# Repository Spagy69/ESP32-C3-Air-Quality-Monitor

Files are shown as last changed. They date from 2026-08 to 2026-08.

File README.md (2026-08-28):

# ESP32-C3 Air Quality Monitor

Bateriový monitor kvality vzduchu postavený na Seeed XIAO ESP32-C3, běžící na [ESPHome](https://esphome.io/) a integrovaný do Home Assistant. Měří CO₂, teplotu, vlhkost a tlak, s malým OLED displejem pro stav a tlačítkem pro probuzení / trvalé zapnutí.

<p align="center">
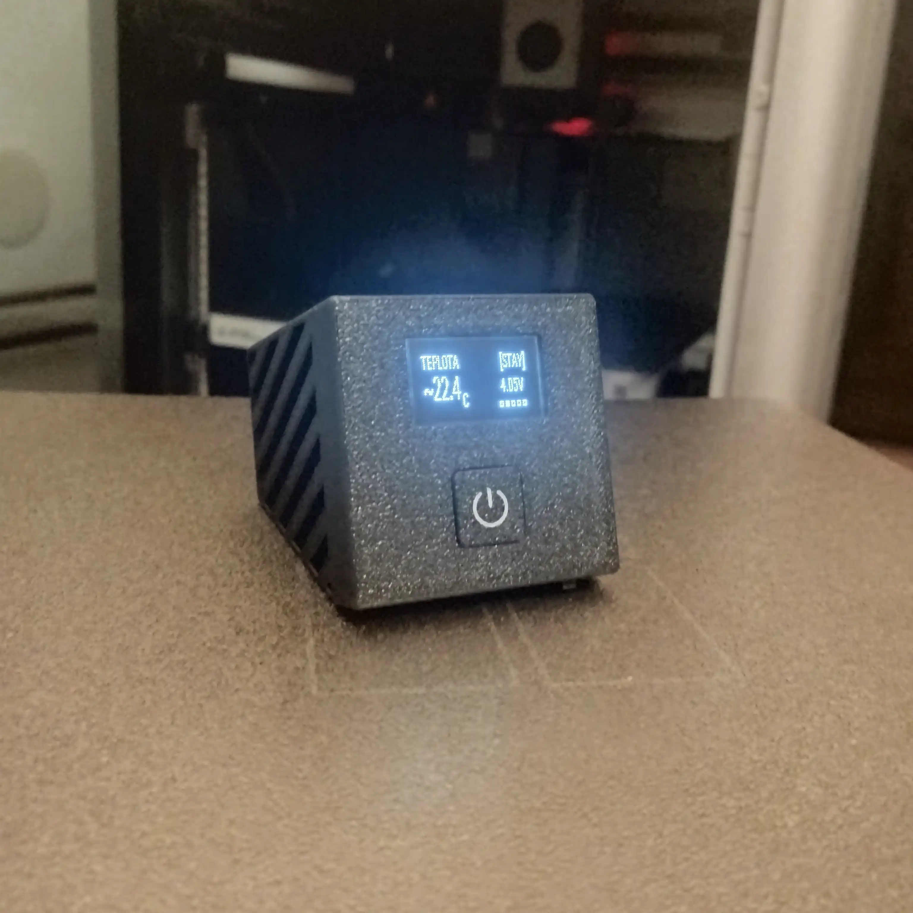
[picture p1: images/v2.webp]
  
</p>

## Funkce

- CO₂, teplota a vlhkost přes Sensirion SCD41
- Sekundární teplota + barometrický tlak přes BMP180
- 128x32 I2C OLED displej, střídá 5 stránek po 3s
- Ovládání tlačítkem: jedno kliknutí probudí displej na 30s, dvojklik přepíná trvalý režim "stay on", drž 5s+ otevře nastavovací menu
- **Nastavovací menu s presety pro dva způsoby použití** (viz [Menu a presety](#menu-a-presety) níže): **DOMA** (na stole, trvale připojeno do HA) a **CESTA** (bez WiFi, hluboký spánek mezi měřeními, lokální CO₂ alarm na displeji)
- **Hluboký spánek** mezi měřeními pro úsporu baterie na cestách, s nastavitelným intervalem (5/10/15/30/60 min) a poslední naměřenou hodnotou uloženou ve flash, takže displej po probuzení/zapnutí hned ukazuje správná čísla, ne "--" nebo staré nesmysly. Při probuzení časovačem **displej zůstává zhasnutý** - zařízení se jen probudí, změří, odešle a jde zase spát. Rozsvítí se jen po stisku tlačítka nebo po zapnutí vypínačem.
- **Lokální CO₂ alarm** - když je zařízení bez HA (např. v autě přes noc) a CO₂ přesáhne bezpečný práh, displej se sám rozsvítí a bliká s varováním
- Sledování napětí/procenta baterky přes odporový dělič, s 30x přeexponovaným (oversampled) čtením ADC pro potlačení šumu
- Detekce nabíjení z pomalého klouzavého trendu napětí baterky (odolná vůči krátkodobé WiFi zátěži), entity `Charging` a `Charging Duration`
- Automatické vypnutí displeje kvůli úspoře baterky
- WiFi záložní AP + captive portal, pokud je nakonfigurovaná síť nedostupná

## Hardware / BOM

| Součástka | Poznámka |
|---|---|
| Seeed XIAO ESP32-C3 | Hlavní MCU |
| Sensirion SCD41 | CO₂ / teplota / vlhkost, I2C adresa `0x62` |
| BMP180 | Teplota / tlak, I2C adresa `0x77` |
| SSD1306 128x32 OLED | I2C adresa `0x3C` |
| LiPo baterie ~500mAh | Napájí zařízení. Recyklovaná z jednorázové vapy, viz sekce Baterie níže |
| TP4056 nabíjecí/ochranný modul (s DW01A + FS8205A) | Mezi XIAO BAT+/BAT- a baterkou, viz sekce Baterie níže |
| Externí flat/nálepková WiFi anténa (u.FL) | Nahrazuje vestavěnou PCB anténu na desce, na kabelu, viz [ASSEMBLY.md](ASSEMBLY.md) |
| Tlačítko | Připojeno na GPIO3 |
| Rezistory 220kΩ + 100kΩ | Dělič napětí baterky (BAT+ → GPIO4 → GND) |
| Rezistory 4.7kΩ x2 | Externí I2C pull-upy na SDA a SCL |
| Hlavní vypínač (v2) | V sérii mezi baterkou a TP4056 modulem - úplné odpojení napájení, viz [WIRING.md](WIRING.md) |
| 3D tištěný kryt (PETG), v2 | Viz [`enclosure/README.md`](enclosure/README.md), postup sestavení v [ASSEMBLY.md](ASSEMBLY.md) |
| Tlačná pružinka 0.4 × 5.10 mm | Pod tlačítko v předním krytu, přestřižená v půlce - viz [ASSEMBLY.md](ASSEMBLY.md) |

## Zapojení

Kompletní GPIO pinout a schéma zapojení viz [WIRING.md](WIRING.md).

## Firmware

Kompletní ESPHome konfigurace je v [`air-quality-monitor.yaml`](air-quality-monitor.yaml). Před nahráním zkopíruj `secrets.yaml.example` do `secrets.yaml` a doplň vlastní WiFi údaje, API encryption klíč a OTA heslo.

```yaml
wifi_ssid: "your-ssid"
wifi_password: "your-password"
api_encryption_key: "base64-key"
ota_password: "your-ota-password"
fallback_ap_password: "your-fallback-password"
```

**Nadmořská výška:** v `air-quality-monitor.yaml` je u SCD41 nastavené `altitude_compensation: 435m`. Tohle je výchozí hodnota nastavená podle mojí konkrétní lokace, ovlivňuje přesnost přepočtu CO₂. Pokud si tenhle config používáš jinde, uprav si tu hodnotu na nadmořskou výšku svýho místa.

## Menu a presety

Podrž tlačítko 5s+ pro vstup do nastavovacího menu. Uvnitř menu:
- **Jedno kliknutí** - další položka (cyklicky)
- **Dvojklik** - odejít z menu beze změny (co už bylo potvrzeno 5s-holdem, zůstává uložené)
- **Drž 5s+** - potvrdit/přepnout aktuální položku

| Položka | Co dělá |
|---|---|
| REZIM | Aplikuje celý preset (DOMA/CESTA) najednou - viz tabulka níže. Pokud se aktuální nastavení neshoduje s žádným presetem (protože jsi něco upravil ručně), zobrazí se CUSTOM. |
| HA PRIPOJENI | Ruční přepínač WiFi/HA připojení. |
| INTERVAL SPANKU | Cykluje presety [5, 10, 15, 30, 60] minut - jak dlouho spí hluboký spánek. |
| DEEP SLEEP | Když zapnuto, JAKÉKOLIV zhasnutí displeje (30s timeout i ruční klik) rovnou uspí celé zařízení místo pouhého zhasnutí. |
| CO2 ALARM | Zapíná/vypíná lokální varování na displeji při vysokém CO2 (viz níže). |
| ASC KALIBRACE | Zapíná/vypíná automatickou self-kalibraci SCD41 (viz Known Issues níže) - **projeví se až po dalším rebootu/probuzení**, ne okamžitě. Součást presetů DOMA/CESTA (viz tabulka níže), ale jde přepnout i ručně zvlášť. |

| Preset | HA PRIPOJENI | DEEP SLEEP | INTERVAL SPANKU | CO2 ALARM | ASC KALIBRACE |
|---|---|---|---|---|---|
| **DOMA** | zapnuto | vypnuto | - | vypnuto | zapnuto |
| **CESTA** | vypnuto | zapnuto | 10 min | zapnuto | vypnuto |

**CO2 ALARM** je pro situace bez HA (typicky CESTA - např. v autě přes noc): pokud CO2 překročí bezpečný práh (aktuálně 3000ppm spuštění / 2700ppm zhasnutí, hystereze proti blikání), displej se sám rozsvítí a bliká s varováním, i kdyby byl předtím zhasnutý/zařízení v hlubokém spánku. Automatické zhasnutí/uspání se dočasně zablokuje, dokud hodnota neklesne zpátky pod práh - manuální klik tlačítka vždy funguje jako potvrzení/odložení.

Alarm se po každém zapnutí/probuzení **neaktivuje hned** - hodnoty po startu můžou být divoké a nemá z nich spouštět planý poplach. Podrobně (včetně toho, proč SCD41 měří po 5s a ne po 60s) viz [Zahřívání po zapnutí](#zahřívání-po-zapnutí) níže.

## Kryt

3D tištěný z **Aurapol PETG** (v1 byl z PLA), tištěno na Bambu Lab X1C s AMS. Zdrojový soubor a tisková nastavení: [`enclosure/README.md`](enclosure/README.md). Postup sestavení viz [ASSEMBLY.md](ASSEMBLY.md).

Ve v2 mají oba teplotní senzory **vlastní kompartment ve spodku krabičky**, oddělený přepážkou od baterky, TP4056 modulu i ESP32 - tedy od všeho, co uvnitř topí. Kompartment se po nalepení senzorů zatavuje záklopkou. Tlačítko má nově **symbol napájení** a natavuje se přímo na přední kryt.

Vícebarevný je jediný díl (přední tlačítko). Kdo nemá AMS, vytiskne ho jednobarevně - ikonka pak zůstane jako reliéf.

## Baterie

Baterie se nenabíjí přímo přes vestavěný nabíjecí obvod XIAO. Mezi XIAO a baterkou je zapojený externí **TP4056 modul**: XIAO BAT+ a BAT- jdou do OUT+ a OUT- na TP4056, a B+ a B- na TP4056 jdou do samotné baterky. TP4056 tak dělá nabíjení místo XIAO desky.

Deska má kromě hlavního TP4056 čipu i DW01A a FS8205A, takže jde o variantu **s ochranou**, ne jen o holou nabíječku. To řeší ochranu proti přebití, podvybití a zkratu. **Empiricky ověřeno (srpen 2026):** při vybití baterky přibližně pod ~2.5V ochrana skutečně sepne a odpojí napájení - v tu chvíli spadne celé zařízení (ESP32 ztratí napájení, protože jde přes stejnou OUT+/OUT- cestu jako dělič napětí baterky - viz [WIRING.md](WIRING.md)). Zařízení se prostě přestane hlásit do HA (offline), nezasílá žádnou špatnou/plovoucí hodnotu - ADC/ESP32 v tu chvíli neběží vůbec.

Za normálního provozu (mimo zásah ochrany) tohle umístění děliče na přesnost ani na detekci nabíjení nemá prakticky žádný vliv - ochranný FET má v sepnutém stavu odpor jen v řádu desítek miliohmů.

Než na to spolehneš dlouhodobě, stojí za to ověřit:
- **Napětí naprázdno a pod zátěží** multimetrem, ať vidíš, jestli se chová jako zdravý článek (viz Known Issues níže pro kalibraci čtení)
- **Fyzický stav článku** (nabobtnání, poškození obalu) před zabudováním do krytu
- **Přítomnost/nepřítomnost ochranného obvodu** - pokud článek nemá vlastní BMS/protection PCB, spoléháš čistě na nabíjecí obvod na XIAO desce

## Notifikace na slabou baterku

Tohle se dělá **ručně v Home Assistantu**, ne ve firmwaru, a je to schválně.
ESPHome by upozornění poslat uměl (`homeassistant.service` volá službu v HA
přímo ze zařízení), ale nic by se tím nezískalo: to volání potřebuje živé API
spojení úplně stejně jako automatizace v HA, takže má tu samou slepou skvrnu -
a navíc by se do firmwaru zadrátoval název služby a práh, který se pak nedá
změnit bez přeflashování.

Automatizace k vložení do HA:

```yaml
automation:
  - alias: "Air Quality Monitor - slabá baterka"
    description: >
      Pod 3.4 V zbývá v režimu DOMA zhruba pět hodin provozu, v uspávaném
      režimu přes dva dny. Ochranný obvod článku vypíná kolem 2.5 V a
      opakované dojíždění až tam článek ničí.
    trigger:
      - platform: numeric_state
        entity_id: sensor.air_quality_monitor_battery_voltage
        below: 3.4
        # Dvě po sobě jdoucí probuzení - v uspávaném režimu chodí hodnota
        # jednou za ~10.4 min, takže tohle je nejkratší smysluplný filtr.
        for: "00:20:00"
    condition:
      # Při nabíjení napětí kolísá a upozornění by nedávalo smysl.
      - condition: state
        entity_id: binary_sensor.air_quality_monitor_charging
        state: "off"
    action:
      - service: notify.notify
        data:
          title: "Air Quality Monitor"
          message: >
            Baterka je na
            {{ states('sensor.air_quality_monitor_battery_voltage') }} V
            ({{ states('sensor.air_quality_monitor_battery_level') }} %).
            Nabij ji.
    mode: single
```

`numeric_state` se spustí jen při **překročení** prahu dolů, takže se to
neopakuje dokola; znovu se to nabije, až napětí vyleze zpátky nad 3.4 V.

**Práh 3.4 V není z katalogu, ale z naměřených rychlostí vybíjení.** V režimu
DOMA klesá napětí o −0.08 V/h, takže do 3.0 V zbývá zhruba **pět hodin** - dost
na to všimnout si a zareagovat. V uspávaném režimu je to −0.0076 V/h, tedy
**přes dva dny**. Detekce se zpozdí o jedno až dvě probuzení, což je při obou
rychlostech zanedbatelné.

### Kde to nefunguje

**V opravdové CESTA vůbec.** Ten preset **vypíná WiFi** (`wifi.disable`
v [`packages/menu.yaml`](packages/menu.yaml)), takže zařízení s Home
Assistantem nemluví a HA o baterce nic neví - ani automatizace, ani volání
služby z firmwaru na tom nic nezmění. Hlídání napětí funguje jen v **DOMA**
nebo v uspávaném režimu s **ručně zapnutým HA připojením** (v menu položka
`HA PŘIPOJENÍ`; tak vznikly všechny záznamy ve [`data/`](data/README.md)).

Pro skutečnou CESTA zbývá jediná spolehlivá cesta: **podívat se na displej**,
kde je stav baterky vedle hodnoty. Firmware na něm ale dnes **slabou baterku
nijak nezvýrazňuje** - ukáže procenta nebo napětí stejným písmem jako při
plné. Lokální varování na displeji je proto otevřený návrh, ne hotová věc.

## Zahřívání po zapnutí

Po zapnutí (hlavní vypínač baterky) nejsou hodnoty hned přesné. Z reálných záznamů ([`data/`](data/README.md)) je vidět, že jsou to **dvě fáze, které spolu nesouvisí**:

| Fáze | Co se děje |
|---|---|
| **0-3 min** | **Chyba samotného SCD41**, ne teplota. Hlásí o ~2 °C víc, vlhkost o ~10-14 % míň. Prokázáno na reálných datech - viz Known Issues. Firmware tahle čtení **zahazuje úplně**, do HA se nedostanou. |
| **3-45 min** | Teprve tady se zahřívá krabička. Teplotní offset platí jen v tepelné rovnováze, takže dokud se box neprohřeje, je hodnota systematicky nízko, i když vypadá stabilně. Datasheet proto žádné číslo nedává, jen říká "in thermal equilibrium". |

Kolik chyby zbývá v které minutě (měřeno na BMP180, který se ustálí kolem 24.15 °C):

| čas | 10 min | 20 min | 30 min | 40 min | 50 min |
|---|---|---|---|---|---|
| chyba | −1.11 °C | −0.58 °C | −0.34 °C | −0.18 °C | −0.06 °C |

Časová konstanta je 13-15 min, ustálení tedy trvá zhruba 3τ.

Firmware to řeší dvěma způsoby:

- **CO₂ alarm se neaktivuje, dokud se hodnoty neuklidní.** Místo pevného čekání sleduje samotná čtení: povolí se, až když jsou 3 čtení po sobě v rozsahu do 150 ppm. Pojistka - pokud se hodnoty neuklidní vůbec, alarm se povolí po 3 minutách tak jako tak (radši hlídat s nejistotou než nehlídat). Jednou povolený se už nevypíná - reálný rychlý nárůst CO₂ v autě by rozptyl překročil a alarm by zmizel přesně ve chvíli, kdy je potřeba.

  SCD41 kvůli tomu měří **po 5s** místo výchozích 60s. Není to kvůli "čerstvějším datům": 5s je vlastní interní vzorkovací rychlost SCD41, takže to nestojí víc energie senzoru, a v režimu CESTA je zařízení vzhůru jen 30s - při pomalejším čtení by na posouzení stability (natož na samotné spuštění alarmu) prostě nezbyl prostor.
- **Prvních 5 čtení SCD41 se zahodí.** Teplota a vlhkost ze SCD41 se první 3 minuty po každém bootu vůbec nepublikují ani neukládají do cache. Není to opatrnost - je to oprava reálného problému, kdy si HA po vybití baterky uložilo jako poslední teplotu hodnotu, která nikdy nebyla naměřená (viz Known Issues).
- **Vlnovka.** `~` před hodnotou (`~25.1 C`) znamená jednu jedinou věc: **tohle není čerstvé, důvěryhodné čtení**. Objeví se ve třech případech - prvních **45 min po studeném startu** (zahřívá se krabička), **po celou dobu nabíjení** (to je ve skutečnosti ten největší vliv, až +3.7 °C - viz Known Issues), a když se hodnota musela vzít z **uložené cache**, protože živé čtení není k dispozici. **Čtvrtý případ přibyl v srpnu 2026: okno chladnutí.** Když se do uspávaného režimu přepne rozběhnutá (a tedy nahřátá) krabička, trvá **~2.5 h**, než se ustálí na okolní teplotě - a po tu dobu je hodnota označená. Když se přepne krabička, co se ohřát nestihla (zapneš ji vypínačem a hned přepneš preset), vlnovka se neukáže vůbec.
- **Teplota se v režimu s deep sleepem bere z BMP180.** Hlavní stránka TEPLOTA zkusí popořadě SCD41 → BMP180 → cache a vezme první, co má živou hodnotu. V normálním provozu to je SCD41; jakmile se ale zapne uspávání, jeho čtení se zahazují (viz Known Issues) a stránka automaticky ukáže BMP180, který startovní skok nemá. Není v tom žádné větvení podle režimu - prostě se použije nejlepší dostupný zdroj, takže to funguje i v prvních 3 minutách běžného zapnutí. **Vlhkost druhý zdroj nemá** (BMP180 ji neměří), takže v režimu s uspáváním ukazuje cache a je označená vlnovkou. To je poctivá odpověď: za 30 s vzhůru se platná vlhkost změřit nedá.

**Po probuzení z deep sleepu se vlnovka nezobrazí, pokud krabička nechladne** - a to je záměr celý. Že se krabička nemusí znovu zahřívat, platí: ve spánku se ustálí na okolní teplotě, a od srpna 2026 se jí tam už neodečítá klidový offset, který tam nepatří (viz Known Issues). Chladnutí po přepnutí z nepřetržitého provozu do spánku pokrývá to okno 2.5 h výš. Označené tedy zůstává jen to, co opravdu důvěryhodné není.

> Těch 45 min je změřené, ne odhadnuté. Předchozí hodnota 20 min pocházela z extrapolace záznamu, který se ukázal být teplý restart - fitovat exponenciálu na krátký, skoro ustálený ocas dalo časovou konstantu necelou polovinu skutečné, a odhad tím pádem přestřelil o víc než dvojnásobek.

## Přesnost

Kolik se tomu dá věřit. Rozlišuj dvě různé věci - **krátkodobou stabilitu** (o kolik se hodnota změnila) a **absolutní přesnost** (jestli je to opravdu tolik). Ta první je o řád lepší.

| Veličina | Krátkodobě (změřeno) | Absolutně | Co to omezuje |
|---|---|---|---|
| **Teplota** | ±0.05 °C | **±0.5 °C** | referenční teploměr, ne senzor |
| **Vlhkost** | ±0.15 % | **neověřeno** | není čím změřit |
| **CO₂** | ±2 ppm | ±(40 ppm + 5 %), tj. ~±190 ppm při 3000 | katalogový údaj, neověřeno |
| **Tlak** | ±0.07 hPa | **neověřeno** | není čím změřit |
| **Napětí baterky** | ±0.02 V | ověřeno ve **dvou bodech** (4.15 a 3.81 V) | spodek rozsahu neproměřený |
| **Procenta baterky** | - | **jen orientační** | lineární převod, LiPo se tak nechová; horní konec (4.12 V = 100 %) je změřený |

### Tři věci, které je fér říct nahlas

**1. Zařízení nemůže být přesnější než reference, kterou se kalibrovalo.** Offsety jsou nastavené proti staršímu lihovému teploměru s modrou kapalinou, jehož vlastní tolerance je u tohohle typu tak **±1 °C** (a stupnice bývá po celých stupních, takže desetina je odhad mezi ryskami). Ty tři odečty vyšly shodně (23.9), takže *opakovatelnost* odečtu byla dobrá - ale jestli ten teploměr sám neukazuje o půl stupně vedle, se z ničeho nedozvíme. Těch ±0.5 °C je strop daný referencí, ne senzory.

**2. Shoda obou senzorů už není nezávislý důkaz.** Dřív se dalo argumentovat, že SCD41 a BMP180 se shodnou na 0.35 °C, i když mají úplně jiné offsety. Jenže **teď jsou oba kalibrované proti tomu samému teploměru**, takže když je ten vedle o 0.7 °C, jsou vedle oba stejně. Ta shoda je konzistence, ne správnost.

**3. Vlhkost je nejslabší číslo v celém zařízení.** Nikdy se neověřovala - vlhkoměr jako reference není. A veze se na teplotě: SCD41 počítá RH ze své vlastní teploty, takže **chyba 1 °C v teplotě znamená asi 4 procentní body v vlhkosti** (ověřeno na reálných datech přes Magnusův vztah). Poslední překalibrování teploty ji posunulo asi o 4 body nahoru a nemáme jak potvrdit, že správně.

### Kdy je to horší, než říká tabulka

Tyhle stavy firmware **označuje vlnovkou** `~`, takže se nedají splést s normálním provozem:

| Situace | Chyba teploty |
|---|---|
| Při nabíjení z prázdné baterky | až **+3.7 °C** (neopravuje se, viz Known Issues) |
| Při dobíjení z ~64 % | až **+2.35 °C** (tentýž jev, menší proud) |
| Prvních 10 min po studeném startu | **−1.1 °C** |
| Prvních 30 min | −0.34 °C |
| Prvních 45 min | −0.06 °C |
| V režimu s uspáváním | **−0.90 / −0.94 °C** (dva záznamy po opravě; před ní −3.55) |

Ta poslední řádka je od srpna 2026 změřená a **z velké části opravená**. Offsety byly změřené pro nepřetržitý provoz, kde se krabička zahřívá pořád; v uspávaném režimu je zařízení vzhůru 4 % času, takže se odečítalo teplo, které tam není. Firmware ho tam už neodečítá. Změřeno třikrát proti referenčnímu teploměru: **−3.55 °C** před opravou přes noc ([`data/2026-08-23-cesta-baseline/`](data/README.md)) a po ní **−0.90 °C** ([`data/2026-08-23-cesta-po-oprave/`](data/README.md)) a **−0.94 °C** ([`data/2026-08-28-cesta-nabijeni-a-chladnuti/`](data/README.md)) - tedy ne odhad, ale tři měření na tom samém hardwaru. **Zbytek zavřený není**: −0.9 je pořád dvojnásobek deklarované ±0.5 °C. Nově ale víme, že je **reprodukovatelný**, takže další odečty tím samým teploměrem už nic nerozhodnou - rozhodne až druhý teploměr, nebo prohození míst krabičky a teploměru. Podrobně v Known Issues níž.

Pátý stav, který tabulka nemá, protože se neopravuje ale označuje: **krabička přenesená rozběhnutá do uspávaného režimu** chladne ~2.5 h a po tu dobu čte výš (na začátku až +6 °C). Firmware na ni po celé to okno drží vlnovku.

### Co by přesnost zvedlo

- **Lepší teplotní reference** (kalibrovaný teploměr, nebo směs ledu a vody jako pevný bod) - zvedlo by strop z ±0.5 °C
- **Druhý CO₂ metr** vedle - jediný způsob, jak ověřit CO₂ a hlídat drift ASC
- **Multimetr ve 2-3 dalších bodech napětí** (~3.5 a ~3.8 V) - dodělalo by dělič
- **Vybíjecí křivka místo lineárního převodu** - opravilo by procenta baterky

### Pro co to stačí tak jak to je

Pro obě zamýšlená použití ano. Sledování pokoje v HA potřebuje hlavně spolehlivé **změny**, a ty sedí na ±0.05 °C. A pro CO₂ alarm v autě je ±190 ppm při prahu 3000 ppm úplně jedno - rozdíl mezi „vzduch je v pohodě" a „dusíš se" jsou tisíce ppm, ne stovky.

## Naměřená data

Skoro každé konkrétní číslo v tomhle README (i většina konstant ve firmwaru) pochází z reálného měření, ne z odhadu. Syrové exporty z Home Assistant History jsou ve složce [`data/`](data/README.md) i s popisem, za jakých podmínek každý záznam vznikl a co z něj vyšlo - včetně toho, co ještě chybí změřit.

## Known Issues

- **Napětí/procento baterky není přesné.** Čtení teď vychází o pár procent výš než multimetr (~+2.6 % pozorováno zatím). Hodnoty děliče a čtení ADC jsou principiálně správně, ale přesný multiplikátor ještě nebyl pořádně zkalibrovaný napříč celým rozsahem napětí. Ber procenta baterky jako orientační, ne přesný údaj.
- **Riziko driftu CO₂ auto-kalibrace (ASC) - teď vypínatelné v menu (srpen 2026).** `automatic_self_calibration` je na SCD41 defaultně zapnutá. ASC předpokládá, že senzor pravidelně vidí čerstvý venkovní vzduch (~400ppm) a podle toho si upravuje baseline (klouzavé okno v řádu dní - jedna špatně větraná noc v autě sama o sobě baseline výrazně neurve, okno je navržené přesně proti tomuhle). Pokud senzor sedí dlouhodobě v prostoru, co se málokdy pořádně vyvětrá, ASC si může posunout baseline vůči špatné referenci a časem podhodnocovat CO₂. Nová menu položka **ASC KALIBRACE** (viz Menu a presety výš) jde vypnout/zapnout ručně, např. před cestou - **projeví se až po dalším rebootu/probuzení** zařízení, protože ESPHome umí ASC nastavit jen při startu, ne za běhu; přepnutí v menu proto jen uloží preferenci, kterou firmware aplikuje přes raw I2C příkaz (SCD4x `0x2416`) při příštím bootu. Implementováno bez `persist_settings` (SCD41 vlastní NVM) záměrně - firmware si nastavení pamatuje samo (ESP32 flash) a při každém bootu ho podle potřeby znovu vynutí, takže NVM senzoru se zbytečně neopotřebovává opakovaným zápisem.
- **Detekce nabíjení měla vážný bug, teď opravený a ověřený z obou stran (srpen 2026).** Původní debounce fix (proti false-positive z WiFi zátěže) byl nastavený na příliš vysoký práh - v reálném testu se `Charging` nespustilo ani jednou za celý 2.5h nabíjecí cyklus. Opraveno použitím pomalého klouzavého baseline napětí (časová konstanta ~10min) místo trendu z jednoho vzorku, s nižším prahem (0.015V/-0.01V). Ověřeno v praxi při reálném nabíjení, a od té doby i **proti hodinovému záznamu vybíjení** (`data/2026-08-22-doma-baseline/`): `Charging` zůstalo celou dobu vypnuté a simulace algoritmu nad těmi daty dala maximální trend **-0.0003 V** proti prahu +0.015 V, tedy žádné falešné sepnutí ani zdaleka.
- **Při nabíjení je teplota až o 3.7 °C vyšší než realita a firmware to záměrně neopravuje.** Změřeno proti referenčnímu teploměru přes celý nabíjecí cyklus z prázdné baterky ([`data/2026-08-22-charging-from-empty/`](data/README.md)): ve vrcholu CC fáze (~40 min od zapojení) byla krabička **+3.7 °C** nad svým ustáleným stavem, drželo se to ~30 min a pak to během ~1.5 h kleslo zpátky na nulu, jak nabíjecí proud dobíhal. Stejný tvar na obou senzorech, takže se ohřívá celá krabička. **Konstanta to opravit nemůže:** teplo je úměrné nabíjecímu proudu, a ten závisí na tom, jak prázdná baterka byla - z nuly dostaneš hodinu plného proudu, dobití z 90 % skoro nic. Jedno číslo by muselo být vedle až o ±3.7 °C podle situace. Křivka podle času selže stejně - to zkoušela v1 a v terénu přestřelila o ~4 °C. Firmware proto `CHARGE_OFFSET_*` nechává na `0.0`, publikuje `Charging` do HA (kde se dá filtrovat) a na displeji dává během nabíjení před teplotu `~`.

  **Druhý a třetí záznam to potvrdily přímo.** V [`data/2026-08-23-charging-warm/`](data/README.md) se nabíjelo ze 64 % s krabičkou už ustálenou - a vrchol vyšel jen **+2.35 °C** (ve 28 min) proti +3.7 °C z prázdné. Opačný extrém přidal [`data/2026-08-28-cesta-nabijeni-a-chladnuti/`](data/README.md): z baterky dojeté až do vypnutí je vrchol **+4.12 °C**. Celé rozpětí je tedy 1.8 °C podle jediné proměnné - jak plná baterka na začátku byla. Stejná krabička, stejná nabíječka, stejná místnost; celý rozdíl 1.4 °C dělá jen to, jak plná baterka na začátku byla. Argument výš tím přestává být úvahou a stává se změřeným faktem. Vidět je i tvar: **je to hrb, ne schod** - po 28 min teplota sama klesá a v 62. minutě je zpátky na +1.37 °C, pořád se zapojenou nabíječkou.
- ~~`Charging` nepozná konec nabíjení~~ **opraveno (srpen 2026), a pak opraveno znovu.** Ve stejném záznamu sepnulo správně 5 min po zapojení, ale vyplo se až přesně po 3 h - což byl bezpečnostní timeout, ne detekce; skutečné nabíjení skončilo o hodinu dřív. Trendové pravidlo to vidět nemohlo, protože pokles napětí po dobití je jen ~0.0009 V/min a nikdy nepřekročí práh −0.01 V. Přidáno proto druhé pravidlo hledající opačný podpis: **napětí vysoko a přestalo se hýbat.**

  První verze toho pravidla (≥ 4.10 V, změna pod 0.001 V, 5× za sebou) byla ale naladěná **na jediný záznam** a druhý ji shodil. V [`data/2026-08-23-charging-warm/`](data/README.md) (dobíjení ze 64 % s už ustálenou krabičkou) se napětí po dokončení usadilo na **4.083 V**, tedy pod prahem 4.10 - pravidlo **nesepnulo ani jednou** a `Charging` viselo celý záznam. Důvod: obě nabíjení skončila na jiném napětí, 4.120 a 4.083 V, 37 mV od sebe na stejném hardwaru. **Absolutní hladina nic negeneralizuje, generalizuje jen plochost.** `FULL_V` je proto teď jen volná pojistka (4.05 V, aby nabíjení zaseknuté na 3.5 V nešlo splést s hotovým) a rozhoduje tolerance plochosti, zvednutá 0.001 → 0.002 V, protože zdejší plató má kroky až 0.0019 V. Nové prahy sepnou správně na **obou** záznamech (18:19 / +125 min a 01:07 / +48 min) a nesedí na hraně: `FULL_V` kdekoliv mezi 4.00-4.08 i počet potvrzení 4-10 dají shodný výsledek. Kdyby byly na jinou baterku pořád moc těsné, pravidlo prostě nesepne a převezme to 3hodinová pojistka - horší, ne rozbité.

- ~~Plně nabitá baterka ukazovala 90 %~~ **opraveno (srpen 2026).** Procenta se počítala lineárně z 3.0-4.2 V, jenže naměřené plno je 4.083-4.120 V - dobitá baterka tedy hlásila 90-93 % a **100 % nešlo dosáhnout nikdy**, což vypadá jako porucha. Horní konec mapy se proto vzal z měření (4.12 V) místo z katalogu. Otevřené zůstává, jestli článek opravdu končí na 4.12 V, nebo jestli dělič podhodnocuje skutečných 4.2 V o ~2 % - na procenta to ale nemá vliv, protože se teď berou z toho, co ADC reálně hlásí při dobití. Že jde pořád jen o **lineární** převod (a LiPo se tak nechová) platí dál, viz bod o přesnosti děliče výš.
- **SCD41 hlásí první ~2 minuty po startu měření o několik °C víc (potvrzeno, ošetřeno).** Není to zahřívání krabičky, je to chování samotného senzoru. Dokázáno dvěma nezávislými způsoby ze záznamu [`data/2026-08-22-cold-start/`](data/README.md): (a) ze **studeného** startu hlásí SCD41 v 6. vteřině o 2.13 °C **víc** než BMP180, ve 2. minutě je naopak pod ním, a pak se srovnají - studený čip nemůže hlásit vysoko; (b) při **brownout restartu** umírající baterky skočil z 24.04 na **28.42 °C za necelých 38 s**, zatímco BMP180 stál na 23.58 - reálná změna o 4.4 °C při klidném druhém senzoru je nemožná. Za celých 6.5 h záznamu jsou skoky nad 1 °C přesně dva a oba sedí na restart. **Ošetřeno:** teplota a vlhkost SCD41 se první 3 min po bootu zahazují (viz [Zahřívání po zapnutí](#zahřívání-po-zapnutí)).
- **A opakuje se to při KAŽDÉM probuzení z deep sleepu - v CESTA je proto teplota ze SCD41 nepoužitelná.** Ověřeno devíti cykly probuzení ([`data/2026-08-22-cesta-wake-cycles/`](data/README.md)): pokaždé startuje SCD41 **~5.5 °C nad** BMP180 a za 10 s spadne o 0.72-0.76 °C. Rozptyl přes všech devět probuzení je 5.36 až 5.59 °C, tedy naprosto konzistentní. Když přitom zařízení běželo v kuse, rozdíl byl normálních 0.31 °C. Vlhkost jde s tím: 61.8 % za běhu, 46.7-50.6 % při probuzení. BMP180 přitom klesá hladce a **skok nemá vůbec**. Vysvětlení, které sedí na všechna tři měření: první čtení po `start_periodic_measurement` vypadá, jako by na něj ještě nebyl aplikovaný `temperature_offset`, a ten se dotáhne během ~2 min - při studeném startu je čip stejně studený jako krabička, takže chybějící offset dělá jen ~2 °C, kdežto ve spánku čip běží dál a je proti chladnoucí krabičce rozehřátý, takže totéž dělá ~5.5 °C. Prakticky: 30 s vzhůru je řádově míň, než těch 2 min. Firmware ta čtení zahazuje, takže se do HA nedostane nesmysl, a **displej v takovém režimu bere teplotu z BMP180** (viz [Zahřívání po zapnutí](#zahřívání-po-zapnutí)). V Home Assistantu je potřeba na to myslet ručně: entita `Temperature (SCD41)` se v režimu s uspáváním přestane aktualizovat, použij `Temperature (BMP180)`. Vlhkost druhý zdroj nemá a v takovém režimu se změřit nedá.
- **Po vybití baterky zůstane v HA viset hodnota, která nebyla naměřená (opraveno).** Když baterka došla ([`data/2026-08-22-cold-start/`](data/README.md)), zařízení se cestou dolů dvakrát brownout-restartovalo a pokaždé stihlo publikovat transient ze SCD41. Poslední, co HA dostalo a pak na tom zůstalo viset, bylo **27.43 °C** (realita 23.58) a **53.7 %** vlhkosti (předtím 64.96). Navíc to vypadalo jako dvě měření, i když bylo jen jedno: po krátkém výpadku spojení poslalo ESPHome ty samé stavy z RAM znovu a HA je zalogovalo jako změnu, protože entita mezitím byla `unavailable`. Poznat se to dá podle **bit-identických** floatů. Opraveno tím zahazováním prvních 3 minut - transient se do HA vůbec nedostane a poslední zapamatovaná hodnota tak zůstane ta poslední skutečně naměřená.
- ~~V uspávaném režimu je teplota o 3.55 °C pod realitou~~ **z velké části opraveno (srpen 2026).** Předpověď z minula ("stejný offset tam nejspíš odečítá víc, než by měl") seděla, a teď má číslo. Přes noc v uspávaném režimu s intervalem 10 min ([`data/2026-08-23-cesta-baseline/`](data/README.md), 12.4 h) drží BMP180 posledních pět hodin naprosto klidně **18.955 °C ± 0.043**, zatímco referenční teploměr vedle hlásí **22.5 °C**. Publikovaná chyba je tedy **−3.55 °C**; syrové čtení senzoru (tj. +2.46 zpátky) je na 21.415, tedy −1.09 °C.

  **Příčina je jednoznačná.** `REST_OFFSET_BMP180 = 2.46` se odečítá bezpodmínečně, ale změřený byl v **DOMA**, kde zařízení běží nepřetržitě a krabička se od sebe sama trvale hřeje. V uspávaném režimu je vzhůru **26 s ze 626** (4.2 % času) a BMP180 se čte ~3 s po bootu - tedy ve stavu, do kterého se krabička dostala za 10 min spánku, prakticky v rovnováze s okolím. Není tam co odečítat. Totéž se principiálně týká i `temperature_offset: 6.7°C` uvnitř SCD41, jen to není vidět, protože ze SCD41 v tom režimu nepřijde vůbec nic (bod výš).

  **Zbytek proti syrovému čtení otevřený zůstává** - může to být vlastní chyba BMP180 (datasheet ±1 °C), chyba teploměru (±0.5 °C), nebo skutečný rozdíl mezi místem krabičky a místem teploměru. Na novou konstantu to nestačí: klidový offset v DOMA se dělal ze **tří** odečtů po pěti minutách plus dvou kontrol platnosti a stejný protokol chce i tenhle.

  **Oprava:** klidový offset se odečítá jen tehdy, když je `cold_boot` pravdivé, tedy když tenhle boot **není** probuzení ze spánku. Klíčem je fyzická historie, ne nastavení režimu - stejná úvaha, podle jaké si displej vybírá zdroj teploty. Nulu nebylo potřeba měřit, plyne z duty cyklu; kontrola řádu: 2.46 °C při ~34 mA a 4 V dává ~18 K/W, takže ~0.3 mA klidového odběru ve spánku odpovídá ~0.02 °C.

  **Ověřeno na železe** ([`data/2026-08-23-cesta-po-oprave/`](data/README.md), 2.8 h, 16 probuzení): skok je vidět přímo v datech, protože flash boot je ještě `cold_boot` a odečítá - 19.746 °C v 17:40, **22.421 °C při prvním probuzení ze spánku**, tedy +2.676 proti konstantě 2.46 (zbytek je skutečný drift za těch 10 min). Proti referenčnímu teploměru ve třech bodech **−0.90 °C** (sd 0.18) tam, kde ta samá data bez opravy dávají −3.36.

  **Zbytek tím ale opravený není.** Druhý záznam ([`data/2026-08-28-cesta-nabijeni-a-chladnuti/`](data/README.md)) dal **−0.94 °C** se směrodatnou odchylkou 0.02, s krabičkou prokazatelně ustálenou (rozptyl 0.043 °C přes hodinu). Dva nezávislé záznamy, jiný den, jiný stav baterky - zbytková chyba je tedy **reprodukovatelná**, ne šum.

  **A protože je reference pořád ten samý teploměr jako při kalibraci offsetů, dá se z toho dopočítat, co ta konstanta 2.46 doopravdy je.** Nastavená byla jako `raw − teploměr` v režimu DOMA, takže tam zařízení sedí na teploměr *z definice*. V uspávaném režimu se neodečítá a self-heating tam podle duty cyklu není. Odečtením obou vztahů vypadne chyba teploměru i chyba senzoru a zbude **skutečné self-heating 3.40 °C** - číslo nezávislé na tom, jak přesná ta reference je. Konstanta 2.46 tedy nikdy nebyla čisté self-heating, ale **rozdíl** ohřevu 3.40 a vlastní chyby BMP180 −0.94.

  **Praktický důsledek: DOMA čte o 0.94 °C výš než uspávaný režim** ve stejné místnosti. To je fakt o zařízení, ne o teploměru. Který z těch dvou režimů je ten správný, rozhodnuté **není**: když je přesný teploměr, čte BMP180 nízko a správně je DOMA; když je přesný senzor, ukazuje teploměr vysoko a správně je uspávaný režim. Obojí sedí do tolerancí (BMP180 ±1 °C, teploměr ±1 °C) a **dalšími odečty tím samým teploměrem se to rozhodnout nedá** - jeho chyba se z nich nevydělí. Rozhodne druhý referenční teploměr, nebo prohození míst krabičky a teploměru: to musí otočit znaménko.

  Displej tenhle stav označuje: po přepnutí nahřáté krabičky do uspávaného režimu drží vlnovku po dobu okna chladnutí (150 min, viz níž).

- ~~V uspávaném režimu nefunguje žádný filtr, který potřebuje historii~~ **opraveno (srpen 2026).** Deep sleep je **plný reboot**: každé probuzení začíná od nuly a trvá ~26 s. Při `update_interval: 60s` z toho plyne, že BMP180, tlak i `battery_voltage` stihnou za probuzení právě **jedno** čtení - a všechno, co se počítá z několika za sebou, tak nemá z čeho počítat.

  Vidět je to přímo v datech ([`data/2026-08-23-cesta-baseline/`](data/README.md)): ve 14:43:48 publikovalo BMP180 **18.028 °C** mezi sousedy 18.911 a 18.917. Přesně ten typ jednoho špatného I2C čtení, proti kterému byl přidán `median` filtr (okno 3) - a přesto prošel, protože se `send_first_at: 1` vydá medián z jednovzorkového okna, což je ten vzorek sám.

  Stejný mechanismus platil i pro medián ze 3 u `battery_voltage` a hlavně pro **detekci nabíjení**: `batt_v_slow_avg`, `charge_confirm_count`, `full_confirm_count` i `is_charging` byly všechny `restore_value: false`, takže klouzavý průměr s časovou konstantou ~10 min dostal za probuzení jeden vzorek a pak se zahodil - **`Charging` v uspávaném režimu nemohlo sepnout nikdy.**

  **Opraveno třemi různými způsoby, podle toho, co který senzor potřebuje.** U BMP180 a tlaku stačilo **zrychlit polling na 5 s**: za probuzení pak dorazí ~5 čtení, okno mediánu se naplní a filtr funguje uvnitř jednoho bootu, bez jakéhokoliv trvalého stavu. U napětí se historie mediánu **ukládá do flash**, protože ta se stejně potřebuje pro detekci nabíjení. A detekce nabíjení dostala v uspávaném režimu **vlastní, jednodušší pravidlo**: krok napětí proti minulému probuzení. Nabíjení přidá ~+40 mV za deset minut, vybíjení ubere ~1.3 mV, a medián drží šum na 2.16 mV - odstup je tak velký, že to nepotřebuje ani klouzavý průměr, ani potvrzování na sepnutí.

  Vedlejší efekt, který stojí za zmínku: **ve spánku odpadá celý problém s koncem nabíjení.** Heuristika „vysoko a plocho" (`FULL_V`) existuje proto, že klouzavý průměr má mrtvou zónu - konstantní napětí dá trend 0, což je mezi prahy. Krok mrtvou zónu nemá: konstantní napětí dá krok 0, tedy pod uvolňovacím prahem, a příznak spadne sám.

  Nový stav, který musí přežít spánek a **nesmí** přežít vypnutí, je vyřešený flash globály plus vynulováním v `on_boot`, kdykoliv boot není probuzení ze spánku. Bez toho by se `is_charging` po týdnu na polici probudilo jako `true`.

  Prahy nejsou od oka. `data/threshold-sweep.py` pouští pravidlo přes obě nabíjecí sady podvzorkované na 10 min i přes noční záznam jako regresi: práh sepnutí dává **identický výsledek od +12 do +30 mV** a nula falešných sepnutí za 72 probuzení, takže +20 nesedí na hraně; uvolnění `+5 mV` osciluje, `< 0` ne; a ze tří variant počtu potvrzení trefí konec nabíjení na dvě minuty jen trojka.

  **Ověřeno na železe** ([`data/2026-08-23-cesta-po-oprave/`](data/README.md)): šestnáct hodnot BMP180 tvoří monotónně klesající řadu bez jediné výjimky, největší skok mezi probuzeními **−0.092 °C** proti −0.886 před opravou. Rozptyl kroku napětí spadl z **8.02 mV na 1.45** (spec předpovídal 2.16), takže největší pozorovaný kladný krok je +2.45 mV proti prahu +20 - **osminásobná rezerva a nula falešných sepnutí za 11 kroků**. **A že příznak sepne, když se nabíječka opravdu připojí, je od 28. 8. taky ověřené** ([`data/2026-08-28-cesta-nabijeni-a-chladnuti/`](data/README.md)): sepnulo za **13 min**, na prvním probuzení, kde to pravidlo vůbec spočítat mohlo, krokem +43.6 mV. Nejmenší krok za celé nabíjení byl 35 mV, tedy 1.75× nad prahem i na dobíhajícím proudu, a vypnulo 41 min po odpojení. Práh +20 mV je tím ohraničený z obou stran.

- ~~`Battery Level` chybí ve 29 % probuzení~~ **opraveno (srpen 2026).** V nočním záznamu je `unknown` ve **21 ze 72** probuzení. Komentář v kódu přitom tvrdí, že nastat nemá ("the voltage sensor is registered first and runs first on a shared 60s tick") - nastává skoro v třetině případů. Obě šablony mají `update_interval: 60s` a ESPHome plánuje první běh intervalu na `now + náhodný offset v [0, 5 s)` (`Scheduler::calculate_interval_offset_`), a to **nezávisle pro každou komponentu**. Když padne `battery_level` dřív než `battery_voltage`, uplatní se pojistka `if (!id(battery_voltage).has_state()) return {};`, nepublikuje se nic - a protože je zařízení vzhůru jen ~26 s, **druhá šance v tom probuzení nepřijde**. Displej tím netrpí (`cached_battery_pct` je flash-backed), postižená je řada v Home Assistantu. **Opraveno přesně takhle:** procenta se počítají na konci lambdy `battery_voltage` a publikují přes `publish_state()`, šablona `Battery Level` přišla o vlastní tik i o pojistku `has_state()`. Závod tím mizí konstrukcí - napětí je v scope, takže není na co být brzo. **Ověřeno na železe** ([`data/2026-08-23-cesta-po-oprave/`](data/README.md)): **0 `unknown` za 16 probuzení** proti 22 z 64 řádků v nočním záznamu. Že řádků je jen 12, výpadek není - HA zapisuje jen změny a pětkrát se hodnota bit-identicky zopakovala, což je podpis mediánu, který teď opravdu běží.
- **BMP180 občas pustí jedno úplně vedlejší čtení (opraveno, srpen 2026).** V hodinovém záznamu (`data/2026-08-22-doma-baseline/`, 01:56:54Z) spadla teplota na 24.41 °C mezi sousedy ~24.70 °C - a **stejné čtení** zároveň ukázalo tlak 956.41 hPa proti sousedním ~957.05 hPa. Jde tedy o jedno špatné I2C čtení, ne o šum na jednom kanálu. BMP180 do té doby neměl žádný filtr, takže se ta hodnota propsala do HA, na displej i do cache. Přidán `median` filtr (okno 3) na teplotu i tlak, zapojený **před** korekční lambdu, aby se čistila i cachovaná hodnota. Dlouho to ale platilo **jen v nepřetržitém provozu**: v uspávaném režimu začínalo každé probuzení s prázdným oknem, takže v nočním záznamu jeden takový výkyv (−0.886 °C) znovu prošel. Od srpna 2026 čte BMP180 po 5 s místo po 60 s, takže se okno naplní i v ~26s probuzení a filtr funguje v obou režimech.
- **Napětí baterky skákalo nahoru v okamžiku připojení nabíječky - z velké části vyřešeno přepojením v2 (srpen 2026).** Reálný capture (`data/2026-08-21-v1-charger-connect/`) s v1 zapojením (dělič na BAT+/BAT- pinech XIAO, tedy za TP4056 modulem): klidové ~3.72V, hned po zapojení nabíječky skok na ~4.11-4.18V během 1 minuty. Po přepojení horní nohy děliče přímo na B+ baterky (viz [WIRING.md](WIRING.md)) se skok v praxi výrazně zmenšil/zmizel - ukazuje to, že většina toho skoku nebyla čistě vnitřní odpor článku, ale přidaná sériová impedance z trasy/kontaktů TP4056 modulu, kterou nové zapojení obchází. Menší zbytkový skok (čistě z vnitřního odporu článku samotného) je pořád fyzikálně očekávatelný, hlavně u recyklovaného/staršího článku - to není bug.
- **Jednorázové šumové výkyvy v `Battery Voltage` (opraveno, srpen 2026).** Stejný capture ukázal jedno čtení (celá 60s perioda) o ~0.13V níž než sousední - pravděpodobně krátký pokles napájení při WiFi vysílání zasáhl celou dávku 30 oversamplovaných čtení najednou (ta běží v řádu ms po sobě, takže je šum tohohle typu "přeskočí" všechny stejně - oversampling proti němu nepomůže). Medián z posledních 3 čtení se počítá **přímo v lambdě** `battery_voltage` ([`packages/sensors.yaml`](packages/sensors.yaml)), ne jako externí `median` filtr - externí filtr by čistil jen publikovanou hodnotu, zatímco detekce nabíjení by dál viděla syrová čtení (přesně ten bug popsaný o řádek výš). **Potvrzeno funkční** z hodinového záznamu (`data/2026-08-22-doma-baseline/`): ze 64 očekávaných čtení je v HA jen 42 změn, tj. 22× byla publikovaná hodnota bit-identická s předchozí - což je přesně podpis mediánu (znovu vydá dřívější vzorek). U syrového ADC šumu by se float hodnoty takhle neopakovaly. Zbytkový šum je ~0.018 V (≈1.5 % baterky).
- **Dělič sedí ve dvou bodech, 4.15 a 3.81 V (druhý změřený 28. 8. 2026).** Nahoře hlásily HA i multimetr shodně 4.15 V; teď při vybité půlce ukazuje HA **3.81 V** a multimetr **3.81-3.82 V**, tedy shoda v mezích odečtu. Násobič `* 3.2` je tím ověřený přes rozsah 3.81-4.15 V, ne jen v jednom bodě.

  **Tím padá i podezření, že dělič podhodnocuje o ~2 %.** Dvouprocentní chyba by při 3.81 V dělala 76 mV a při 4.15 V 83 mV - obojí by bylo na multimetru vidět na první pohled. Není. **Plná baterka tedy opravdu končí kolem 4.12 V**, není to podhodnocených 4.2 V; horní konec mapy procent je nastavený správně. Starší pozorování o ~+2.6 % odchylce je tím ve dvou bodech vyvrácené a nejspíš pocházelo z jiných podmínek.

  **Podmínky odečtu:** červená sonda na **B+ přímo na baterce**, černá na **GND XIAO** - tedy ten samý uzel a ta samá zem, proti které měří ADC, takže je to srovnání jedna ku jedné a nemíchá se do něj úbytek na trase. Krabička běžela v **CESTA**, ale s **rozsvíceným displejem v režimu STAY**, takže byla vzhůru a pod zátěží; obě čísla jsou tedy z jednoho okamžiku a ze stejného zatížení. **Nabíječka odpojená.**

  **Neproměřený zůstává spodek rozsahu** (~3.5 V a níž). Právě tam by se případná nelinearita ADC projevila nejvíc, a je to zároveň oblast, kde na napětí závisí varování před vybitím.
- **SCD41 běžel i během hlubokého spánku a žral víc než všechno ostatní dohromady (opraveno, srpen 2026).** Senzor není na napájecí větvi ESP32 - 3V3 jde i ve spánku, takže dál měřil po 5 s, i když ho nikdo neposlouchal. Datasheet dává 243 mJ na jedno měření, což při 5s intervalu vychází na **~14.7 mA trvale** proti **0.15 mA** v klidovém režimu - zhruba stokrát víc, a řádově víc než spící ESP32. V datech to je vidět: při 5min intervalu a 30 s vzhůru (desetina času pod proudem) se baterka vybíjela jen o ~15 % pomaleji než při nepřetržitém běhu (−0.070 V/h proti −0.082 až −0.089 V/h). Zpětný výpočet z hodnoty pro nepřetržitý běh dá ~34 mA celkem, což odpovídá ESP s WiFi plus přesně tenhle senzor. Nezávislé potvrzení, že opravdu běžel: teplotní skok při probuzení je ~5.5 °C, mnohem větší než ~2 °C při studeném startu - a takhle rozehřátý být čip nemůže, pokud neměří. **Opraveno** posláním `stop_periodic_measurement` před uspáním, v obou cestách do deep sleepu. Odhad byl 3-4×; **změřeno vyšlo zhruba 9×** - noční záznam ([`data/2026-08-23-cesta-baseline/`](data/README.md), 12.4 h, interval 10 min) dává **−0.0076 V/h** proti −0.070 V/h z `2026-08-22-cesta-wake-cycles/`. Tři výhrady, aby se to číslo nepřecenilo: mezi těmi dvěma záznamy se **zároveň** změnil interval (5 → 10 min, tedy poloviční duty cycle), měřilo se v **jiné části vybíjecí křivky** (V/h se přes ni nedá porovnávat) a starší záznam nezačínal od plné baterky. A **CO2 se po zaparkování spolehlivě rozjede zpátky** - ověřeno ve všech 72 probuzeních té noci, pokaždé ~5 čtení.
- **Rychlé vybíjení v režimu DOMA.** V testu (srpen 2026, ještě na v1 firmwaru bez deep sleepu) baterka klesla ze 4.15V na 2.71V za ~10 hodin běžného provozu. Hodinový v2 záznam v režimu DOMA (`data/2026-08-22-doma-baseline/`) to potvrzuje: **-0.08 V/h** při zapnuté WiFi a vypnutém displeji. Na to je právě preset **CESTA** (deep sleep), a ten je teď taky změřený: přes noc ([`data/2026-08-23-cesta-baseline/`](data/README.md), 12.4 h, interval 10 min, plná baterka) vyšlo **−0.0076 V/h**, tedy **38 % rozpočtu** −0.02 V/h, který si CESTA kladla za cíl. Procenta to potvrzují nezávisle: 100 % → 89.9 % za 12.4 h. Lineárně extrapolováno (**jen řádový odhad**, LiPo křivka lineární není a záznam pokrývá jen úsek 4.15-4.00 V) to je z plné baterky ~4.5 dne do 3.3 V. Měřeno navíc se **zapnutou WiFi**, kterou skutečná CESTA vypíná - reálná spotřeba je tedy ještě o kus nižší. V DOMA se s trvalým provozem na baterku počítat nedá. Hotová automatizace pro Home Assistant i s vysvětlením, proč nepatří do firmwaru a kde nefunguje, je v sekci [Notifikace na slabou baterku](#notifikace-na-slabou-baterku) - opakované dojíždění až k ochrannému cutoffu (~2.5 V, viz sekce Baterie výše) urychluje degradaci článku, obzvlášť u recyklovaného.

## Licence

MIT

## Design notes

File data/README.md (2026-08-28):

# Naměřená data

Syrové exporty z **Home Assistant → History → Download data**. Tyhle záznamy nejsou jen archiv - konkrétní rozhodnutí a opravy ve firmwaru z nich přímo vycházejí, takže je má smysl mít u kódu, ne někde bokem. Kde na ně firmware odkazuje, je to v komentáři u příslušné konstanty/filtru ([`packages/sensors.yaml`](../packages/sensors.yaml)).

## Formát

Každá složka je jedno měření, pojmenované `RRRR-MM-DD-co-se-měřilo` (datum je **UTC**, stejně jako časy v CSV - lokální čas je v létě UTC+2).

Sloupce jsou tak, jak je HA exportuje: `entity_id,state,last_changed`. Export může mít dvě podoby a obě jsou v pořádku:

- **Jeden CSV na veličinu** (`co2.csv`, `temperature-scd41.csv`, …) - pojmenovaný podle veličiny, ne podle entity v HA.
- **Jeden CSV pro všechno** (`all-sensors.csv`) - když se v HA stáhne víc entit najednou; rozlišují se sloupcem `entity_id`.

Cokoliv, co se odečítalo ručně (referenční teploměr, čas cvaknutí vypínače, barva LEDky na nabíječce), patří do `.md` souboru ve stejné složce - v CSV to není a jinak se to nedá obnovit.

Dvě věci, které se při čtení dat vyplatí vědět, jinak z nich vyjdou špatné závěry:

- **HA zapisuje jen změny.** Když senzor pošle dvakrát po sobě identickou hodnotu, druhý řádek v exportu není. Mezery v čase tedy neznamenají výpadek - často znamenají pravý opak (hodnota se vůbec nehnula). U `battery-voltage.csv` je to dokonce užitečný signál: opakovaná bit-identická hodnota je podpis mediánového filtru.
- **`state` může být `unavailable`.** Typicky reboot, OTA flash nebo výpadek WiFi. Při parsování se to musí ošetřit, ne přeskočit potichu.

## Co je v jednotlivých složkách

### `2026-08-21-v1-charger-connect/` - 11 min, v1 zapojení děliče

Krátký záznam napětí, ze kterého vypadly **dvě různé věci najednou**:

- **21:57:44Z: jednorázový šumový výkyv** - 3.7241 → **3.5884** → 3.7235 V. Celá jedna 60s perioda o 0.135 V níž, sousedi v klidu. Kvůli tomuhle vznikl medián-ze-3 v lambdě `battery_voltage`.
- **22:02:44Z: skok při připojení nabíječky** - 3.7203 → **4.1122 V** (+0.39 V) během jedné periody. Tohle bylo ještě se starým zapojením děliče (horní noha na BAT+ pinu XIAO, tedy za TP4056 modulem) a vedlo k přepojení horní nohy přímo na B+ baterky - viz [WIRING.md](../WIRING.md).

### `2026-08-21-v2-charging/` - 23 min, už po přepojení, během nabíjení

Napětí v průběhu nabíjení (ne moment připojení - ten v okně není): plynulý nárůst 3.9775 → 4.0766 V, tj. **~0.004 V/min**. To je přesně to číslo, kvůli kterému detekce nabíjení nemůže fungovat na rozdílu dvou po sobě jdoucích vzorků a musí používat pomalý klouzavý baseline - reálný nárůst je menší než šum jednoho čtení.

Několik `unavailable` řádků = OTA flashe během ladění.

### `2026-08-22-doma-baseline/` - 1 h, režim DOMA, displej vypnutý, bez nabíječky

Referenční záznam ustáleného provozu, všech 7 entit. Slouží jako **baseline** - proti němu se dá porovnávat, jestli nějaká změna něco nerozbila. Co se z něj potvrdilo:

| Zjištění | Číslo |
|---|---|
| Teplota SCD41 je ustálená, bez náběhu | 25.09-25.27 °C celou hodinu |
| Teplotní offsety obou senzorů si odpovídají | rozdíl SCD41 vs BMP180 jen 0.44 °C |
| Detekce nabíjení nedělá false-positive | max trend **-0.0003 V** proti prahu +0.015 V |
| Medián na napětí funguje | 22 ze 64 čtení bit-identických s předchozím |
| Vybíjení v DOMA | **-0.08 V/h** |

A jeden bug: v **01:56:54Z** pustil BMP180 jedno úplně vedlejší čtení - teplota 24.409 °C mezi sousedy ~24.70 °C **a zároveň** tlak 956.407 hPa proti ~957.05 hPa. Obě veličiny naráz z jedné špatné I2C konverze. Kvůli tomu má BMP180 teď `median` filtr.

> Pozor: tenhle záznam začíná **až po** tepelném ustálení, takže se z něj nedá zjistit, jak dlouho zahřívání po studeném startu trvá.

### `2026-08-22-power-on-warmup/` - 26 min od zapnutí vypínačem

Záznam pořízený kvůli otázce "jak dlouho po zapnutí trvá, než jsou hodnoty přesné". **Není to studený start** - zařízení bylo vypnuté jen pár minut, což se v datech i pozná: BMP180 vyrostl celkem o 0.37 °C, ale jeho klidový offset je 1.74 °C, takže vychladlý box by musel vyrůst zhruba o těch 1.74. Naměřené doby ustálení jsou proto **spodní mez**.

Boot je vidět jako `unavailable` → `unknown` → první hodnota (02:46:00-02:46:11Z).

Křivka má **dvě fáze**, které spolu nesouvisí:

| fáze | co se děje |
|---|---|
| **0-1.5 min** | SCD41 hlásí **+2.5 °C nad plató** (27.5 vs 25.0), vlhkost **-14 %**, CO2 +56 ppm. Prudce klesá. |
| **1.5-3 min** | Projde správnou hodnotou a **podstřelí o 0.5 °C** dolů. |
| **3-15 min** | Teprve tady se zahřívá krabička - plynulý návrat nahoru, τ ≈ 3.1 min (SCD41) / 5.9 min (BMP180). |

Doby ustálení (odchylka od finální hodnoty): SCD41 do ±0.1 °C od **12.0 min**, BMP180 od **9.0 min**, vlhkost do ±0.5 % od **10.9 min**, CO2 do ±15 ppm od 14.2 min.

Z τ se dala extrapolovat doba pro opravdu studený start: BMP180 by z plných 1.74 °C potřeboval 20.9 min na ±0.05 °C, a odtud tehdy vzniklo `WARMUP_MS = 20 min`. **Ta extrapolace byla špatně o víc než dvojnásobek** - viz `cold-start` níž, kde vyšlo 45 min. Fitovat exponenciálu na krátký, skoro ustálený ocas dá časovou konstantu necelou polovinu skutečné.

**A jeden nález, který tam nikdo nehledal:** ta úvodní fáze **není tepelná**. Box byl při zapnutí prakticky na provozní teplotě, ale samotný čip SCD41 musel být *chladnější* než za provozu - vlastním teplem se drží několik °C nad vzduchem v krabičce (to kompenzuje `temperature_offset`, tehdy nastavený na 5.6 - čísla v tomhle odstavci z něj vycházejí), takže za běhu sedí kolem 30.6 °C a po pár minutách bez proudu už stihl chladnout. A on přesto hlásil hodnotu odpovídající 33.1 °C. Vychladlý čip nemůže hlásit vyšší teplotu než rozehřátý. BMP180 přitom dělá pravý opak: startuje na svém minimu a roste. Vypadá to tedy na chování samotného SCD41 po startu periodického měření, ne na teplotu okolí. Proč to může být problém pro režim CESTA, je v README v Known Issues - a **zatím to není ověřené**.

Vedlejší produkt: potvrzuje, jak ESPHome plánuje první čtení. BMP180 s 60s intervalem publikoval už ~3 s po bootu, SCD41 s 10s až v 11 s (jeho první poll padl dřív, než měl senzor `data_ready`, a přeskočil se).

### `2026-08-22-cold-start/` - 6.5 h, opravdový studený start až do vybití baterky

Zařízení bylo vypnuté ~1 h, pak zapnuté (boot 04:19:33Z) a necháno běžet na baterku, dokud nedošla. Režim DOMA, displej vypnutý. **Nejcennější záznam v téhle složce** - odpověděl na tři otázky najednou.

#### 1. Zahřívání trvá ~45 min, ne 20

BMP180 se ustálí kolem 24.15 °C (plató od 60. minuty). Zbývající chyba v čase:

| čas | 10 min | 20 min | 30 min | 40 min | 50 min |
|---|---|---|---|---|---|
| chyba | −1.11 °C | −0.58 °C | −0.34 °C | −0.18 °C | −0.06 °C |

Časová konstanta vyšla **13-15 min**, ustálení tedy trvá ~3τ. Odtud `WARMUP_MS = 45 min`.

> Předchozí hodnota 20 min byla extrapolace z `power-on-warmup`, který se ukázal být teplý restart. Fitovat exponenciálu na krátký, skoro ustálený ocas dalo τ = 5.9 min, tedy **necelou polovinu skutečné hodnoty**, a extrapolace tím pádem přestřelila o víc než 2×. Poučení: časová konstanta fitovaná přes krátké okno se nedá extrapolovat.

#### 2. Ten úvodní skok SCD41 je prokazatelně artefakt senzoru

Dva nezávislé důkazy z tohohle jednoho záznamu:

- **Ze studeného startu.** V t=6 s hlásí SCD41 o **2.13 °C víc než BMP180**, ve 2. minutě je naopak **pod ním**, a pak se oba srovnají na normální rozdíl +0.49 °C. Studený čip nemůže hlásit vysoko - kdyby šlo o teplo, musel by startovat nízko a růst.
- **Při brownout restartu.** Jak baterka umírala, zařízení se v 10:45:15Z samo restartovalo a SCD41 skočil z 24.04 na **28.42 °C (+4.37 °C) za necelých 38 s**, zatímco BMP180 stál na 23.60 / 23.59 / 23.58. Reálná změna o 4.4 °C při zcela klidném druhém senzoru je fyzikálně nemožná.

Systematická kontrola celého 6.5h záznamu: skoky SCD41 nad 1 °C jsou **přesně dva** a oba sedí na restart (10:45:15 a 10:50:55). Jinde nic. Rozdíl SCD41−BMP180 drží +0.46 až +0.53 °C celých šest hodin.

#### 3. Proč HA po vybití ukazovalo hodnoty, které nikdy nenaměřilo

Konec záznamu krok po kroku:

| čas | napětí | SCD41 | BMP180 | RH | co se stalo |
|---|---|---|---|---|---|
| 10:50:08 | 3.00 V | 24.008 | 23.588 | 64.96 | poslední **správné** čtení |
| 10:50:55 | 2.94 V | **27.434** | 23.575 | **53.70** | brownout restart → transient |
| 10:51:35 | - | - | - | - | `unavailable`, spojení pryč |
| 10:52:45 | 2.94 V | **27.434** | 23.575 | **53.70** | reconnect, **bit-identické** hodnoty |

Ten poslední řádek není nové měření - je to ta samá hodnota znovu. ESPHome si stavy senzorů drží v RAM a při obnovení spojení je pošle znovu; HA to zaloguje jako změnu, protože entita předtím byla `unavailable`. Poznat se to dá podle toho, že jsou to **bit-identické floaty** (2.93834662437439), což u 30× oversamplovaného ADC nemůže vzniknout dvakrát náhodou.

A protože pak baterka došla nadobro, HA zůstalo viset právě na těch hodnotách z brownoutu: **27.43 °C** (realita 23.58, tedy o 3.9 °C vedle) a **53.7 %** vlhkosti (předtím 64.96, o 11 % vedle). Nikdy naměřené nebyly.

Opraveno filtrem v [`packages/sensors.yaml`](../packages/sensors.yaml), který teplotu a vlhkost SCD41 první 3 minuty po bootu zahazuje úplně - nepublikuje ani necachuje.

#### Vedlejší čísla

Vybíjení z 3.79 V na 2.94 V trvalo 6.5 h, tj. **~0.13 V/h** v režimu DOMA (víc než −0.08 V/h z `doma-baseline` - baterka byla níž ve vybíjecí křivce, kde klesá rychleji).

### `2026-08-22-charging-from-empty/` - 4 h, nabíjení z úplně vybité baterky, s referenčním teploměrem

Zařízení bylo úplně vybité, v 16:15 (lokálně) zapojena nabíječka, v 16:20 nabootovalo, **nabíječka zapojená po celou dobu**. Vedle položený lihový teploměr, odečty ručně - viz [`reference-thermometer.md`](2026-08-22-charging-from-empty/reference-thermometer.md), **bez toho souboru se z dat nedá zjistit skoro nic**.

Export je tentokrát **jeden soubor pro všechny entity** (`all-sensors.csv`, sloupec `entity_id` rozlišuje), včetně `binary_sensor...charging`.

#### 1. Teplo z nabíjení je +3.7 °C, a žádná konstanta ho neopraví

Průběh proti ustálenému stavu (SCD41; BMP180 dělá totéž s odchylkou do 0.2 °C):

| lokální čas | od bootu | teplota | nad ustáleným |
|---|---|---|---|
| 16:25 | 0 min | 23.78 | +0.0 |
| 16:55 | 30 min | 28.38 | +3.4 |
| **17:05** | **40 min** | **28.61** | **+3.7 (vrchol)** |
| 17:25 | 60 min | 28.54 | +3.6 |
| 18:05 | 100 min | 26.66 | +1.7 |
| 18:55 | 150 min | 25.29 | +0.3 |
| 19:15 | 170 min | 24.99 | +0.0 |

Referenční teploměr se přitom celou dobu držel na 23.8-24.2 °C, takže to není teplota v místnosti.

**Proč to nejde opravit konstantou:** teplo je úměrné nabíjecímu proudu a ten závisí na tom, jak prázdná baterka byla. Nabíjení z nuly dá hodinu plného proudu, dobití z 90 % skoro nic. Jedna konstanta by musela být vedle až o ±3.7 °C podle situace, a průměr přes tenhle cyklus (~1.8 °C) by byl vedle v **obou** směrech. Křivka podle času od začátku nabíjení selže ze stejného důvodu - přesně to zkoušela v1 a v terénu přestřelila o ~4 °C, jakmile se podmínky lišily od dat, na kterých byla nafitovaná.

Firmware to proto **needituje a jen to označí**: `CHARGE_OFFSET_*` zůstávají `0.0` a displej dává během nabíjení před hodnotu `~`.

#### 2. Absolutní kontrola offsetů - poprvé proti nezávislé referenci

Po ustálení (19:15-20:15, nabíjení dokončené) proti lihovému teploměru:

| | senzor | reference | rozdíl |
|---|---|---|---|
| SCD41 | ~24.9 | ~24.1 | **+0.5 až +1.0 °C** |
| BMP180 | ~24.6 | ~24.1 | **+0.3 až +0.7 °C** |

Vypadá to, že oba senzory čtou zhruba **o půl stupně až stupeň víc**, než je skutečnost - tedy že oba offsety (tehdy `temperature_offset` 5.6 a `REST_OFFSET_BMP180` 1.74) jsou o tolik malé. **Potvrzeno a doměřeno** v `rest-offset` níž.

**Ale zatím se podle toho nic nemění**, ze dvou důvodů: (a) lihový teploměr má sám přesnost tak ±0.5 °C a v poslední hodině skočil o 1.1 °C, zatímco senzory se pohnuly o 0.15 - takže část toho rozdílu je chyba odečtu; (b) nabíječka byla pořád zapojená, takže i "ustálený" stav ještě nese trochu zbytkového tepla. Co to uzavře, je v seznamu níž.

#### 3. Detekce nabíjení sepnula správně, ale konec nepozná

`Charging` naskočilo v 16:25, tj. **5 minut po bootu** - detekce funguje. Vyplo se v 19:25, což je ale **přesně 3 h 00 min 03 s** po sepnutí, tedy 3hodinová bezpečnostní pojistka, ne rozpoznání konce.

Skutečné nabíjení skončilo kolem **18:10-18:25** (napětí přestalo růst na 4.150 V a začalo mírně klesat). Detekce to nezachytila, protože pokles po dobití je jen ~0.0009 V/min, což se nikdy nedostane přes práh -0.01 V proti klouzavému baseline. Zůstalo tedy hodinu viset zapnuté. Tady to nevadilo (teplo v tu dobu už bylo skoro pryč), ale znamená to, že se na `Charging` nedá spolehnout jako na indikátor "právě teď teče proud".

> Kvůli tomu vzniklo pravidlo "vysoko a bez pohybu". První verze byla ale naladěná **jen na tenhle jeden záznam** a na dalším neuměla vůbec nic - viz `2026-08-23-charging-warm/` níž.

#### 4. Potvrzení té zamrzlé hodnoty z minula

V 16:15, tedy **před** bootem, HA pořád ukazovalo SCD41 **27.43 °C** a BMP180 23.58 - přesně ty hodnoty z brownoutu při vybití v předchozím záznamu. Přímé potvrzení, že se to bez opravy zaseklo a viselo tam hodiny.

#### 5. Vlhkost a CO2

Vlhkost šla 77 → 60 % zatímco teplota rostla 23.8 → 28.6. Přepočet přes Magnusův vztah dá 58 % - naměřeno 60.5 %. Ta změna vlhkosti tedy **není skutečná**, je to jen důsledek toho, že senzor počítá RH ze své vlastní nadhodnocené teploty. Zároveň je to hezké ověření, že ten Magnusův přepočet v `humidity:` filtru počítá správně.

CO2 spadlo 2400 → 1540 mezi 16:35 a 17:35 a pak znovu 1750 → 1250 kolem 19:45 - otevřené dveře, normální větrání. Nic se senzorem.

#### Práh CO2 alarmu tu byl překročený - a nikde není, co se stalo

Zpětný nález (srpen 2026). CO2 vylezlo na **5038 ppm** a nad prahem 3000 se
drželo **80 vzorků, tedy 6.5 minuty** (23:40-23:46 lokálně). Zařízení bylo
v DOMA, vzhůru, a před dýcháním leželo v klidu, takže armovací pravidlo
(tři čtení do 150 ppm od sebe) muselo být splněné. Alarm tedy sepnout měl.

**Jestli sepnul, se z dat zjistit nedá.** `co2_alarm_active` je jen globál -
zapne displej, vynutí STAY a vykreslí varovnou obrazovku, ale **do Home
Assistantu se nepublikuje jako entita**. V exportu po něm nezůstane stopa,
ať sepnul nebo ne. Proto je alarm pořád vedený jako neověřený: nemáme
záznam, ne že by se neměl jak projevit.

Praktický důsledek pro příští test: buď se u toho musí koukat na displej,
nebo se `co2_alarm_active` napřed vystaví jako `binary_sensor` do HA. To
druhé by zároveň umožnilo na alarm navázat automatizaci.

### `2026-08-22-cesta-wake-cycles/` - 50 min, 9 cyklů probuzení z deep sleepu

Test s jedinou otázkou: **spouští startovní skok SCD41 i probuzení z deep sleepu?** Nastaveno DEEP SLEEP zapnuto + HA připojení zapnuté (tedy CUSTOM, ne čistá CESTA - v čisté CESTA je WiFi vypnutá a do HA by se nedostalo nic), interval 5 min. Ve 20:42 lokálně odpojena nabíječka.

**Odpověď: ano, opakuje se to při každém probuzení, a je to horší než při studeném startu.**

| probuzení | SCD41 1. čtení | SCD41 2. čtení (+10 s) | BMP180 | SCD41 − BMP180 |
|---|---|---|---|---|
| 20:47 | 29.637 | 28.908 | 24.276 | **+5.36** |
| 20:53 | 29.386 | 28.631 | 23.987 | **+5.40** |
| 20:58 | 29.173 | 28.428 | 23.751 | **+5.42** |
| 21:04 | 28.857 | 28.120 | 23.485 | **+5.37** |
| 21:09 | 28.574 | 27.851 | 23.151 | **+5.42** |
| 21:15 | 28.470 | 27.720 | 22.932 | **+5.54** |
| 21:20 | 28.355 | 27.640 | 22.823 | **+5.53** |
| 21:26 | 28.305 | 27.581 | 22.738 | **+5.57** |
| 21:31 | 28.262 | 27.509 | 22.677 | **+5.59** |

Devět probuzení, pokaždé stejný obrázek: SCD41 startuje **~5.5 °C nad** BMP180 a za 10 s spadne o **0.72-0.76 °C**. Ta konzistence je pozoruhodná - rozptyl prvního rozdílu je 5.36 až 5.59, rozptyl poklesu 0.72 až 0.76.

Pro srovnání první blok v 20:42, ještě než začalo uspávání (zařízení běželo v kuse): SCD41 24.879 vs BMP180 24.572, tedy **rozdíl 0.31 °C** - úplně normální. Takže dokud běží nepřetržitě, oba senzory si odpovídají; jakmile se začne uspávat, je SCD41 o pět stupňů vedle. Vlhkost s tím jde ruku v ruce: 61.8 % v tom prvním bloku, pak 46.7-50.6 % při každém probuzení, tj. o ~13 % míň.

BMP180 přitom klesá naprosto hladce (24.57 → 22.68 za 50 min, jak krabička ve spánku chladne) a **žádný skok nemá**.

#### Co z toho plyne

Mechanismus zapadá do toho, co ukázaly předchozí záznamy: první čtení po `start_periodic_measurement` vypadá, jako by na něj ještě nebyl aplikovaný `temperature_offset` (tehdy 5.6 °C), a ten se "dotáhne" během ~2 minut. Sedí to na obojí - při studeném startu je čip stejně studený jako krabička, takže chybějící offset dělá rozdíl proti BMP180 jen ~1.7-2.1 °C; tady čip celou dobu spánku běžel dál a je proti chladnoucí krabičce rozehřátý, takže totéž dělá ~5.5 °C.

**Prakticky: v režimu s deep sleepem je teplota a vlhkost ze SCD41 nepoužitelná.** 30 s vzhůru je řádově míň, než těch ~2 min, co potřebuje na dotažení. Firmware to od té doby zahazuje (první 3 min po bootu), takže se do HA aspoň nedostane nesmysl - ale znamená to, že v CESTA nemá odkud teplotu brát. Nejnadějnější řešení je **brát ji z BMP180**, který je v těch samých datech čistý.

### `2026-08-22-rest-offset/` - 1 h, klidový offset proti referenčnímu teploměru

**Tímhle se zavřela kalibrace teploty.** Ruční odečty a podmínky jsou v [`reference-thermometer.md`](2026-08-22-rest-offset/reference-thermometer.md).

Nabíječka i USB odpojené, DOMA, displej zhasnutý, 49 min na ustálení, pak tři odečty po pěti minutách - všechny shodně **23.9 °C**.

| | senzor | teploměr | chyba | offset |
|---|---|---|---|---|
| SCD41 | 24.97 | 23.9 | **+1.07 °C** | 5.6 → **6.7** |
| BMP180 | 24.62 | 23.9 | **+0.72 °C** | 1.74 → **2.46** |

Obě kontroly platnosti prošly: rozdíl mezi senzory 0.35 °C (očekáváno 0.3-0.5) a BMP180 se přes všechny tři odečty pohnul jen o 0.090 °C, takže se místnost pod rukama neměnila. Ta druhá kontrola je podstatná - oba senzory za vzduchem zaostávají o svou časovou konstantu (11-15 min), takže drift v místnosti by se započítal jako chyba offsetu.

Proti předchozímu pokusu (`charging-from-empty`, kde vyšlo +0.5 až +1.0 a +0.3 až +0.7) to sedí, jen je to čistší: tehdy byla zapojená nabíječka a teploměr během hodiny skákal o 1.1 °C.

Vedlejší efekt: změna `temperature_offset` posune i vlhkost, protože SCD41 počítá RH ze své offsetem opravené teploty - vyjde asi o 4 procentní body výš. Ověřit to nemáme čím, vlhkoměr jako reference chybí. CO2 to neovlivní.

### `2026-08-22-breath-test/` - 45 min, dýchání do senzoru

První záznam na **novém firmwaru** (nové offsety 6.7 / 2.46). Zařízení v klidu, pak od 23:39 pomalé dýchání do krabičky.

#### Potvrzení, že nové offsety sedí

Před dýcháním je rozdíl **SCD41 − BMP180 = −0.06 až −0.11 °C**. Před překalibrováním to bylo +0.35 °C. Posun je přesně ten očekávaný: SCD41 dostal o 1.07 větší offset, BMP180 o 0.72, rozdíl 0.35 - takže +0.35 → ~0.00. Oba senzory se teď za klidu shodnou na **desetinu stupně**. Po odeznění dýchání (00:06) je rozdíl zpátky na −0.05 °C.

#### Reakce na dech

| | SCD41 | BMP180 |
|---|---|---|
| interval čtení | 5 s | 60 s |
| vrchol | 26.29 °C v 23:40:21 | 28.00 °C v 23:40:56 |
| náběh | 24.03 → 26.29 za 45 s | jen 3 vzorky přes celou událost |

**Rozdíl až −2.57 °C je přechodový jev, ne neshoda senzorů.** BMP180 je holý čip s minimální tepelnou kapacitou a reaguje okamžitě; SCD41 je větší modul a jeho teplotní výstup je navíc interně filtrovaný (ten samý filtr, který dělá ~2min startovní transient). Při pomalé změně dají oba totéž, při prudké ukáže víc ten rychlejší a bližší zdroji tepla.

Zajímavost: publikovaných 28.00 °C u BMP180 je **už zfiltrovaná** hodnota. Median-of-3 vydá prostřední ze tří čtení, takže aby prošlo 28.00, muselo být jedno z předchozích syrových čtení **ještě vyšší** - skutečný vrchol byl nejspíš přes 30 °C. Filtr fungoval, jak má.

#### Ostatní veličiny

- **CO2**: 1253 → **5038 ppm** ve vrcholu, nad 3000 ppm celkem **6.6 min**. Návrat k ~1400 za 25 min.
- **Vlhkost**: 65.7 → **93.8 %**, vrchol ale až v 23:52, tedy **12 min po** vrcholu CO2. Část toho zpoždění je chladnutí (klesající teplota zvedá RH při stejném množství vody), část vlhkost, která v krabičce zůstala - CO2 se provětrá rychleji.

> 93.8 % je blízko rosnému bodu. Dech je nasycený při ~34 °C a když v krabičce zchladne na 24 °C, je hluboko za saturací. Jednorázově nevadí, opakovaně tam dýchat ale znamená riziko skutečné kondenzace na senzorech.

### `2026-08-23-charging-warm/` - 1 h, nabíjení ze 64 % s už ustálenou krabičkou

Protějšek k `charging-from-empty`. Tam byla baterka na nule a krabička studená, takže se startovní transient, zahřívání skříňky i teplo z nabíjení míchaly dohromady. Tady bylo zařízení **hodiny v provozu a plně ustálené**, teprve pak se v 00:19:54 (lokálně) připojila nabíječka - takže jediné, co se v datech hýbe, je teplo z nabíjení. Export je zase jeden soubor (`all-sensors.csv`).

Záznam začíná v ocasu předchozího dýchacího testu, proto ta úvodní vlhkost 82 % a CO2 1342 ppm.

#### 1. Nejlepší dosavadní potvrzení offsetů

Před připojením nabíječky:

| SCD41 | BMP180 | rozdíl |
|---|---|---|
| 24.006 | 24.014 | **−0.009 °C** |

Devět tisícin stupně. Po dýchacím testu (−0.06 až −0.11) je to druhé nezávislé potvrzení, že `temperature_offset 6.7` a `REST_OFFSET_BMP180 2.46` sedí vůči sobě. O absolutní přesnosti to neříká nic - to umí jen teploměr vedle.

#### 2. Teplo z nabíjení je hrb, ne schod - a jeho výška závisí na stavu baterky

| od připojení | SCD41 | nad klidem |
|---|---|---|
| 0 min | 24.01 | +0.0 |
| 2 min | 24.07 | +0.1 (začíná se hýbat) |
| 10 min | 25.28 | +1.3 |
| 20 min | 26.12 | +2.1 |
| **28 min** | **26.32** | **+2.31 (vrchol)** |
| 40 min | 26.09 | +2.1 |
| 50 min | 25.63 | +1.6 |
| 62 min | 25.38 | **+1.37 (a pořád klesá)** |

BMP180 dělá totéž, vrchol +2.41 °C v 27 min.

Klíčové srovnání: **z prázdné baterky to bylo +3.7 °C, ze 64 % jen +2.35 °C.** Stejná krabička, stejná nabíječka, stejná místnost - rozdíl 1.4 °C způsobil jen jiný počáteční stav baterky. Tím se argument "žádná konstanta to neopraví" mění z úvahy na **změřený fakt**: jedna konstanta je vedle o 1.4 °C už jen mezi těmito dvěma případy.

A `~` na displeji je tím pádem správná volba i proto, že teplo po ~28 min zase samo klesá - i "správná" konstanta by po chvíli přepravovala.

#### 3. Který senzor cítí teplo dřív

Rozdíl SCD41 − BMP180 se během hrbu mění: při náběhu je SCD41 **výš** (až +0.087 °C), při klesání **níž** (až −0.22 °C). Obojí znamená totéž - SCD41 se hýbe dřív, tedy leží tepelně blíž zdroji (baterka / TP4056).

Není to v rozporu s dýchacím testem, kde byl rychlejší naopak BMP180 o 1.7 °C. Tam šlo teplo **vzduchem** za desítky sekund a rozhodovala tepelná kapacita čipu; tady jde **materiálem** desítky minut a rozhoduje vzdálenost od zdroje. Jiný mechanismus, jiné pořadí.

#### 4. Detekce konce nabíjení: pravidlo z minule tady neuděla vůbec nic

Napětí vyrostlo 3.77 → 4.118 V a v 01:00:55 **v jednom kroku spadlo o 0.022 V** na 4.095, pak se ustálilo na ~4.083 a dvacet minut se drželo. Ten skok odpovídá konci nabíjení - zmizí úbytek na vnitřním odporu článku (0.022 V ≈ 500 mA × 44 mΩ).

Jenže tehdejší práh byl `FULL_V = 4.10`. **Ta hranice už nikdy nebyla překročena, takže pravidlo nesepnulo ani jednou** a `Charging Duration` běželo dál až do konce záznamu (60 min).

Proč: obě nabíjení skončila na **jiném napětí** - 4.120 V (z prázdné) a 4.083 V (odsud). 37 mV od sebe na stejném hardwaru. Absolutní hladina tedy nic negeneralizuje, generalizuje jen **plochost**. Pravidlo se proto přeladilo: `FULL_V` je teď jen volná pojistka na 4.05 a rozhoduje `FULL_FLAT_DELTA` (0.001 → 0.002, protože zdejší plató má kroky až 0.0019 V).

Přeměřeno přes oba záznamy:

| | z prázdné | zahřáté |
|---|---|---|
| staré 4.10 / 0.001 / 5 | 18:19 (+125 min) ✓ | **nikdy** ✗ |
| nové 4.05 / 0.002 / 5 | 18:19 (+125 min) ✓ | 01:07 (+48 min) ✓ |

`FULL_V` 4.00-4.08 dává stejný výsledek a `FULL_CONFIRM` 4-10 taky - obojí sedí v ploché části parametrů, ne na hraně.

#### 5. Plná baterka ukazovala 90 %

Vedlejší nález ze stejného napětí. Mapa procent byla lineární 3.0-4.2 V, ale plno je naměřeno na 4.083-4.120 V, takže **dobitá baterka hlásila 90-93 % a stovky se nedalo dosáhnout nikdy**. Horní konec se proto vzal z měření (4.12 V), ne z katalogového 4.2.

Otevřené zůstává, jestli článek opravdu končí na 4.12 V, nebo jestli dělič podhodnocuje skutečných 4.2 V o ~2 %. Rozhodne multimetr (viz TODO u děliče v `sensors.yaml`) - pro procenta je to ale jedno, protože se teď berou z toho, co ADC reálně hlásí při dobití.

#### 6. Ostatní veličiny

- **Vlhkost** 81.9 → 64.0 %, a rozpad na příčiny je zajímavější, než vypadá. Když se RH přepočte na absolutní vlhkost (přes Magnusův vztah) a pak zpátky na to, co by ukazovala při původních 24.01 °C:

  | čas | T | RH | abs. vlhkost | RH při 24.01 °C |
  |---|---|---|---|---|
  | 00:18 | 24.01 | 81.9 | 17.77 g/m³ | 81.9 |
  | 00:29 | 25.23 | 79.6 | **18.53 g/m³** | **85.7** |
  | 00:49 | 26.30 | 67.7 | 16.72 g/m³ | 77.6 |
  | 01:07 | 25.72 | 64.7 | 15.46 g/m³ | 71.6 |

  Vody ve vzduchu tedy prvních deset minut **přibývalo** (17.8 → 18.5 g/m³), teprve pak ubývalo. To sedí na varování z dýchacího testu: vlhkost z dechu opravdu zkondenzovala na stěnách a povrchu senzorů, a teplo z nabíjení ji odpařilo zpátky do vzduchu. Zbytek poklesu už je normální vysychání krabičky. Ze samotného RH by to vidět nebylo - vypadá to jako monotónní pokles.
- **CO2** 1342 → 1247 (00:46) → 1318. Doznívání dýchacího testu a pak normální nárůst v zavřené místnosti.
- **Tlak** 966.2-966.6 hPa přes celou hodinu, žádný výstřel - median-of-3 dělá svoje.

### `2026-08-23-cesta-baseline/` - 12.4 h přes noc v uspávaném režimu, s referenčním teploměrem

Přesně ten záznam, který si předchozí verze tohohle souboru přála pod názvem "CESTA baseline". Deep sleep zapnutý, interval **10 min** (jako preset CESTA), ale **HA připojení nechané zapnuté** - jinak by se do Home Assistantu nedostalo nic. V menu se tohle hlásí jako `CUSTOM`, ne `CESTA`; skutečná CESTA má WiFi vypnutou, takže **naměřená spotřeba je horní odhad** té skutečné.

Krabička byla na začátku **nahřátá** (předtím běžela a nabíjela se), baterka **plná a odpojená** (4.152 V / 100 %). Od 03:25 do 03:36 lokálně ještě běželo bez uspávání, pak už jen 71 časovaných probuzení až do 15:46. Ruční odečet referenčního teploměru na konci je v [`reference-thermometer.md`](2026-08-23-cesta-baseline/reference-thermometer.md).

Perioda probuzení vyšla **625.5 s** (medián, rozptyl 622-627 s), tedy 10 min spánku + ~26 s vzhůru. V každém okně **5 čtení CO2** po 5 s, rozsah 19.8 s - přesně to, s čím `update_interval: 5s` počítalo.

#### 1. Výdrž: −0.0076 V/h, což je 38 % rozpočtu

Hlavní číslo celého záznamu. Napětí kleslo **4.1518 → 4.0050 V za 12.36 h**.

| úsek | sklon |
|---|---|
| celý záznam (koncové body) | −0.0119 V/h |
| od +1 h (koncové body) | −0.0072 V/h |
| od +2 h (lineární fit, 60 bodů) | **−0.0076 V/h** (rezidua sd 6.8 mV) |
| poslední 6.4 h | −0.0069 V/h |

První hodina je **relaxace po nabíjení**, ne vybíjení: 4.1518 V drží 11 min, pak spadne na 4.0865 V a od 64. minuty se křivka narovná. Do výdrže se počítat nemá.

**Cíl pro CESTA byl −0.02 V/h. Naměřeno −0.0076, tedy 38 % rozpočtu.** Procenta to potvrzují nezávisle: 100 % → 89.9 %, tj. **10.1 procentního bodu za 12.4 h**.

Lineární extrapolace (a je to **jen řádový odhad** - LiPo křivka lineární není a tenhle záznam pokrývá jen horní kousek 4.15-4.00 V):

| z 4.12 V do | čas |
|---|---|
| 3.50 V | 81 h ≈ 3.4 dne |
| 3.30 V | 107 h ≈ 4.5 dne |
| 3.00 V | 147 h ≈ 6.1 dne |

Proti dřívějším měřením: **-0.08 V/h** v DOMA (`2026-08-22-doma-baseline/`) a **-0.070 V/h** v uspávaném režimu, když SCD41 ještě běžel i ve spánku (`2026-08-22-cesta-wake-cycles/`, interval 5 min). Zlepšení proti tomu druhému je zhruba **9×**, což je víc, než odhadovalo README u opravy `stop_periodic_measurement` (3-4×). Tři výhrady, aby to číslo nebylo přeceněné: změnil se **zároveň** interval (5 → 10 min, tedy poloviční duty cycle), měřilo se v **jiné části vybíjecí křivky** (V/h se nedá porovnávat napříč jejími úseky), a starý záznam navíc nezačínal od plné baterky. Směr i řád ale sedí.

#### 2. Teplota je v tomhle režimu o 3.55 °C pod realitou - a nic to neoznačí

Od 06:00 do konce je BMP180 naprosto klidný: **18.955 °C ± 0.043** (22 bodů za posledních 5 h, bez jednoho výkyvu níž). Referenční teploměr v 15:50 hlásí **22.5 °C**.

| | hodnota | chyba proti referenci |
|---|---|---|
| publikováno do HA a na displej | 18.955 | **−3.55 °C** |
| syrové čtení senzoru (+2.46 zpátky) | 21.415 | −1.09 °C |

**Příčina je jistá a je v kódu:** `REST_OFFSET_BMP180 = 2.46` se odečítá **bezpodmínečně**, ale byl změřen v DOMA, kde zařízení běží nepřetržitě a krabička se od sebe sama trvale hřeje. V uspávaném režimu je zařízení vzhůru **26 s ze 626** (4.2 % času) a BMP180 se čte ~3 s po bootu, tedy ve stavu, do kterého se krabička dostala za 10 min spánku - prakticky v rovnováze s okolím. Není tam co odečítat. README tuhle možnost správně předpovědělo ("nejspíš odečítá víc, než by měl"); teď je změřená.

**Co s tím zbylým −1.09 °C, se z tohohle záznamu rozhodnout nedá.** Může to být vlastní chyba BMP180 (datasheet ±1 °C), chyba teploměru (±0.5 °C), nebo skutečný rozdíl mezi místem krabičky a místem teploměru. Jeden odečet, jeden přístroj, neznámé umístění - viz `reference-thermometer.md`.

> **Opraveno v srpnu 2026** (větev `v2-deep-sleep-fixes`): offset se odečítá jen když je `cold_boot` pravdivé, tedy když boot **není** probuzení ze spánku. A vlnovka na to nově sedne - viz bod 7 níž. **Ověřeno na železe** v `2026-08-23-cesta-po-oprave/` níž: chyba proti referenci spadla na **−0.90 °C**, tedy blízko předpovězených −1.09. Zbytek je pořád otevřený a tenhle záznam ho rozhodnout neumí.

Prakticky nejhorší na tom bylo, že **se to nijak neoznačilo.** Displej zkouší SCD41 → BMP180 → cache; SCD41 v tomhle režimu stav nikdy nemá (bod 3), takže se vezme BMP180, ten stav **má**, takže `stale` je `false`. A `suspect` je taky `false`, protože po probuzení z deep sleepu není `cold_boot` a nenabíjí se. Vlnovka se tedy neobjeví a v autě je vidět sebevědomé číslo o 3.5 °C vedle.

#### 3. Ze SCD41 nepřišla za 12 hodin ani jedna teplota nebo vlhkost

Poslední skutečná čtení jsou z 03:25:52 (**25.044 °C**) a 03:25:55 (**63.57 %**), tedy ještě před prvním uspáním. Od **03:36:14** je obojí v HA `unknown` a zůstane tak **12 h 10 min** až do konce záznamu. Obě entity se objeví ve **2 z 72** probuzení - a to jsou ty dvě před spánkem.

Je to **přesně to, co filtr `SCD41_SETTLE_MS = 3 min` má dělat**, a je to i v kódu popsané. Nové je, jak to vypadá z druhé strany: není to "zhoršená" hodnota, je to **`unknown`**, a je to tak celou dobu. Komentář v `packages/sensors.yaml` říká, že hodnoty "stay at the last cached value" - to platí pro **displej** (`cached_temp_scd41`, flash-backed), ne pro Home Assistant. V HA je dlouhodobá statistika obou entit za tuhle noc prostě prázdná.

#### 4. CO2 po probuzení funguje spolehlivě - 72 ze 72

Tohle byla otevřená otázka od opravy s `stop_periodic_measurement` (jestli se senzor po zaparkování na spánek zase rozběhne). **Odpověď: ano, ve všech 72 probuzeních**, pokaždé ~5 čtení. Křivka dává smysl jako celek: 1512 ppm v 03:25, minimum **1112 ppm v 04:49**, pak plynulý růst přes celý den až na **1744 ppm v 15:46**. Žádné výpadky, žádné nesmyslné skoky.

Simulace nad tím samým záznamem navíc zavírá otázku, jestli se **armování CO2 alarmu vejde do 30s okna**: pravidlo „3 čtení do 150 ppm" se armovalo ve **všech 72 probuzeních**, pokaždé na 3. čtení, a tříminutový fallback se nepoužil ani jednou. Armující čtení se rovnou vyhodnocuje i proti prahu, takže alarm má šanci sepnout v každém probuzení. Neověřuje to, že alarm skutečně sepne - CO2 nepřesáhlo 1744 ppm proti prahu 3000 - ale že mu v tom nebrání armování.

Drobnost, která z toho vypadla: ve **42 ze 72** probuzení je úplně první řádek CO2 v HA `unknown`, a **0.5-4 s** po něm už přijde reálná hodnota. Je to okamžik připojení - HA si vezme stav entity dřív, než senzor stihl první čtení. Kosmetické (hodnota v tom samém probuzení dorazí), ale zapisuje to do recorderu 42 zbytečných `unknown` řádků.

#### 5. Filtry, které potřebují historii, v uspávaném režimu nedělají nic

Tohle je zobecnění, na které záznam přivedl jeden konkrétní výkyv: **14:43:48 lokálně** publikovalo BMP180 **18.028 °C** mezi sousedy 18.911 a 18.917, tedy **−0.886 °C** vedle. Přesně ten typ jednoho špatného I2C čtení, proti kterému byl přidán `median` filtr (okno 3) - a přesto prošel. (Menší, −0.391 °C, je i v 10:33:36.)

Důvod: **deep sleep je plný reboot.** Za jedno probuzení stihne BMP180 při `update_interval: 60s` právě **jedno** čtení, a `median` filtr se rozjíždí od nuly. Se `send_first_at: 1` vydá medián z jednovzorkového okna, což je ten vzorek sám. V uspávaném režimu je ten filtr **no-op**.

Stejný mechanismus (ověřeno čtením konfigurace, ne z těchhle dat) se týkal i toho, co je níž. **Vše v tomhle výčtu popisuje stav před opravou** - co se s tím udělalo, je v poznámce pod ním:

- **tlaku** - stejný `median` filtr, stejné okno, stejný problém;
- **`battery_voltage`** - medián ze 3 se počítá v lambdě přes `batt_v_hist1/2`, obojí `restore_value: false`, takže po každém bootu je `batt_v_hist2 == 0` a kód spadne do větve `v = raw_v`;
- **detekce nabíjení** - `batt_v_slow_avg`, `charge_confirm_count`, `full_confirm_count` i `is_charging` jsou všechny `restore_value: false`. Pomalý klouzavý průměr s časovou konstantou ~10 min dostane za probuzení jeden vzorek a pak se zahodí. **V uspávaném režimu proto `Charging` nemůže sepnout nikdy** - a s ním nefunguje ani vlnovka při nabíjení. V tomhle záznamu se nenabíjelo, takže to není z dat potvrzené ani vyvrácené; z konfigurace to ale plyne jednoznačně.

Napětí to mimochodem nijak neublížilo - rezidua fitu jsou 6.8 mV, čistší než ~18 mV šumu popsaných z DOMA. Ale spoléhat se na filtr, který v daném režimu neběží, je štěstí, ne návrh.

> **Opraveno v srpnu 2026**, každé jinak podle toho, co který senzor potřebuje. BMP180 a tlak čtou po **5 s** místo po 60, takže se okno mediánu naplní uvnitř jednoho probuzení a žádný trvalý stav není potřeba. Historie mediánu napětí a celý stav detekce nabíjení se ukládají do **flash** a v `on_boot` se při studeném bootu nulují - flash totiž přežije i vypnutí, což by u `is_charging` bylo špatně. A detekce nabíjení dostala ve spánku **vlastní pravidlo** přes krok mezi probuzeními, takže `Charging` tam už sepnout může.

#### 6. Procento baterky chybí ve 29 % probuzení

`Battery Level` je `unknown` ve **21 ze 72** probuzení (poprvé 03:36:14, naposledy 15:35:56). Na vině je závod, o kterém komentář v kódu tvrdí, že nastat nemá ("the voltage sensor is registered first and runs first on a shared 60s tick, so this shouldn't trigger"). **Nastává, skoro v třetině probuzení.**

Mechanismus: obě šablony mají `update_interval: 60s` a ESPHome plánuje první běh intervalu na `now + náhodný offset v [0, 5 s)` (`Scheduler::calculate_interval_offset_`) - **nezávisle pro každou komponentu**. Když padne `battery_level` dřív než `battery_voltage`, projde v lambdě pojistka `if (!id(battery_voltage).has_state()) return {};`, nepublikuje se nic, a protože je zařízení vzhůru jen ~26 s, **druhá šance v tom probuzení nepřijde** (další tik by byl za 60 s). HA při připojení odečte stav jako NaN → `unknown`. Že je to pořadím a ne něčím jiným, je vidět v datech: v takovém probuzení má `battery_voltage` platnou hodnotu už v okamžiku připojení, `battery_level` `unknown`.

Displej tím netrpí (`cached_battery_pct` je flash-backed), postižená je řada v HA.

> **Opraveno v srpnu 2026:** procenta se počítají na konci lambdy `battery_voltage` a publikují přes `publish_state()`; šablona přišla o vlastní tik. Závod tím mizí konstrukcí. Ověřit to jde jedině na železe - plánovač ESPHome se ze stolu nasimulovat nedá.

#### 7. Chladnutí po přepnutí do spánku trvá ~3 h

Vedlejší, ale prakticky užitečné číslo, protože přesně tohle se děje, když si člověk vezme rozběhnutou krabičku z bytu do auta. Krabička startovala nahřátá na 25.28 °C publikovaných a klesala na plató 18.97:

| od uspání | publikováno | nad plató |
|---|---|---|
| 11 min | 23.19 | +4.22 |
| 32 min | 21.31 | +2.34 |
| 64 min | 20.15 | +1.18 |
| 95 min | 19.69 | +0.72 |
| 106 min | 19.25 | +0.28 |

Log-fit přes prvních 21 bodů dává **τ ≈ 57 min**, ale jedna exponenciála to není - z prvních bodů vychází τ 28-44 min a postupně roste, což odpovídá dvěma tepelným hmotám (deska a baterka zvlášť). Prakticky: do **0.5 °C** od plató zhruba za **2.5 h**, do 0.25 °C za **3 h**.

Pro srovnání: zahřívání po **studeném** startu (`2026-08-22-cold-start/`) je ~45 min. Chladnutí je tedy podstatně pomalejší než zahřívání.

> **Opraveno v srpnu 2026:** z tohohle fitu vyšel práh okna, po které displej drží vlnovku - **150 min**, což je 144 min (kdy chyba klesne pod deklarovanou přesnost ±0.5 °C) zaokrouhlených nahoru. Okno se nuluje při vstupu do spánku, pokud zařízení do té chvíle běželo dýl než 5 min, a při každém stoupnutí napětí nad prahem nabíjení.

#### Ostatní veličiny

- **Tlak** publikován ve všech 72 probuzeních, 966.78 → 968.02 hPa (min 965.69, max 968.59). Bez výpadků.
- **Tlačítko** se za celou noc neobjevilo - všech 71 probuzení je časovaných. **Probuzení tlačítkem tenhle záznam neověřuje.**
- **CO2 alarm** nemohl sepnout, maximum je 1744 ppm proti prahu 3000. Pořád neověřený - i když v `2026-08-22-breath-test/` práh překročený byl, viz níž.

### `2026-08-23-cesta-po-oprave/` - 2.8 h v uspávaném režimu, ověření oprav v2

Protějšek `2026-08-23-cesta-baseline/` výš: **stejný režim, stejná krabička, stejný interval, jen s firmwarem z větve `v2-deep-sleep-fixes`**. Účel je jediný - ověřit na hardwaru čtyři opravy, které se do téhle chvíle opíraly jen o `esphome config`/`compile` a o simulace nad daty. Ruční odečty referenčního teploměru jsou v [`reference-thermometer.md`](2026-08-23-cesta-po-oprave/reference-thermometer.md).

Firmware nahraný v **17:40** lokálně, deep sleep s intervalem **10 min**, HA připojení nechané zapnuté (v menu se to hlásí jako `CUSTOM`, ne `CESTA`). Baterka **odpojená od nabíječky**, start na 3.975 V / 87 %. Krabička byla na začátku **nahřátá od flashování** - během kompilace a nahrávání běžela nepřetržitě na USB - a prvních ~50 min se chladí. Bez zásahu, **16 časovaných probuzení**, tlačítko ani jednou.

Perioda probuzení vyšla **10.41 min** (10.38-10.44), tedy 10 min spánku + ~25 s vzhůru. V každém okně **1 hodnota BMP180, 1 tlak a 4-5 čtení CO2** - přesně to, s čím `send_every: 3` u mediánu počítalo.

#### 1. Offset: chyba spadla z −3.55 na −0.90 °C

Skok při prvním probuzení ze spánku je vidět přímo v datech, protože flash boot je `cold_boot` a ten poslední odečítá:

| | BMP180 |
|---|---|
| 17:40:00, flash boot (`cold_boot`, offset se odečítá) | 19.746 |
| 17:50:00, 1. probuzení ze spánku (offset se neodečítá) | 22.421 |
| **skok** | **+2.676** |

`REST_OFFSET_BMP180` je 2.46, zbylých **+0.216 °C** je skutečná změna syrového čtení za těch 10 min. Klíčování na `cold_boot` tedy dělá přesně to, co má.

Proti referenčnímu teploměru ve třech srovnatelných bodech: **−0.71 / −1.07 / −0.93 °C, průměr −0.90, sd 0.18**. Kdyby se offset pořád odečítal, vyšlo by z **těch samých** dat −3.36 °C, což sedí na −3.55 změřených v baseline.

**Zbytkových −0.90 °C zůstává otevřených** a je to pořád dvojnásobek deklarované ±0.5 °C. Předpověď specu byla −1.09; tenhle záznam ji potvrzuje v rámci vlastní nejistoty, ale nerozhoduje, čí ta chyba je - proč, je v `reference-thermometer.md`.

#### 2. Procenta baterky: 0 `unknown` proti 22 předtím

| | řádků `battery_level` | z toho `unknown` |
|---|---|---|
| baseline (před opravou) | 64 | **22** |
| tenhle záznam | 12 | **0** |

Závod mezi `battery_level` a `battery_voltage` byl v tom, že ESPHome startuje interval každé komponenty s vlastním náhodným posunem, takže šablona občas počítala procenta z napětí, které ještě neexistovalo. Publikování procent přímo z lambdy `battery_voltage` ten závod odstraňuje **z definice** - a data to potvrzují: ani jedno `unknown` za 16 probuzení.

12 řádků na 16 probuzení není výpadek, a dá se to z dat dokázat. Ostatní senzory mají při **každém** připojení řádek `unknown` (BMP180, tlak i CO2 - ESPHome hlásí NaN, dokud v tom bootu nic nepublikovaly), zatímco `battery_voltage` ani `battery_level` **nemají ten řádek ani jednou**. Napětí tedy stihlo publikovat před připojením ve všech 16 probuzeních. A těch pět chybějících řádků jsou právě probuzení, kde CO2 a teplota data mají, takže zařízení připojené bylo. Zbývá jediné vysvětlení: hodnota vyšla **bit-identicky** jako minule a HA zapisuje jen změny (viz Formát nahoře). Což je přesně podpis mediánu ze tří - ten vrací jeden ze tří skutečných vzorků, takže se opakovat může. Syrové ADC s šesti desetinnými místy by se netrefilo.

Hodnoty klesají hladce, **87.05 → 86.38 %** za 2 h 46 min. Žádný skok zpátky nahoru na "čerstvou" hodnotu, tedy `batt_v_hist1/2` opravdu přežily spánek.

#### 3. Medián přes probuzení: žádný výkyv za 16 probuzení

Kvůli tomuhle celá perzistence globálů je. V baseline prošel filtrem výkyv **−0.886 °C**, protože `median` se po každém probuzení rozjížděl od nuly a byl no-op. Tady:

| | baseline | po opravě |
|---|---|---|
| největší skok BMP180 mezi probuzeními | −0.886 °C | **−0.092 °C** |
| sd kroku napětí mezi probuzeními | 8.02 mV | **1.45 mV** |

Šestnáct hodnot BMP180 tvoří **monotónně klesající řadu** 22.421 → 21.959, bez jediné výjimky. Tlak stejně tak: 968.14-968.31 hPa, sd 0.054, největší skok 0.17.

Spec předpovídal sd kroku 2.16 mV; naměřeno 1.45. Lineární fit napětí přes 11 bodů má **rezidua sd 0.91 mV** proti 6.8 mV v baseline. Ta dvě čísla nejsou úplně souměřitelná (kratší úsek, míň bodů, plošší část křivky), ale řád i směr sedí.

#### 4. Detekce nabíjení: 0 falešných sepnutí, 8× rezerva na prahu

Nabíječka připojená nebyla, takže je to **negativní test** - a ten je pro tuhle opravu ten důležitější, protože falešné sepnutí by trvale označilo správné hodnoty za nedůvěryhodné.

Jedenáct kroků napětí mezi probuzeními: `+2.5 −3.3 −1.1 −0.2 −0.2 −0.3 −0.7 −0.7 −0.7 −0.1 −2.5` mV. Největší kladný je **+2.45 mV** proti prahu **+20 mV**, tedy **8× rezerva**. `Charging` zůstalo `off` a `Charging Duration` na `0.0` po celý záznam.

**Že příznak sepne, když se nabíječka připojí, tenhle záznam neověřuje.** To zůstává otevřené.

#### 5. Čítače běží o 4 % pomaleji, než ukazují

Vedlejší nález, který za zápis stojí. Skutečná perioda je **10.41 min**, ale `charge_minutes` i `disturb_minutes` přičítají `sleep_interval_minutes`, tedy rovných 10. Okno vlnovky nastavené na 150 min čítače tedy ve skutečnosti trvá **~156 min**. Chyba je jedním směrem (okno je delší, ne kratší) a proti 150 min je to šum - nemá cenu to opravovat, ale je dobré to vědět, než se z těch čítačů začne něco počítat.

#### Ostatní veličiny

- **Teplota a vlhkost ze SCD41**: za celý záznam **0 platných hodnot**, obojí `unknown` od začátku do konce. Je to `SCD41_SETTLE_MS = 3 min` proti 25 s vzhůru, přesně jak to popisuje baseline (bod 3) a komentář v `packages/sensors.yaml`. **Tohle oprava neřešila a je to teď největší zbylá díra v uspávaném režimu** - jediný zdroj teploty tam je BMP180.
- **CO2** publikováno ve všech 16 probuzeních, 4-5 čtení na okno, 992 → 933 ppm s minimem 848. Bez výpadků, bez nesmyslných skoků. Alarm nemohl sepnout (maximum 992 proti prahu 3000).
- **Vlnovka** je vidět jen na displeji a displej při časovaném probuzení nesvítí. Tlačítko zmáčknuté nebylo, takže **tenhle záznam vlnovku neověřuje** ani v jednom směru.
- **Vybíjení** vyšlo na −0.0028 V/h (fit, rezidua 0.91 mV). Proti −0.0076 V/h z baseline to **není srovnatelné**: jiný úsek vybíjecí křivky (3.97 V proti 4.15 → 4.00), 2.6 h proti 10 h, a baseline měl v sobě kus relaxace po nabíjení. Na výdrž z toho nic nevyvozuj.

#### Co záznam ověřil a co ne

| test | výsledek |
|---|---|
| offset se ve spánku neodečítá | **ověřeno** - skok +2.676 °C při 1. probuzení |
| chyba teploty proti referenci | **ověřeno** - −0.90 proti −3.55 (zbytek otevřený) |
| `battery_level` nepadá do `unknown` | **ověřeno** - 0 z 16 |
| medián přes probuzení funguje | **ověřeno** - žádný výkyv, sd kroku 1.45 mV |
| nabíjení nesepne falešně | **ověřeno** - 0 z 11 kroků, 8× rezerva |
| nabíjení sepne s nabíječkou | **neověřeno** - nabíječka nebyla připojená |
| vlnovka se chová podle okna | **neověřeno** - tlačítko nezmáčknuté |### `2026-08-28-cesta-nabijeni-a-chladnuti/` - 3.5 h v uspávaném režimu, nabíječka a okno chladnutí

**Podmínky.** Baterka dojetá do vypnutí (nechaná vybít, zařízení se samo
vyplo). V **19:28** zapojená nabíječka - zařízení se tím okamžitě
nabootovalo, protože XIAO bere napájení z USB, jakmile je připojené, a
nečeká na článek. Hned při tom bootu přepnuto na **CESTA** (interval 10 min).
Připojení k HA zapnuté, takže menu hlásí CUSTOM, ne CESTA. Nabíječka
odpojená ve **20:34**, tedy po 66 minutách. Zbytek záznamu leží krabička
v klidu, displej zhasnutý, jen časovaná probuzení. Referenční teploměr
vedle, odečty v [`reference-thermometer.md`](2026-08-28-cesta-nabijeni-a-chladnuti/reference-thermometer.md).
Záznam končí ve 22:59, export se stahoval ve 23:08.

Účel byl zavřít dva hardwarové testy, které ověřovací záznam z 23. 8.
nedosáhl: **sepnutí nabíjení ve spánku** a **chování vlnovky**. První
prošel, druhý ne úplně - viz konec sekce.

**22 probuzení**, kadence 10.42 min, jedno z nich je probuzení tlačítkem
ve 19:30:52 (2.4 min po bootu, tedy ne časovač).

#### 1. Probuzení tlačítkem funguje - a `cold_boot` se u něj chová správně

Tohle nebyl plánovaný nález, ale je to nejdůležitější řádek celého
záznamu: `wakeup_pin` na ESP32-C3 byla neověřená od začátku projektu.

Probuzení ve 19:30:52 je od bootu vzdálené 2.4 min, zatímco interval je
10 min - časovač to být nemůže. A publikovaná teplota u něj je **21.940 °C**
proti **18.880 °C** o dvě minuty dřív. Ten rozdíl +3.06 °C je klidový
offset, který se **neodečetl**, plus reálný ohřev z rozjeté nabíječky.
Zařízení tedy ten boot vyhodnotilo jako probuzení, ne jako studený start.

Znamená to dvě věci najednou: tlačítko probouzí, a `esp_sleep_get_wakeup_cause()`
vrací u GPIO probuzení správnou hodnotu, takže se offset i vlnovka
větví, jak mají. Kdyby vracelo `UNDEFINED`, teplota by po každém
zmáčknutí tlačítka spadla o 2.46 °C.

#### 2. `Charging` sepne ve spánku - do 13 minut

**Test prošel.** Nabíječka připojená v 19:28, `Charging` naskočilo
v **19:41:27**, tedy na prvním probuzení, na kterém to vůbec bylo možné -
pravidlo potřebuje napětí z předchozího probuzení, a to bylo poprvé
k dispozici právě tam. Krok byl **+43.6 mV** proti prahu +20.

Kroky napětí během nabíjení, v mV proti minulému probuzení:

```
19:41 +43.6   19:51 +115.8   20:02 +93.7   20:12 +52.3   20:23 +98.2   20:33 +35.1
```

Nejmenší z nich je 35 mV, tedy pořád **1.75x nad prahem**, a to i na konci
nabíjení, kde proud dobíhá. Sweep predikoval ~+40 mV za deset minut;
naměřený medián je +72. Práh +20 tak sedí uprostřed rezervy z obou stran -
ověřovací záznam z 23. 8. ukázal, že šum vybíjení ho nedosáhne ani
osminásobně, tenhle ukazuje, že skutečné nabíjení ho překročí nejmíň
1.75krát.

Baterka za těch 66 minut vyrostla z **3.129 V / 11.5 %** na **3.901 V / 80.4 %**.
Po odpojení klesla na 3.827 V / 73.9 % - těch 6.5 procentního bodu je
nabíjecí napětí, ne kapacita, takže procenta odečtená **při zapojené
nabíječce jsou nadhodnocená**.

#### 3. Vypnutí nabíjení sedí na pravidlo přesně - a odhalilo drobnost

`Charging` zhaslo ve **21:15:04**, tedy 41 minut po odpojení. Pravidlo chce
tři po sobě jdoucí záporné kroky a tady na to bylo potřeba čtyři
probuzení. Proč, je vidět v datech:

| probuzení | krok | `discharge_confirm_count` |
|---|---|---|
| 20:43:50 | **0.0 mV** (medián zopakoval hodnotu) | vynulován |
| 20:54:12 | −41.9 mV | 1 |
| 21:04:39 | −16.7 mV | 2 |
| 21:15:04 | −4.3 mV | 3 → vypnuto |

Ta nula není chyba měření - je to medián, který vydal tentýž vzorek jako
minule. Pravidlo ale testuje `step < 0`, takže **nulový krok spadne do
větve "ani pokles" a čítač vynuluje**. Zopakovaná hodnota přitom není
důkaz nabíjení; je to jen mlčení.

Za celý záznam se medián zopakoval **ve 3 z 22 probuzení** (14 %), takže
očekávané zdržení je zhruba půl probuzení.

**Napadlo mě to spravit změnou na `step <= 0` a sweep to zamítl.**
`data/threshold-sweep.py` tu variantu pouští přes všechny čtyři záznamy a
na nabíjení z prázdné baterky vypne příznak v **17:12 místo 18:08**, tedy
**o 56 minut dřív** - přesně uprostřed ploché CV fáze, kde napětí stojí a
nulové kroky jsou běžné. To je ten samý typ chyby, proti kterému bylo
`< 0` původně vybrané. Úvaha "přesná nula vzniká jedině zopakovaným
mediánem" platí jen na tomhle záznamu; v CV fázi vzniká i normálním
během. **Zůstává `step < 0`**, a zdržení o jedno probuzení je přijatelná
cena za to, že se příznak neuvolní hodinu před koncem nabíjení.

#### 4. Okno chladnutí je skoro dvakrát delší, než chladnutí trvá

Poprvé máme změřené, jak dlouho krabička po nabíjení opravdu chladne.
Odchylka BMP180 od ustálené hodnoty (22.477 °C) po odpojení ve 20:34:

| od odpojení | teplota | odchylka |
|---|---|---|
| +10 min | 25.109 | +2.63 |
| +30 min | 23.367 | +0.89 |
| +41 min | 22.962 | +0.49 |
| +62 min | 22.587 | +0.11 |
| **+72 min** | 22.544 | **+0.07** |
| **+83 min** | 22.483 | **+0.01** |
| +145 min | 22.477 | 0.00 |

Do ±0.1 °C je krabička za **72 minut**, do ±0.05 °C za **83**. Okno
`cooldown_min` je přitom 150 započtených minut, což při 4% pomalejším
čítači dělá **~156 minut reálných**. Je tedy zhruba **1.9x delší, než by
muselo být**.

Není to chyba - okno bylo odvozené z logaritmického fitu a být na jistotě
delší je správný směr. Ale teď je změřené, takže kdyby někdy vadilo, že
vlnovka visí zbytečně dlouho, je z čeho ho zkrátit.

Vrchol ohřevu je mimochodem **+4.12 °C** nad ustálenou hodnotou (26.594 °C
ve 20:23, 55 min od zapojení). To je **třetí** záznam nabíjení a zároveň
největší číslo ze všech tří: +4.12 z dojeté baterky, +3.7 z prázdné,
+2.35 z 64 %. Rozpětí 1.8 °C jen podle počátečního stavu - argument, proč
`CHARGE_OFFSET_*` zůstávají 0.0, je tím potvrzený potřetí.

#### 5. Teplota proti referenci: −0.94 °C, a je to reprodukovatelné

Tři odečty v ustáleném stavu dávají **−0.94 °C** (sd 0.02) proti −0.90
(sd 0.18) z 23. 8. Dva nezávislé záznamy, jiný den, jiný stav baterky,
jiná výchozí teplota - zbytková chyba je tedy **reprodukovatelná**, ne šum
jednoho měření.

Uživatel navíc dodal, **který teploměr to je**: starší lihový s modrou
kapalinou, a je to ten samý kus jako při kalibraci offsetů v
`2026-08-22-rest-offset/`. Tím se dá dopočítat něco, co dosud nešlo.

Konstanta 2.46 byla nastavená jako `raw − teploměr` v DOMA, takže tam
zařízení sedí na teploměr **z definice**. V CESTA se neodečítá a
self-heating tam podle duty cyklu není. Odečtením obou vztahů vypadne
chyba teploměru i chyba senzoru a zůstane:

> **Skutečné self-heating v nepřetržitém provozu je 3.40 °C**, ne 2.46 -
> a tohle číslo nezávisí na tom, jak přesný ten teploměr je.

Konstanta 2.46 tedy nikdy nebyla čisté self-heating, ale **rozdíl** ohřevu
3.40 a chyby BMP180 proti referenci −0.94. Dokud se odečítala v obou
režimech, nezáleželo na tom. Od chvíle, kdy se odečítá jen při studeném
startu, ano: **DOMA teď čte o 0.94 °C výš než CESTA** ve stejné místnosti.
To je fakt o zařízení, ne o teploměru.

**Který z těch dvou režimů je ten správný, rozhodnuté není** a dalšími
odečty tím samým teploměrem to rozhodnout nejde - jeho chyba se z nich
nevydělí. Rozhodne druhý referenční teploměr, nebo prohození míst krabičky
a teploměru. Celé odvození je v
[`reference-thermometer.md`](2026-08-28-cesta-nabijeni-a-chladnuti/reference-thermometer.md).

#### 6. Procenta baterky: 0 výpadků ve 22 probuzeních

`battery_voltage` i `battery_level` mají **nula** řádků `unknown`, zatímco
CO2, teplota a tlak jich mají 18-22 (jeden na každé připojení). Stejná
asymetrie jako v ověřovacím záznamu a stejný závěr: chybějící řádky nejsou
výpadky. Řádků je 19 na 22 probuzení a ty tři chybějící jsou probuzení,
kde medián vydal **bit-identickou** hodnotu.

Že se ta probuzení opravdu odehrála, dokazuje `charging_duration`: ve
20:43:50 hlásí 70 minut, což je hodnota, kterou nastavuje ta samá lambda,
co publikuje napětí. Lambda tedy běžela, jen publikovala totéž co minule.

#### Ostatní veličiny

- **CO2** běželo ve **všech 22 probuzeních**, 3-10 čtení na probuzení,
  rozsah 536-1073 ppm. Vyvětraná místnost, žádné výpadky.
- **Teplota a vlhkost ze SCD41** jsou celý záznam `unknown`, jak se čeká -
  `SCD41_SETTLE_MS` je 3 min proti ~26 s vzhůru.
- **Tlak** publikoval na každém probuzení, bez výkyvů.

#### Stav hardwarových testů po tomhle záznamu

| test | výsledek |
|---|---|
| probuzení tlačítkem z deep sleepu | **prošlo** - 19:30:52, a `cold_boot` se u něj větví správně |
| `Charging` sepne s nabíječkou ve spánku | **prošlo** - 13 min, krok +43.6 mV proti prahu +20 |
| `Charging` vypne po odpojení | **prošlo** - 41 min, přesně na tři potvrzení |
| chyba teploty proti referenci | **reprodukovaná** - −0.94 proti −0.90 z 23. 8. |
| procenta baterky nevypadnou | **prošlo** podruhé - 0 z 22 |
| vlnovka na nahřáté krabičce **je** | **prošlo** - vidět po celou dobu nabíjení |
| vlnovka po vypršení okna **zmizí** | **prošlo** - cap padl ve 22:59:17, odečet s 10s odstupem ji už neukázal |
| vlnovka se na studené krabičce neobjeví | **neověřeno** - chce zvlášť studený start |

**Dovětek: vlnovka nakonec prošla.** Čítač `disturb_minutes` se naposledy
vynuloval na probuzení ve 20:33:30 (poslední krok nad prahem) a od té doby
přičítal 10 na probuzení, takže cap 150 padl přesně na probuzení ve
**22:59:17** - poslední řádek záznamu. Odečet ve 23:08 vlnovku ještě
ukazoval, ale to byl artefakt odečtu: uživatel ji četl hned po zmáčknutí
tlačítka, kdy senzory ještě nestihly publikovat a vlnovka je tam z titulu
`stale`, ne okna chladnutí. Po opakovaném odečtu **s deseti vteřinami
čekání byla vlnovka pryč**, přesně jak předpověď říkala.

Poučení pro příští odečty: vlnovka znamená tři různé věci a dvě z nich
s oknem chladnutí nesouvisí. Stránka **VLHKOST** ji má v uspávaném režimu
**vždycky** (druhý zdroj vlhkosti neexistuje) a **CO2 i TEPLOTA** ji mají
prvních pár vteřin po probuzení. Platný odečet je **TEPLOTA 2** (BMP180)
**aspoň 10 s po zmáčknutí tlačítka**.

### `2026-08-28-co2-dychnuti-v-cesta/` - 42 min, pokus vyvolat CO2 alarm ve spánku

**Podmínky.** Zapnuto vypínačem v **00:22** a hned přepnuto na **CESTA**
(interval 10 min), HA připojení zapnuté. V **00:52** jednou dýchnuto do
krabičky, tedy **do spícího zařízení** - mezi probuzeními. Nabíječka
odpojená. Export obsahuje **jen CO2**, ostatní veličiny v něm nejsou.

Cílem bylo sepnout CO2 alarm (práh 3000 ppm). **Nesepnul** - ale ne z těch
důvodů, které se čekaly, a záznam je proto užitečnější, než kdyby vyšel.

#### 1. Krabička drží vydýchaný vzduch mnohem líp, než se čekalo

Předpoklad před testem byl, že se dýchnutí v neutěsněné krabičce rozptýlí
za minutu za dvě a spící zařízení ho nemá jak zahlédnout. **Není to pravda.**

| probuzení | CO2 |
|---|---|
| 00:22 (boot) | 1183-1193 |
| 00:33 | 1183-1204 |
| 00:43 | 1198-1205 |
| **00:54** (2 min po dýchnutí) | **2304-2313** |
| 01:04 | 1510-1514 |

Z rozpadu 2305 → 1510 proti základu ~1150 vychází časová konstanta
**τ ≈ 8.9 min**, tedy zhruba stejná jako interval spánku. Dýchnutí bylo
o dvě minuty dřív než probuzení a senzor ho pořád viděl skoro celé:
zpětnou extrapolací byla špička kolem **2580 ppm**.

#### 2. Armovací pravidlo v uspávaném režimu funguje

Druhá obava byla, že se alarm ve 30s okně nestihne ozbrojit, protože chce
**tři čtení po sobě do 150 ppm od sebe** a klesající křivka po dýchnutí se
prý bude hýbat moc. Taky mimo: pět čtení v tom probuzení bylo
**2305, 2313, 2307, 2304, 2305**, tedy rozptyl **9 ppm** - dvacetkrát pod
prahem stability. Alarm se ozbrojil na třetím čtení a měl pak dvě čtení na
to sepnout.

Že to takhle sedí, není náhoda: `co2_alarm_armed` je `restore_value: false`,
takže se každé probuzení armuje znovu od nuly. Na to jsou v 30s okně přesně
tři čtení na ozbrojení a dvě na rozhodnutí. **Rezerva je tenká, ale je.**

#### 3. Nesepnul jediný důvod: bylo toho málo

Do prahu chybělo **695 ppm**. Jedno dýchnutí zvedlo hladinu asi o 1400 ppm
nad základ, potřeba je zvednout ji o 1850. Nic víc v tom není - žádné
zaspání, žádné neozbrojení, žádná chyba pravidla.

**Pro příští pokus:** dýchat víc (několikrát po sobě), a ideálně těsně před
probuzením. Při τ ≈ 9 min hladina mezi dýchnutím a probuzením spadne jen
o zlomek, takže stačí trefit se do jednoho intervalu. Alarm se pozná tak, že
**zařízení přestane spát a displej zůstane svítit** - `co2_alarm_active`
nastavuje `stay_on` a uspávání je tou proměnnou blokované
([`packages/menu.yaml`](packages/menu.yaml)).

#### 4. Vedlejší potvrzení

Probuzení chodila v **00:22, 00:33, 00:43, 00:54, 01:04**, tedy kadence
10.4 min jako všude jinde, a CO2 se rozjelo **v každém z nich** (5 čtení na
probuzení). To je další sada k těm 72 + 22 probuzením, kde `stop`/`start`
periodického měření spolehlivě funguje.

## Nové měření - jak ho sem přidat

1. V HA: **History** → vybrat entitu (nebo víc) → časový rozsah → **Download data**.
2. Nová složka `RRRR-MM-DD-co-se-měřilo`, CSV pojmenovat podle veličiny (`co2.csv`, `temperature-scd41.csv`, `battery-voltage.csv`, …).
3. Přidat sem odstavec: **za jakých podmínek** to běželo (režim DOMA/CESTA, displej, nabíječka, kde krabička ležela) a co z toho vyšlo. Bez podmínek jsou ta čísla skoro k ničemu - hodnota se dá vždycky dopočítat, kontext ne.

### Co ještě chybí změřit

- ~~Klidový offset bez nabíječky~~ **HOTOVO**, viz `2026-08-22-rest-offset/` výš - oba offsety jsou teď změřené proti referenci.
- ~~CESTA transient test~~ **HOTOVO**, viz `2026-08-22-cesta-wake-cycles/` výš - skok se opakuje při každém probuzení a je ~5.5 °C.
- ~~Teploty při nabíjení~~ **HOTOVO**, dvakrát: `2026-08-22-charging-from-empty/` (+3.7 °C) a `2026-08-23-charging-warm/` (+2.35 °C). `CHARGE_OFFSET_*` zůstávají `0.0` **záměrně** - ty dva záznamy dokazují, že konstanta neexistuje.
- **Napětí děliče multimetrem ve spodku rozsahu** - násobič 3.2 je ověřený ve dvou bodech: 4.15 V a **3.81 V** (28. 8. 2026, HA 3.81 proti multimetru 3.81-3.82, tedy shoda v mezích odečtu). Tím zároveň padlo podezření, že dělič podhodnocuje o ~2 % - taková chyba by při 3.81 V dělala 76 mV a byla by vidět. **Plná baterka opravdu končí kolem 4.12 V.** Zbývá odečet kolem **3.5 V a níž**, kde by se nelinearita ADC projevila nejvíc. Podmínky odečtu z 28. 8.: sonda na **B+ přímo na baterce**, černá na **GND XIAO** - tedy proti té samé zemi, proti které měří ADC, takže se do srovnání nemíchá úbytek na trase. Krabička v **CESTA** s rozsvíceným displejem v režimu **STAY** (vzhůru, pod zátěží), **nabíječka odpojená**.
- ~~CESTA baseline~~ **HOTOVO**, viz `2026-08-23-cesta-baseline/` výš - předpověď seděla: v uspávaném režimu se odečítal offset, který tam není, a teplota vycházela **3.55 °C pod realitou**. Opraveno a ověřeno na hardwaru, viz `2026-08-23-cesta-po-oprave/`.
- ~~Ověření oprav v2 na hardwaru~~ **ČÁSTEČNĚ**, viz `2026-08-23-cesta-po-oprave/` výš - offset, procenta baterky, medián přes probuzení i absence falešného nabíjení sedí. Dvě věci ten záznam neověřil a zůstávají otevřené (níž).
- **Druhý referenční teploměr** - tohle je teď jediná cesta, jak zavřít rozdíl **0.94 °C mezi DOMA a CESTA**. Reference je starší lihový teploměr s modrou kapalinou (tolerance u tohohle typu ±1 °C) a proti němu se kalibrovaly klidové offsety, takže DOMA na něj sedí z definice a CESTA je o 0.94 vedle. Rozdělit to na chybu senzoru a chybu teploměru z jednoho přístroje nejde - **další odečty tím samým teploměrem už nic nerozhodnou**. Chce to druhý kus, nejlépe jiného typu, nebo prohodit místa krabičky a teploměru (musí se otočit znaménko). Odvození je v `2026-08-28-cesta-nabijeni-a-chladnuti/reference-thermometer.md`.
- ~~Sepnutí nabíjení v uspávaném režimu~~ **HOTOVO**, viz `2026-08-28-cesta-nabijeni-a-chladnuti/` výš - příznak sepnul **13 min** po zapojení nabíječky, na prvním probuzení, kde to pravidlo vůbec spočítat mohlo, krokem +43.6 mV proti prahu +20. Vypnul 41 min po odpojení. Nejmenší krok za celé nabíjení byl 35 mV, tedy 1.75× nad prahem.
- **Vlnovka na displeji** - **skoro hotovo**. `2026-08-28-cesta-nabijeni-a-chladnuti/` ověřil obojí na nahřáté krabičce: po celou dobu nabíjení vlnovka **je**, a po vypršení okna (cap čítače padl na probuzení ve 22:59:17) **zmizí**. Zbývá jediné: že se na **studené** krabičce neobjeví vůbec - vypnout na hodinu, zapnout, hned přepnout na CESTA. Odečítat se to musí na stránce **TEPLOTA 2** a **aspoň 10 s po zmáčknutí tlačítka**: VLHKOST má v uspávaném režimu vlnovku vždycky a CO2 i TEPLOTA ji mají prvních pár vteřin po probuzení.
- **Teplota a vlhkost ze SCD41 v uspávaném režimu** - obojí je tam trvale `unknown`, protože `SCD41_SETTLE_MS` je 3 min proti ~25 s vzhůru. Dnes je to vědomé a zdokumentované, ale znamená to, že jediný zdroj teploty v CESTA je BMP180. Jestli se s tím má něco dělat, není rozhodnuté.

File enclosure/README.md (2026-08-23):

# Kryt

| Verze | Soubor | Materiál |
|---|---|---|
| **v2 (aktuální)** | [`case v2.3mf`](case%20v2.3mf) | **Aurapol PETG** |
| v1 (historická) | [`case.3mf`](case.3mf) | Bambu PLA Basic |

Postup sestavení je v [ASSEMBLY.md](../ASSEMBLY.md) a **platí pro v2**.

## Tisková nastavení

Tištěno na **Bambu Lab X1C + AMS** (stejná tiskárna u obou verzí). Materiál se změnil na **Aurapol PETG** - kryt je proti v1 tvrdší a odolnější. Není to Bambu filament, takže profil je potřeba vybrat ručně (generický PETG), ne podle RFID z AMS.

| Parametr | Hodnota |
|---|---|
| Výška vrstvy | 0.2mm |
| Výška vrstvy (tlačítko) | 0.2mm |
| Podpory | Jen u tlačítka a u předního krytu |

Proti v1 se tisklo tlačítko na 0.16mm, ve v2 jde celý model na jednotných **0.2mm**.

Model má zapracované tolerance, díly by měly sedět bez dodatečného úpravování.

## Tisk bez AMS

Vícebarevný je jediný díl - **přední tlačítko** se symbolem napájení. Bez AMS ho stačí vytisknout jednobarevně, ikonka pak zůstane jako reliéf. Na funkci to nemá vliv.

## Co se změnilo ve v2

- **PETG místo PLA**, o něco větší kryt
- **Spodní kompartment pro teplotní senzory** - oddělený přepážkou od baterky, TP4056 modulu i ESP32, tedy od všeho, co uvnitř topí. Zavírá ho vlastní záklopka, která se zatavuje.
- **Symbol napájení** ⏻ na tlačítku
- **Tlačítko se natavuje přímo na přední kryt** (ve v1 na stranu s baterií)
- **Jiné rozmístění stacku** - TP4056 podél baterky místo pod ní, anténa nahoře vepředu místo dole pod sestavou

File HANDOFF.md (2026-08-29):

# HANDOFF: Air Quality Monitor - kompletní stav projektu

Tento dokument je určen pro AI asistenta, který na projektu pokračuje po mně. Shrnuje celou historii, klíčová rozhodnutí, aktuální stav firmwaru a otevřené věci. Ostatní soubory v tomhle balíčku (README.md, WIRING.md, ASSEMBLY.md, air-quality-monitor.yaml) jsou aktuální projektová dokumentace/kód - tenhle dokument je navíc, jako kontext a historie k nim.

**Poslední aktualizace:** 29. 8. 2026. Firmware je označený za **stabilní a nasazený**; soupis toho, co zůstává nedodělané, je v sekci „STAV K 29. 8. 2026“ hned pod v2 STATUS.

---

## v2 STATUS (nejnovější - čti tohle první)

Probíhá **kompletní redesign firmwaru pro v2** (stejný hardware/zapojení jako v1, ale nový kryt + přidaný hlavní vypínač baterie mezi baterkou a TP4056). Zbytek tohohle dokumentu popisuje historii **v1** - pořád platný kontext k tomu, JAK a PROČ vznikla nynější v2 rozhodnutí, ale konkrétní čísla/chování (menu se 3 položkami, vypnutá dynamická korekce, atd.) už neplatí, byla nahrazená.

**Co se v v2 změnilo:**
- `air-quality-monitor.yaml` rozdělený přes `packages:` do `packages/globals.yaml`, `packages/sensors.yaml`, `packages/display.yaml`, `packages/menu.yaml`.
- Menu má teď 6 položek: REZIM (presety DOMA/CESTA, jinak zobrazí CUSTOM), HA PRIPOJENI, INTERVAL SPANKU, DEEP SLEEP, CO2 ALARM, ASC KALIBRACE.
- **ASC toggle implementováno (srpen 2026)** - viz "fáze 3" poznámka níže v historii v1, byla označená jako rizikovější a neimplementovaná, teď hotovo. Mechanismus: `id(scd41_hub).write_command(...)` (raw I2C, `sensirion_common::SensirionI2CDevice::write_command()` - CRC8 řeší samo) v novém `on_boot` kroku (priorita -150) v `air-quality-monitor.yaml`, ne za běhu z menu - menu jen uloží `id(asc_enabled)`, aplikuje se to při dalším rebootu/probuzení. Bez `scd4x.persist_settings` záměrně (NVM senzoru má omezený počet zápisů, nepotřebujeme ho - vlastní flash ESP32 přes `restore_value` stačí). **Overit na hardwaru:** dočasně zvednout `logger: level:` z `NONE`, přepnout ASC v menu, zkontrolovat log při dalším bootu (žádné I2C chyby, CO2 čtení pokračují normálně).
- Menu displej přepracovaný (srpen 2026) - starý layout (název/stav/hint na 3 řádcích) měl dva reálné bugy nahlášené z hardwaru: hint text přesahoval pod tečkový indikátor a kolidoval s ním, a písmenka s ocáskem (vypnout/zapnout/prepnout) se ořezávala o spodní okraj displeje. Nové rozvržení kopíruje styl běžných senzorových stránek (název+pozice nahoře, velká hodnota uprostřed, tečky dole), hint text zrušen úplně (viz README "Menu a presety").
- Korekce teploty při nabíjení: nahrazen starý (vypnutý, přestřelující) časový model jednoduchým plochým offsetem při `is_charging` - žádná křivka, žádné riziko přestřelení. Konstanty (rest-offset i charging-offset) jsou zatím TODO placeholdery - potřeba přeměřit na novém krytu.
- Přidán lokální CO2 alarm (jen displej, bliká při překročení prahu) pro použití bez HA (např. v autě).
- **CO2 alarm settle-gate + rychlejší SCD41 polling (srpen 2026).** Uživatelský postřeh: hodnoty jsou hned po zapnutí "divoké", nemá se z toho spouštět alarm. Cestou k tomu jsem narazil na skrytý pre-existující bug: `PollingComponent`'s FIRST `update()` čeká celý `update_interval` od bootu (ověřeno v ESPHome scheduler zdrojáku, ne odhad) - při starém `update_interval: 60s` na scd4x by CESTA (deep sleep, auto-off/spánek po 30s) šla spát DŘÍV, než dorazilo první čtení CO2 vůbec, takže alarm (a čerstvá data do HA) by se v CESTA módu prakticky nikdy nestihly vyhodnotit. Oprava: scd4x `update_interval` sníženo na 10s (SCD41 stejně interně vzorkuje po 5s, není to za víc energie), plus nový `co2_reading_settled` flag co přeskočí vyhodnocení alarmu na úplně prvním čtení po bootu (resetuje se každý reboot/probuzení).
- **Ověření proti reálným datům z DOMA režimu (srpen 2026, `data/2026-08-22-doma-baseline/`).** Uživatel dodal hodinový HA export (CO2, obě teploty, vlhkost, tlak, napětí, charging) z běžícího v2 firmwaru, displej vypnutý, bez nabíječky (uživatel psal obojí - data rozhodla: `charging` off celou dobu a napětí monotónně klesá). Co z toho vyšlo:
  - **Teplotní offsety v2 sedí.** SCD41 25.09-25.27 °C celou hodinu (10min průměry 25.12-25.21, žádný náběh), BMP180 24.69-24.79 °C, tj. rozdíl jen 0.44 °C mezi dvěma nezávisle offsetovanými senzory. Uživatel je nezávisle označil za správné. `temperature_offset: 5.6°C` a `REST_OFFSET_BMP180: 1.74f` přenesené z v1 tedy na novém krytu platí - TODO komentáře v `sensors.yaml` zmírněné na "ověřeno proti 1h záznamu, zbývá jedno kontrolní měření teploměrem".
  - **Detekce nabíjení nedělá false-positive.** Simulace algoritmu nad reálnou vybíjecí řadou: max trend **-0.0003 V** proti prahu +0.015 V. Tím je detekce ověřená z obou stran (nabíjení už dřív v praxi, teď i vybíjení).
  - **Median-of-3 na napětí prokazatelně funguje.** Ze 64 očekávaných čtení jen 42 změn v HA = 22× bit-identická hodnota s předchozí, což je přesně podpis mediánu (znovu vydá dřívější vzorek); u syrového ADC šumu by se float hodnoty takhle neopakovaly. Zbytkový šum ~0.018 V.
  - **Vybíjení v DOMA: -0.08 V/h** (WiFi zapnutá, displej vypnutý).
  - **Nalezený bug: BMP180 pustí občas jedno úplně vedlejší čtení.** 01:56:54Z teplota 24.409 mezi sousedy ~24.70 **a zároveň** tlak 956.407 proti ~957.05 - jedno špatné I2C čtení, obě veličiny naráz. BMP180 do té doby neměl žádný filtr. Opraveno `median` filtrem (okno 3, `send_every: 1` - **default je 5**, to by publikovalo jen každé páté čtení) na obou veličinách, zapojeným **před** korekční lambdu, aby se čistila i cachovaná hodnota (stejná split-brain past jako u `battery_voltage`).
- **Zahřívání po studeném zapnutí (srpen 2026).** Rešerše (Sensirion datasheet + ESPHome zdroják) rozdělila dvě věci, co se předtím míchaly dohromady: CO2 potřebuje zahodit první čtení a >3 min na plnou přesnost (vlastnost senzoru, τ63 % = 60 s), zatímco teplota potřebuje desítky minut - a to není o čipu, ale o tepelné rovnováze krabičky, protože `temperature_offset` platí jen v rovnováze. Datasheet proto žádné číslo nedává, jen "in thermal equilibrium". Firmware: `~` před hodnotou na obou teplotních stránkách **a na vlhkosti** (SCD41 ji počítá z té samé teploty) prvních 20 min po studeném startu. Původně to bylo 30 min z ničeho; **20 min je teď odvozeno z reálných dat** - viz bod níž.
- **Změřeno na reálném záznamu po zapnutí (srpen 2026, `data/2026-08-22-power-on-warmup/`).** Křivka má **dvě fáze, které spolu nesouvisí**: (a) 0-1.5 min SCD41 hlásí **+2.5 °C nad plató**, vlhkost -14 %, CO2 +56 ppm, prudce klesá; (b) 1.5-3 min podstřelí o 0.5 °C dolů; (c) 3-15 min se teprve zahřívá krabička, τ = 3.1 min (SCD41) / 5.9 min (BMP180). Doby ustálení: SCD41 do ±0.1 °C od 12.0 min, BMP180 od 9.0 min, vlhkost do ±0.5 % od 10.9 min, CO2 do ±15 ppm od 14.2 min.
  - **Nebyl to studený start** - BMP180 vyrostl celkem jen o 0.37 °C, ale jeho klidový offset je 1.74 °C; vychladlý box by musel vyrůst zhruba o těch 1.74. Uživatel potvrdil: vypnuté jen pár minut. Naměřená čísla jsou tedy spodní mez. `WARMUP_MS = 20 min` proto vychází z τ-extrapolace (BMP180 τ=5.9 min, z plných 1.74 °C na ±0.05 °C = 20.9 min), ne z přímého odečtu.
  - **POZOR - zpochybňuje předchozí předpoklad o deep sleepu.** Ta úvodní fáze **není tepelná**: box byl při zapnutí prakticky na provozní teplotě, takže čip SCD41 musel být *chladnější* než jeho ustálených 30.6 °C raw, a přesto hlásil 33.1. Vychladlý čip nemůže hlásit vysoko. BMP180 dělá pravý opak (startuje na minimu a roste). Vypadá to tedy na chování SCD41 po `start_periodic_measurement` - a ten ESPHome posílá **při každém bootu včetně probuzení z deep sleepu**. V CESTA je zařízení vzhůru 30 s → celé okno by padlo doprostřed skoku, každé probuzení by ukazovalo o ~2 °C víc. **Firmware s tím záměrně nic nedělá, dokud to není ověřené** (viz otevřené položky).
- **OPRAVA dřívějšího tvrzení: PollingComponent NEČEKÁ celý interval.** V `sensors.yaml` (a v tomhle souboru) bylo napsané jako ověřený fakt, že první `update()` přijde až po celém `update_interval`. **Není to pravda.** `Scheduler::calculate_interval_offset_` plánuje první běh na `now + random[0, min(interval/2, 5000ms))`, tedy do 5 s. Skutečný důvod, proč 60s interval nefungoval v CESTA: ten první brzký poll přijde dřív, než má SCD41 `data_ready` (driver stráví ~1.5 s vlastní stop/configure/start sekvencí a senzor pak potřebuje dalších ~5 s), takže se přeskočí - a další je o celý interval dál, to už zařízení spí. Data to potvrzují: BMP180 s 60s intervalem publikoval ~3 s po bootu, SCD41 s 10s až v 11 s. **Závěr (5s je správně) platí dál**, jen zdůvodnění bylo špatné; komentář v `sensors.yaml` je přepsaný a explicitně na tu starou chybu upozorňuje.
- **CO2 alarm: settle-gate nahrazen stabilitním armováním (srpen 2026).** Původní verze (bod výš) přeskočila jen první čtení po bootu (10 s), což na "divoké hodnoty po zapnutí" nestačí. Teď: alarm se povolí, až jsou **3 čtení po sobě v rozsahu <150 ppm**; pojistka - po 3 min uptime se povolí tak jako tak (radši hlídat s nejistotou než nehlídat); jednou povolený se **už nedearmuje** (reálný rychlý nárůst CO2 v autě by rozptyl překročil a alarm by zmizel přesně ve chvíli, kdy je potřeba). Globál `co2_reading_settled` → `co2_alarm_armed` + `co2_hist1`/`co2_hist2`. Kvůli tomu `update_interval` scd4x z 10s na **5s** (= vlastní interní rychlost SCD41, nestojí to víc energie senzoru): v CESTA je zařízení vzhůru jen 30 s, při 10s intervalu jsou to 3 čtení a na vyhodnocení stability nezbývá prostor. Ověřeno simulací nad `data/2026-08-22-doma-baseline/co2.csv`: na ustálených datech se armuje na 3. čtení (15 s), na syntetickém divokém startu (40000→5200→2400→1900→…) až na 6., a na trvale šumících datech spadne na 3min pojistku. Aby 5s polling nezdvojnásobil zápisy do HA recorderu, přidán `delta: 0.05` na teplotu SCD41 a `delta: 0.1` na vlhkost - **za** lambdu, takže cache se pořád plní každým čtením.
- **STUDENÝ START (srpen 2026, `data/2026-08-22-cold-start/`) - 6.5 h záznam, vypnuté ~1 h předtím, běželo do vybití baterky. Nejcennější záznam, odpověděl na tři věci najednou.**
  - **`WARMUP_MS` 20 → 45 min.** BMP180 se ustálí kolem 24.15 °C (plató od 60. min); zbývající chyba: −1.11 °C v 10. min, −0.58 ve 20., −0.34 ve 30., −0.18 ve 40., −0.06 v 50. τ = 13-15 min, ustálení ≈ 3τ. **Moje předchozí hodnota 20 min byla špatně** - vznikla extrapolací z `power-on-warmup`, což byl teplý restart; fit exponenciály na krátký, skoro ustálený ocas dal τ = 5.9 min, tedy necelou polovinu skutečné, a extrapolace přestřelila o víc než 2×. **Poučení do budoucna: τ fitovaná přes krátké okno se nedá extrapolovat na plnou amplitudu.**
  - **Úvodní skok SCD41 je PROKAZATELNĚ artefakt senzoru**, ne teplota - dřív to byla hypotéza, teď dva nezávislé důkazy z jednoho záznamu: (a) ze studeného startu hlásí SCD41 v t=6 s o **2.13 °C víc** než BMP180, ve 2. minutě je naopak **pod ním**, pak se srovnají na +0.49 °C - studený čip nemůže hlásit vysoko; (b) při brownout restartu (10:45:15Z) skočil z 24.04 na **28.42 °C (+4.37) za necelých 38 s**, zatímco BMP180 stál na 23.60/23.59/23.58 - reálná změna 4.4 °C při klidném druhém senzoru je nemožná. Systematická kontrola: skoky >1 °C za celých 6.5 h jsou **přesně dva**, oba na restart. Rozdíl SCD41−BMP180 drží +0.46 až +0.53 °C celých šest hodin.
  - **Vysvětlena anomálie, kterou nahlásil uživatel** ("HA pak ukazovalo data, která neměřil"): jak baterka umírala, zařízení se dvakrát brownout-restartovalo a pokaždé publikovalo transient. Poslední, co HA dostalo a pak na tom zůstalo viset: **27.43 °C** (realita 23.58) a **53.7 % RH** (předtím 64.96). Navíc to vypadá jako dvě měření, i když je jen jedno - po krátkém výpadku spojení poslalo ESPHome ty samé stavy z RAM znovu a HA to zalogovalo jako změnu (entita byla mezitím `unavailable`); poznat podle **bit-identických floatů** (2.93834662437439 dvakrát, u 30× oversamplovaného ADC nemožné náhodou).
  - **OPRAVENO:** nový lambda filtr v `sensors.yaml` na `temperature:` i `humidity:` SCD41 - `if (millis() < 3min) return {};`. Vrací prázdno, takže se čtení **ani nepublikuje, ani necachuje** a displej dál padá na poslední známou dobrou hodnotu. Záměrně **NE** na `co2:` - jeho transient je ~56 ppm proti prahu 3000 a zahazování CO2 by v CESTA (30 s vzhůru) vyhladovělo arming pravidlo alarmu.
  - **Důsledek pro CESTA, který je potřeba vyřešit:** v CESTA neprojde tím filtrem nic (30 s < 3 min), takže teplota/vlhkost zůstanou na poslední cachované hodnotě a nikdy se neaktualizují. Není to regrese (CESTA teplota byla špatná už předtím, jen neviditelně), ale je to slepá ulička. **Nejnadějnější řešení: brát v CESTA teplotu z BMP180**, který transient nemá vůbec (viz důkaz (b) výš) a se SCD41 se za ustáleného stavu shodne na 0.49 °C. Vlhkost by šla dopočítat Magnusem z BMP180 teploty - ta mašinérie v `humidity:` filtru už existuje kvůli charging offsetu. **Nerozhodnuto, čeká na uživatele.**
  - Vedlejší: vybíjení 3.79 → 2.94 V za 6.5 h = **~0.13 V/h** v DOMA (víc než −0.08 V/h z baseline, baterka byla níž ve vybíjecí křivce).
- **NABÍJENÍ + PRVNÍ REFERENČNÍ TEPLOMĚR (srpen 2026, `data/2026-08-22-charging-from-empty/`)** - 4 h, nabíjení z úplně vybité baterky, nabíječka zapojená celou dobu, vedle položený lihový teploměr s ručními odečty (ty jsou v `reference-thermometer.md` v té složce, **v CSV nejsou**). Export je poprvé jeden soubor pro všechny entity (`all-sensors.csv`, rozlišuje `entity_id`).
  - **Teplo z nabíjení = +3.7 °C ve vrcholu**, a `CHARGE_OFFSET_*` proto zůstávají `0.0` - **teď už jako změřené rozhodnutí, ne placeholder**. Průběh nad ustáleným stavem: +3.4 ve 30. min, **+3.7 ve 40. min (vrchol)**, +3.6 v 60., +1.7 ve 100., +0.3 ve 150., 0 v 170. Reference se přitom držela na 23.8-24.2 °C. Stejný tvar na BMP180 (+3.8), takže se ohřívá celá krabička. **Konstanta to opravit nemůže:** teplo je úměrné nabíjecímu proudu a ten závisí na tom, jak prázdná baterka byla; průměr přes cyklus (~1.8 °C) je vedle v obou směrech. Křivka podle času selže stejně - to je přesně v1 model, co přestřelil o ~4 °C. **Řešení: neopravovat, jen označit** - displej dává `~` během `is_charging` (packages/display.yaml).
  - **První absolutní kontrola offsetů.** Po ustálení (nabíjení dokončené) čte SCD41 o **+0.5 až +1.0 °C** víc než lihový teploměr, BMP180 o **+0.3 až +0.7**. Vypadá to, že oba offsety jsou o tolik malé. **Zatím se nic nemění**, protože (a) lihový teploměr má přesnost ±0.5 °C a v poslední hodině skočil o 1.1 °C, zatímco senzory se pohnuly o 0.15 - část rozdílu je chyba odečtu; (b) nabíječka byla pořád zapojená, takže i "ustálený" stav nese zbytkové teplo. Uzavře to jedno 45min měření bez nabíječky, viz otevřené položky.
  - **Mobilní teploměr je k ničemu** - za 30 min ukázal pokles 23.4 → 22.0 °C, zatímco lihový stál a senzory naopak rostly. Telefon měří vlastní čip, jak se po odložení ochlazuje. Do budoucna nepoužívat.
  - **`Charging` nepozná konec nabíjení.** Sepnulo správně 5 min po zapojení, ale vyplo se **přesně po 3 h 00 min 03 s** = bezpečnostní pojistka, ne detekce. Skutečné nabíjení skončilo o hodinu dřív (napětí přestalo růst na 4.150 V a začalo mírně klesat). Pokles po dobití je jen ~0.0009 V/min a nikdy nepřekročí práh -0.01 V proti baseline. `Charging = on` tedy znamená "nabíjelo se někdy za poslední 3 h", ne "teče proud teď". **Opraveno** - viz bod 2f v otevřených úkolech (a pozor, opravovalo se to dvakrát).
  - **Potvrzena ta zamrzlá hodnota**: v 16:15, před bootem, HA pořád ukazovalo SCD41 27.43 °C a BMP180 23.58 - přesně hodnoty z brownoutu v předchozím záznamu, visely tam hodiny. Přímé potvrzení, že ta oprava (zahazování prvních 3 min) byla potřeba.
  - **Ověřen Magnusův přepočet vlhkosti**: RH šla 77 → 60 % zatímco teplota rostla 23.8 → 28.6. Magnus z toho předpoví 58 %, naměřeno 60.5. Ta změna vlhkosti tedy není skutečná, je to jen důsledek nadhodnocené teploty - a přepočet v `humidity:` filtru počítá správně.
- **CESTA WAKE TEST (srpen 2026, `data/2026-08-22-cesta-wake-cycles/`) - otázka 2d ZODPOVĚZENA: ANO, skok se opakuje při každém probuzení, a je ~5.5 °C.** Devět cyklů (DEEP SLEEP on + HA on = CUSTOM, interval 5 min), pokaždé stejně: SCD41 startuje ~5.5 °C nad BMP180 a za 10 s spadne o 0.72-0.76. Rozptyl prvního rozdílu přes všech devět probuzení: **5.36 až 5.59** - naprosto konzistentní. Když zařízení běželo v kuse (blok před prvním uspáním), byl rozdíl normálních **0.31 °C**. Vlhkost stejně: 61.8 % za běhu vs 46.7-50.6 % při probuzení. BMP180 klesá hladce (24.57 → 22.68 za 50 min, chladnutí ve spánku) a **skok nemá vůbec**.
  - **Mechanismus, který sedí na všechny tři záznamy:** první čtení po `start_periodic_measurement` vypadá, jako by na něj nebyl aplikovaný `temperature_offset` (5.6), a ten se dotáhne během ~2 min. Studený start: čip je stejně studený jako krabička → chybějící offset dělá proti BMP180 (který má vlastní offset 1.74) rozdíl ~1.74-2.1 °C, naměřeno 2.13 ✓. Probuzení ze spánku: čip celou dobu spánku běžel dál a je proti chladnoucí krabičce rozehřátý → totéž dělá ~5.5 °C ✓.
  - **Důsledek: v jakémkoliv režimu s deep sleepem je teplota i vlhkost ze SCD41 nepoužitelná.** 30 s vzhůru je řádově míň než ty ~2 min. Zahazovací filtr (3 min) to správně vyhodí, takže se do HA nedostane nesmysl - ale znamená to, že v CESTA nemá teplota odkud brát. **VYŘEŠENO (srpen 2026):** stránka TEPLOTA zkusí popořadě `temp_scd41` → `temp_bmp180` → cache a vezme první, co má `has_state()`. Klíčované záměrně na "existuje živé čtení", ne na `deep_sleep_mode_enabled` - žádné větvení podle režimu, které by se muselo držet v synchronu, a správně to vyjde i v prvních 3 minutách běžného bootu. Vlhkost druhý zdroj nemá (BMP180 ji neměří), takže tam padá na cache a je označená vlnovkou; Magnus přepočet z BMP180 teploty by šel, ale chtělo by to schovat si syrové RH před zahozením do globálu - neuděláno, zatím nepotřeba.
- **Displej se při probuzení časovačem už nerozsvěcí (srpen 2026, na žádost uživatele).** Nový globál `wake_was_timer` (plněný v on_boot prioritě 600 z `esp_sleep_get_wakeup_cause() == ESP_SLEEP_WAKEUP_TIMER`) a v prioritě -100 se podle něj `display_on` nastaví na false + `oled_display.turn_off()`. Rozsvítí se **jen** po tlačítku nebo studeném startu; když se příčina probuzení nedá zjistit, vyhrává displej (bezpečný směr - jediný výstup zařízení je ta obrazovka). 30s okno vzhůru se nemění, to potřebuje WiFi + API + čtení, s displejem nemá nic společného. CO2 alarm si displej pořád rozsvítí sám.
- **SCD41 běžel i během deep sleepu - hlavní žrout baterky (srpen 2026, opraveno).** Senzor není na napájecí větvi ESP32; 3V3 jde i ve spánku, takže dál měřil po 5 s. Datasheet: 243 mJ na měření → při 5s intervalu **~14.7 mA trvale** proti **0.15 mA** v idle, tedy ~100×, a řádově víc než spící ESP32. Naměřeno: při 5min intervalu a 30 s vzhůru (desetina času) bylo vybíjení jen o ~15 % pomalejší než při nepřetržitém běhu (-0.070 V/h proti -0.082 až -0.089 V/h). Zpětný výpočet z always-on dá ~34 mA = ESP s WiFi (~20) + tenhle senzor (~15). Nezávislé potvrzení: teplotní skok při probuzení je ~5.5 °C proti ~2 °C při studeném startu - tak rozehřátý čip být nemůže, pokud neměří.
  - **Oprava:** `id(scd41_hub).write_command((uint16_t) 0x3F86)` (stop_periodic_measurement) v obou cestách do deep sleepu - ve skriptu `display_auto_off` i v ručním single-click handleru (packages/menu.yaml). Odhad: 3-4× delší výdrž v CESTA.
  - **Proč je to bezpečné:** ESPHome při dalším bootu pošle `stop` znovu, tedy už zastavenému senzoru. To se ale děje při každém studeném startu (SCD4x se po zapnutí probouzí v idle) a studené starty prokazatelně fungují - viz `data/2026-08-22-cold-start/`. `write_command` navíc vrací úspěch podle I2C ACK, ne podle sémantiky příkazu.
  - **Vedlejší efekt k ověření:** čip bude při probuzení studený místo rozehřátý, takže by transient měl klesnout z ~5.5 °C na ~2 °C (jako u studeného startu). Zahazovací filtr (3 min) to pokrývá tak jako tak. **Hlavní věc k ověření na hardwaru: po probuzení musí CO2 spolehlivě naskočit** - to je jediná funkce, která v CESTA nesmí selhat.
  - Druhý největší odběr ve spánku je pak dělič napětí: 220k+100k = 320 kΩ přes baterku = ~12.8 µA trvale. Proti ESP ve spánku (~5 µA) to není nic (0.3 mAh/den), řešit se to nemusí.
- **KALIBRACE TEPLOTY ZAVŘENÁ (srpen 2026, `data/2026-08-22-rest-offset/`).** Konečně měřeno proti referenčnímu teploměru za správných podmínek: **nabíječka i USB odpojené** (během flashování jde XIAO z 5 V USB, na baterce z ~4.1 V, a rozdíl se pálí v LDO - to znečistilo předchozí pokus), DOMA, displej zhasnutý, 49 min na ustálení, tři odečty po pěti minutách, všechny shodně 23.9 °C.
  - SCD41 četl **+1.07 °C** → `temperature_offset` 5.6 → **6.7**
  - BMP180 četl **+0.72 °C** → `REST_OFFSET_BMP180` 1.74 → **2.46**
  - Obě kontroly platnosti prošly: rozdíl mezi senzory 0.35 °C (očekáváno 0.3-0.5) a BMP180 se přes všechny tři odečty pohnul jen o 0.090 °C. Ta druhá je podstatnější, než vypadá - oba senzory za vzduchem zaostávají o svou časovou konstantu (11-15 min), takže drift v místnosti by se započítal jako chyba offsetu. Zbytkový drift značí, že snad 0.1 °C z těch 1.07 je zpoždění - hluboko pod vlastní přesností teploměru (~0.5 °C), nemá smysl to odčítat.
  - **Vedlejší efekt:** změna `temperature_offset` posune i vlhkost, protože SCD41 počítá RH ze své offsetem opravené teploty - vyjde asi o 4 procentní body výš. Správný směr, ale nemáme čím ověřit (vlhkoměr jako reference chybí). **CO2 to neovlivní** - podle Sensirionu offset kondicionuje jen výstupy T a RH.
- **NOČNÍ ZÁZNAM V USPÁVANÉM REŽIMU (srpen 2026, `data/2026-08-23-cesta-baseline/`) - 12.4 h, otázka výdrže ZAVŘENÁ, ale vypadly z toho tři nové bugy.** Deep sleep, interval 10 min, HA připojení nechané zapnuté (jinak by se nic nezaznamenalo, takže spotřeba je **horní odhad** skutečné CESTA), krabička na začátku nahřátá, baterka plná. 72 probuzení, perioda 625.5 s, ~5 čtení CO2 v každém okně.
  - **Výdrž: −0.0076 V/h** (lineární fit od +2 h, rezidua 6.8 mV). První hodina je relaxace po nabíjení, ne vybíjení. **Cíl byl −0.02 V/h, takže 38 % rozpočtu.** Procenta nezávisle: 100 → 89.9 % za 12.4 h. Lineárně extrapolováno ~4.5 dne do 3.3 V (**řádový odhad**, křivka lineární není). Proti `2026-08-22-cesta-wake-cycles/` (−0.070 V/h, SCD41 tehdy běžel i ve spánku) je to ~9× lepší - odhad u té opravy byl 3-4×, ale mezitím se změnil i interval 5 → 10 min a měřilo se v jiné části křivky.
  - **CO2 se po `stop_periodic_measurement` spolehlivě rozjede - 72 ze 72 probuzení.** Tahle otázka byla otevřená od té opravy. Křivka dává smysl jako celek (1512 → min 1112 → 1744 ppm), žádné výpadky.
  - **BUG 1 (opraveno srpen 2026, viz bod 2i níž): teplota je v tom režimu o 3.55 °C pod realitou a nic to neoznačí.** BMP180 drží posledních 5 h `18.955 ± 0.043`, referenční teploměr hlásí 22.5. `REST_OFFSET_BMP180 = 2.46` se odečítá bezpodmínečně, ale byl změřený v DOMA; v uspávaném režimu je zařízení vzhůru 4.2 % času a čte se ~3 s po bootu, takže tam žádné self-heating teplo není. Vlnovka nesedne: SCD41 stav nemá → vezme se BMP180 → ten stav **má** → `stale=false`, a `suspect=false`, protože po probuzení není `cold_boot`. Zbytkových −1.09 °C proti syrovému čtení je otevřených - jeden odečet jedním teploměrem na novou konstantu nestačí, chce to stejný protokol jako `rest-offset` (tři odečty + kontroly).
  - **BUG 2 (opraveno srpen 2026, viz bod 2i níž): v uspávaném režimu nefunguje žádný filtr, co potřebuje historii.** Deep sleep je plný reboot a při `update_interval: 60s` stihne BMP180 / tlak / `battery_voltage` za probuzení jedno čtení. `median` filtr se `send_first_at: 1` vydá medián z jednovzorkového okna, tj. ten vzorek - a v datech to je vidět, ve 14:43 prošel výkyv −0.886 °C. Totéž (z konfigurace) platí pro medián u `battery_voltage` (`batt_v_hist1/2` jsou `restore_value: false`) a hlavně pro **detekci nabíjení**: `batt_v_slow_avg`, `charge_confirm_count`, `full_confirm_count` i `is_charging` jsou všechny `restore_value: false`, takže **`Charging` v uspávaném režimu nemohlo sepnout nikdy** - a s ním nejde ani vlnovka při nabíjení. V autě s USB nabíječkou by teplota byla až +3.7 °C vedle a neoznačená. Nenabíjelo se, takže z dat to potvrzené není.
  - **BUG 3 (opraveno srpen 2026, viz bod 2i níž): `Battery Level` chybí ve 21 ze 72 probuzení.** Závod, o kterém komentář v kódu tvrdí, že nastat nemá. Obě šablony mají 60s interval a ESPHome jim dává **nezávislý** náhodný offset v [0, 5 s); když padne `battery_level` dřív, uplatní se `if (!id(battery_voltage).has_state()) return {};` a druhá šance v tom ~26s okně nepřijde. Čisté řešení: publikovat procenta z lambdy `battery_voltage` místo vlastním tikem.
  - **Vedlejší číslo: chladnutí po přepnutí z nepřetržitého provozu do spánku trvá ~2.5-3 h** (τ ≈ 57 min z log-fitu, ale není to jedna exponenciála - z prvních bodů vychází 28-44 min). Zahřívání po studeném startu je proti tomu ~45 min. Vlnovka tohle taky nepokrývá.
  - **Ze SCD41 nepřišla za celých 12 h ani jedna teplota nebo vlhkost** - filtr `SCD41_SETTLE_MS = 3 min` proti 30s oknu, tedy chování podle návrhu. Nové je, že v HA to není zamrzlá hodnota, ale `unknown` po celou dobu; komentář v `sensors.yaml` o "last cached value" platí pro **displej**, ne pro Home Assistant.
- **ZÁZNAM S NABÍJEČKOU (srpen 2026, `data/2026-08-28-cesta-nabijeni-a-chladnuti/`) - 3.5 h, 22 probuzení, zavřel předposlední otevřený hardwarový test.** Baterka dojetá do vypnutí, v 19:28 zapojená nabíječka (zařízení se tím okamžitě nabootovalo - XIAO bere napájení z USB a nečeká na článek), hned přepnuto na CESTA, nabíječka odpojená ve 20:34. Referenční teploměr vedle.
  - **Probuzení tlačítkem: PROŠLO** - a byl to nález, ne plán. `wakeup_pin` na ESP32-C3 byla neověřená od začátku projektu. Boot ve 19:30:52 je od předchozího vzdálený 2.4 min proti intervalu 10 min, takže časovač to není, a publikovaná teplota u něj je 21.940 proti 18.880 o dvě minuty dřív - klidový offset se **neodečetl**. `esp_sleep_get_wakeup_cause()` tedy u GPIO probuzení vrací správnou hodnotu a větvení podle `cold_boot` na tlačítku sedí.
  - **`Charging` sepne s nabíječkou: PROŠLO.** Za **13 min** od zapojení, na prvním probuzení, kde to pravidlo vůbec spočítat mohlo. Krok +43.6 mV proti prahu +20, nejmenší krok za celé nabíjení 35 mV (1.75× nad prahem) i na dobíhajícím proudu. Práh +20 je tím ohraničený z obou stran - šum vybíjení ho nedosáhne 8×, skutečné nabíjení ho překročí 1.75×.
  - **`Charging` vypne po odpojení: PROŠLO**, 41 min, přesně na tři potvrzení. Vyžádalo si to čtyři probuzení, protože na jednom z nich vydal medián **bit-identickou** hodnotu → krok přesně 0 → větev "ani pokles" → vynulovaný čítač. **Zvažovaná oprava `step <= 0` byla sweepem zamítnuta:** na nabíjení z prázdné baterky vypne příznak o **56 minut dřív** (17:12 místo 18:08), uprostřed ploché CV fáze, kde nulové kroky vznikají i normálním během. To je ten samý typ chyby, proti kterému bylo `< 0` vybrané. **Zůstává `step < 0`.**
  - **Chyba proti referenci je reprodukovatelná: −0.94 °C** (sd 0.02) proti −0.90 (sd 0.18) z 23. 8. Dva nezávislé záznamy, jiný den, jiný stav baterky - o šum jednoho měření tedy nejde. Čí ta chyba je, pořád rozhodnuté není: sedí uvnitř součtu katalogových nejistot a je to nejspíš pokaždé ten samý teploměr na tom samém místě. **A pořád není zapsané, který to je.**
  - **Procenta baterky: PROŠLO podruhé** - 0 `unknown` za 22 probuzení. Tři chybějící řádky jsou bit-identické mediány, což tentokrát dokazuje `charging_duration`: ve 20:43:50 hlásí 70 minut, a to nastavuje ta samá lambda, co publikuje napětí.
  - **Nově změřené: okno chladnutí je ~1.9× delší, než chladnutí trvá.** Po odpojení je krabička do ±0.1 °C za **72 min** a do ±0.05 °C za **83**, zatímco `cooldown_min` je 150 započtených minut (~156 reálných). Není to chyba - na jistotu delší je správný směr - ale teď je z čeho ho zkrátit, kdyby vadil.
  - **Třetí záznam nabíjení, největší vrchol: +4.12 °C** nad ustálenou hodnotou (z dojeté baterky). Předchozí dva dávají +3.7 (z prázdné) a +2.35 (ze 64 %). Rozpětí 1.8 °C jen podle počátečního stavu baterky - argument pro `CHARGE_OFFSET_* = 0.0` potvrzený potřetí.
  - **Vlnovka na nahřáté krabičce: PROŠLO obojí.** Po celou dobu nabíjení **je**, a po vypršení okna **zmizí** - cap čítače padl na probuzení ve 22:59:17 a odečet s deseti vteřinami odstupu ji už neukázal. První odečet ve 23:08 ji ukazoval, ale to byl artefakt: čtený hned po zmáčknutí tlačítka, kdy je vlnovka tam z titulu `stale`, ne okna chladnutí. **Platný odečet je TEPLOTA 2 aspoň 10 s po zmáčknutí** - VLHKOST má vlnovku v tom režimu vždycky a CO2 i TEPLOTA prvních pár vteřin. Zbývá už jen studená krabička, kde se objevit nesmí.
  - **Menu: PROŠLO.** Uživatel proklikal všechny položky, navigace funguje. Že ASC toggle opravdu přepne registr v SCD41, tím ověřené není - to by chtělo běh s logováním.
  - **Odvozeno z identifikace teploměru: skutečné self-heating v DOMA je 3.40 °C, ne 2.46.** Reference je starší lihový teploměr s modrou kapalinou a je to **ten samý kus**, proti kterému se kalibrovaly klidové offsety. Konstanta 2.46 byla nastavená jako `raw − teploměr` v DOMA, takže tam zařízení sedí na teploměr z definice; v CESTA se neodečítá a self-heating tam není. Odečtením obou vztahů vypadne chyba teploměru i senzoru a zbude `h = 2.46 + 0.94 = 3.40`. **Konstanta 2.46 tedy nikdy nebyla čisté self-heating, ale rozdíl ohřevu 3.40 a chyby BMP180 −0.94.** Praktický důsledek: **DOMA čte o 0.94 °C výš než CESTA** ve stejné místnosti, a který z nich je správně, se tímhle teploměrem rozhodnout nedá.
- **OVĚŘOVACÍ ZÁZNAM PO OPRAVÁCH (srpen 2026, `data/2026-08-23-cesta-po-oprave/`) - 2.8 h, 16 probuzení, čtyři z pěti hardwarových testů PROŠLY.** Stejný režim a stejná krabička jako noční záznam, jen s firmwarem z větve `v2-deep-sleep-fixes`. Flashnuto v 17:40 lokálně, interval 10 min, HA připojení zapnuté, baterka odpojená od nabíječky (3.975 V / 87 %), tlačítko ani jednou.
  - **Offset: PROŠLO.** Flash boot je ještě `cold_boot`, takže je skok vidět přímo v datech: 19.746 °C v 17:40 → **22.421 °C při prvním probuzení ze spánku**, tedy +2.676 proti konstantě 2.46 (zbytek je skutečný drift raw za těch 10 min). Proti referenčnímu teploměru ve třech srovnatelných bodech **−0.90 °C, sd 0.18**, kde ta samá data bez opravy dávají −3.36. Spec předpovídal −1.09.
  - **Procenta baterky: PROŠLO.** `battery_level` má **0 `unknown` za 16 probuzení** proti 22 ze 64 řádků v nočním záznamu. Že řádků je jen 12, výpadek není - HA zapisuje jen změny a pětkrát se hodnota bit-identicky zopakovala. Hodnoty klesají hladce 87.05 → 86.38 %, žádný skok zpátky nahoru, takže `batt_v_hist1/2` opravdu přežily spánek.
  - **Medián přes probuzení: PROŠLO.** Šestnáct hodnot BMP180 tvoří monotónně klesající řadu bez výjimky, největší skok mezi probuzeními **−0.092 °C** proti −0.886 před opravou. Rozptyl kroku napětí spadl z 8.02 mV na **1.45** (spec předpovídal 2.16), rezidua lineárního fitu 0.91 mV proti 6.8.
  - **Falešné nabíjení: PROŠLO.** Největší kladný krok napětí je +2.45 mV proti prahu +20, tedy **8× rezerva**, nula sepnutí za 11 kroků. `Charging` zůstalo `off`, `Charging Duration` na 0.
  - **Neověřené zůstávaly dvě věci:** že `Charging` sepne, když se nabíječka **opravdu** připojí, a chování **vlnovky**. První zavřel záznam z 28. 8. výš, druhé je z poloviny hotové.
  - **Vedlejší nález: čítače běží o 4 % pomaleji, než ukazují.** Skutečná perioda je 10.41 min, ale `charge_minutes` i `disturb_minutes` přičítají `sleep_interval_minutes`, tedy rovných 10. Okno vlnovky nastavené na 150 min tak reálně trvá ~156 min. Jedním směrem a proti 150 min je to šum - neopravuje se, ale je dobré to vědět, než se z těch čítačů začne něco počítat.
  - **Teplota a vlhkost ze SCD41 jsou tam pořád trvale `unknown`** (0 platných hodnot za celý záznam). Oprava to neřešila a je to teď **největší zbylá díra v uspávaném režimu** - jediný zdroj teploty tam je BMP180.
- Poslední naměřené hodnoty se cachují do flash (`restore_value: true` globals) a displej je hned po zapnutí/probuzení ukazuje, místo loading baru/"--". `esp_sleep_get_wakeup_cause()` bylo kvůli tomu odstraněné (nebylo pro co ho potřebovat), ale **vrátilo se zpátky** s indikátorem zahřívání - teď v `on_boot` prioritě 600 plní globál `cold_boot`, aby šlo odlišit studený start od probuzení. `esp_sleep.h` se do buildu dostává přes header deep_sleep komponenty, žádný extra `includes:` netřeba (ověřeno kompilací).
- `preferences: flash_write_interval: 1s` přidáno, aby se cachovaná hodnota nezralila, pokud deep sleep vypne napájení dřív, než výchozí 1min interval stihne zapsat do flash.
- Mrtvý kód z bodu "Známé drobnosti k úklidu" (níže v tomhle souboru) byl smazaný (button_press_start_ms, long_hold_5s_fired, last_release_held_ms).

**Vyřešeno od minula:**
- Projekt přesunutý z `C:\Users\lagys\Documents\Coding Projects\Air Quality Monitor` (mezera v cestě) na `C:\Users\lagys\air-quality-monitor` (git historie zachovaná, viz git log) - PlatformIO/ESP-IDF toolchain mezery v cestě nesnáší.
- `esphome compile` z nové cesty **prošel úspěšně** (ne jen `esphome config` validace) - RAM 11.4%, Flash 55.5%. Reálný hardwarový test (flash + chování) pořád čeká na uživatele.
- DOMA/CESTA presety a CO2 alarm práh (3000/2700 ppm) uživatel potvrdil - CESTA interval finálně 10 min (ne navrhovaných 5).

**Otevřené položky, na kterých čekáme (potřeba reálný hardware/uživatel):**
1. Reálný hardwarový test celého v2 firmwaru (~~menu navigace všech 6 položek~~ **HOTOVO (srpen 2026)** - uživatel proklikal všechny položky, navigace funguje; ~~deep sleep probuzení **tlačítkem**~~ **HOTOVO, viz drobnost 3 níž** - časovačem je ověřené 72 cykly v `data/2026-08-23-cesta-baseline/` a CO2 se v nich pokaždé rozjelo, CO2 alarm, ASC toggle - viz jeho vlastní pozn. výš o testu s logováním). Nově k tomu: `~` indikátor musí být po studeném startu, a po probuzení z deep sleepu **jen když krabička chladne** - od srpna 2026 to už není prosté "po probuzení nikdy", viz bod 8 níž; a v CESTA ověřit, že alarm stihne sepnout ještě ve 30s okně (dýchnout na senzor).
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

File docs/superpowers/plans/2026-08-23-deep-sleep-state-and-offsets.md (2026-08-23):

# Stav a offsety v uspávaném režimu - implementační plán

> **For agentic workers:** REQUIRED SUB-SKILL: Use superpowers:subagent-driven-development (recommended) or superpowers:executing-plans to implement this plan task-by-task. Steps use checkbox (`- [ ]`) syntax for tracking.

**Goal:** Opravit čtyři chyby, které vzniknou tím, že deep sleep je plný reboot, zatímco firmware je psaný pro nepřetržitý běh - teplota o 3.55 °C mimo, nefunkční mediány, nefunkční detekce nabíjení a chybějící procenta baterky.

**Architecture:** Stav se rozdělí do tří tříd podle toho, co má přežít (nic / spánek / spánek i vypnutí); třída „jen spánek" se realizuje flash-backed globály, které se při studeném bootu vynulují. Klidový offset teploty se přestane odečítat v probuzeních ze spánku, klíčem je `cold_boot`. Detekce nabíjení dostane ve spánku vlastní, jednodušší větev nad krokem mezi probuzeními. Mediány BMP180 se opraví zrychlením pollingu místo perzistence.

**Tech Stack:** ESPHome 2026.4.0, ESP32-C3 (XIAO), Arduino framework, čisté YAML + C++ lambdy. Žádný testovací framework - ověřuje se `esphome config`, `esphome compile` a simulacemi nad CSV v `data/`.

**Spec:** [`docs/superpowers/specs/2026-08-23-deep-sleep-state-and-offsets-design.md`](../specs/2026-08-23-deep-sleep-state-and-offsets-design.md)

## Global Constraints

- **Nepushovat.** Commituje se jen lokálně, `git push` až na výslovné vyžádání (CLAUDE.md).
- **Bez attribution v commitech.** Žádné `Co-Authored-By`, žádný `Claude-Session:` trailer, žádná zmínka o asistentovi (CLAUDE.md).
- **Dokumentace i komentáře nesou původ čísla.** Když se něco odhaduje nebo extrapoluje, musí to být napsané u toho (CLAUDE.md).
- **`esphome` není v PATH** - volá se `python -m esphome ...` z `C:\Users\lagys\air-quality-monitor`.
- Komentáře v YAML/lambdách jsou **anglicky** (stávající konvence souborů), dokumentace v `.md` **česky**.
- `secrets.yaml` se nikdy necommituje.
- **DOMA větev detekce nabíjení se nemění** - je ověřená proti dvěma nabíjecím záznamům.
- Konstanty: `CHARGE_STEP_V = 0.020`, release `< 0.0`, `RELEASE_CONFIRM = 3`, `COOLDOWN_MIN = 150`, `bmp085 update_interval = 5s`.

## File Structure

| soubor | odpovědnost | mění se v úkolu |
|---|---|---|
| `air-quality-monitor.yaml` | substituce, `on_boot`, vynulování třídy B | 1 |
| `packages/globals.yaml` | deklarace stavu a jeho životnost | 1 |
| `packages/sensors.yaml` | offset teploty, filtry, detekce nabíjení, procenta | 2, 3, 4, 5, 6 |
| `packages/display.yaml` | podmínka vlnovky | 6 |
| `packages/menu.yaml` | nastavení rozladění při vstupu do spánku | 6 |
| `data/threshold-sweep.py` | reprodukovatelný sweep prahů (nový) | 4 |
| `README.md`, `HANDOFF.md`, `data/README.md` | dokumentace | 7 |

---
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

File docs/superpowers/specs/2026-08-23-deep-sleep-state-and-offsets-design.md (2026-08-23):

# Návrh: stav a offsety v uspávaném režimu

**Datum:** 23. 8. 2026
**Podklad:** [`data/2026-08-23-cesta-baseline/`](../../../data/README.md) - 12.4 h přes noc, 72 probuzení, s referenčním teploměrem. Prahy nabíjení navíc prohnány oběma nabíjecími záznamy.
**Dotčené soubory:** `packages/globals.yaml`, `packages/sensors.yaml`, `packages/display.yaml`, `packages/menu.yaml`, `air-quality-monitor.yaml`, `README.md`, `HANDOFF.md`
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

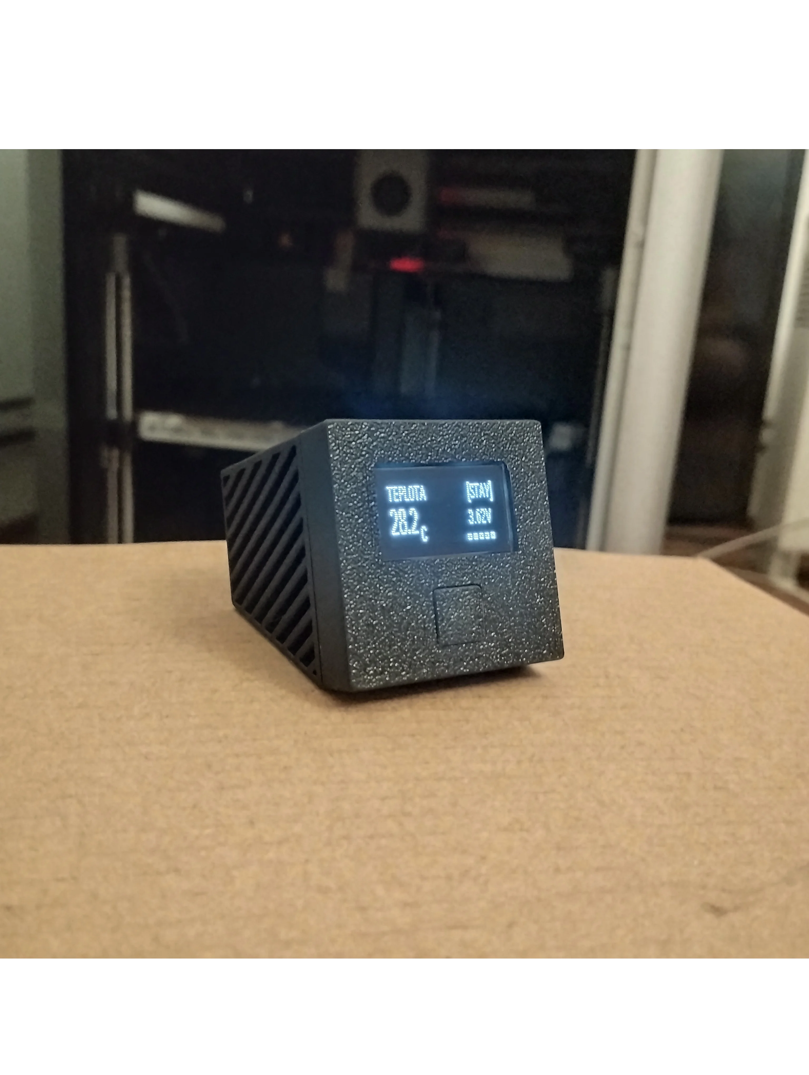
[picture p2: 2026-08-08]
images/v1.webp

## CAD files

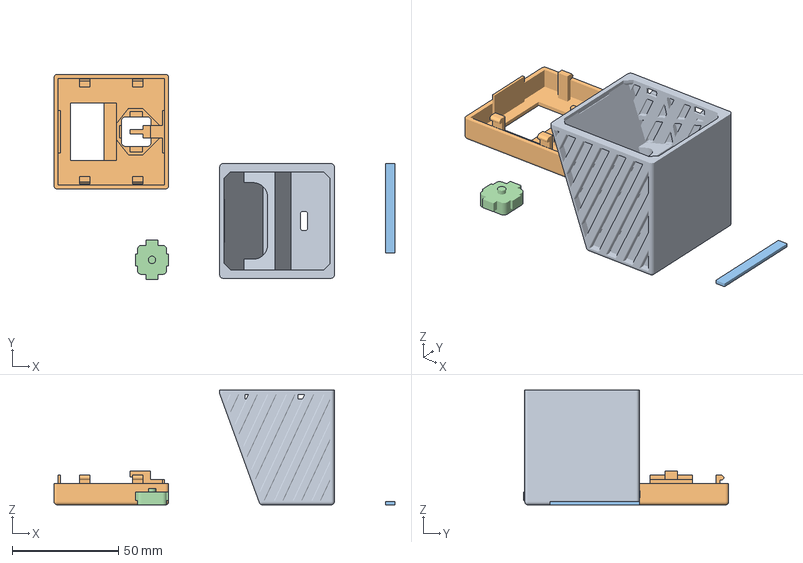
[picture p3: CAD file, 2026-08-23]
enclosure/case v2.3mf
160.5 x 96.7 x 54.0 mm
Assembly x 2

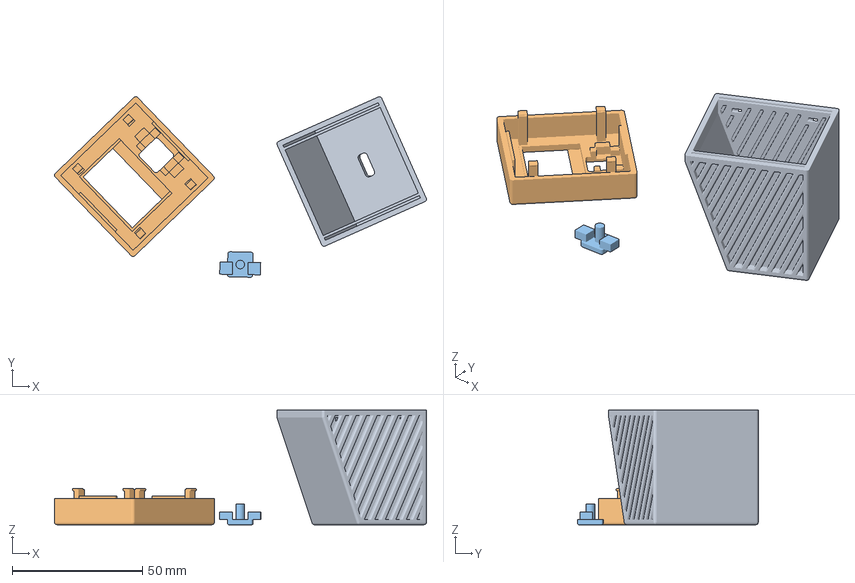
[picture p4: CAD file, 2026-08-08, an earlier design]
enclosure/case.3mf
142.9 x 69.4 x 44.0 mm
case
front
button

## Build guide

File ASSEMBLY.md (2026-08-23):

# Sestavení (kryt v2)

<p align="center">
  
</p>

Postup platí pro **kryt v2** ([`enclosure/case v2.3mf`](enclosure/README.md)). Zapojení komponent se proti v1 nemění, to je pořád v [WIRING.md](WIRING.md) - jiné je jen fyzické uspořádání a pořadí kroků.

Lepí se tavnou pistolí. Text níž používá "natavit" i "nalepit" ve stejném významu, kromě kroku 4, kde jde opravdu o **zatavení otvoru** (spára musí být zadělaná, ne jen přichycená).

## Co se změnilo proti v1

| | v1 | v2 |
|---|---|---|
| Materiál | Bambu PLA Basic | **Aurapol PETG** - tvrdší a odolnější |
| Velikost | menší | o něco větší |
| Teplotní senzory | nalepené na strop krytu | **vlastní kompartment dole**, zatavený zvlášť |
| Tlačítko | nalepené na stranu s baterií, do předního dílu jen zapadlo | **natavené přímo na přední kryt**, s pružinkou pod ním |
| Ikonka na tlačítku | žádná | **symbol napájení** ⏻ |
| Displej | na přední stěnu těla | **na přední kryt** (spolu s tlačítkem) |
| Anténa | dole, pod celou sestavou | **nahoře na krabičce**, co nejvíc vepředu |
| TP4056 | pod baterkou | **podél baterky**, na protilehlé straně než ESP32 |

Ten kompartment dole je hlavní změna, která má vliv na měření: senzory jsou teď oddělené vlastní přepážkou od baterky, TP4056 modulu i ESP32, tedy od všeho, co v krabičce topí.

## 1. Sestava baterky, nabíjení a desky

1. Natavit **baterku a TP4056 modul na sebe**. Modul jde **podél baterky**, takže na ní sedí a nepřesahuje její obrys.
2. Natavit **ESP32-C3 (XIAO)** na **druhou stranu baterky**, tedy na protilehlou plochu než TP4056 - **ne přímo na modul**. Baterka zůstává mezi nimi. Deska musí sedět tak, aby **USB-C vyčnívalo** ven přes okraj baterky.

Pořadí vrstev je tedy:

```
  ┌─────────────────────────────────────┐
  │              ESP32-C3               │  ← USB-C vyčnívá přes okraj
  ├─────────────────────────────────────┤
  │               baterka               │  ← uprostřed, drží obě desky
  ├─────────────────────────────────────┤
  │        TP4056 (podél baterky)       │
  └─────────────────────────────────────┘
```

Vznikne z toho jeden kompaktní blok, dál v textu **stack**. Ten se do krabičky vkládá až na konci (krok 10), protože by jinak překážel u všeho ostatního.

## 2. Teplotní senzory do spodního kompartmentu

3. **Jako úplně první věc** do krabičky přijdou **oba teplotní senzory** - SCD41 i BMP180. Natavit je na **strop spodního kompartmentu**.

Proč jako první: až se otvor zataví (krok 4), není se tam kudy dostat.

## 3. Zatavit spodek

4. Nasadit **novou záklopku na spodek krabičky** - zakrývá kompartment i spodní stěnu krabičky. **Zatavit.** Výsledkem musí být **celý otvor zadělaný**, ne jen přichycená destička.

## 4. Tlačítko do předního krytu

5. Vložit **tlačítko do předního krytu** a přidat pod něj **malou pružinku** - vrací tlačítko zpátky a zlepšuje odezvu.
6. **Natavit tlačítko na přední kryt.** (Ve v1 se lepilo naopak na stranu s baterií a do předního dílu jen zapadlo.)

**Pružinka:** tlačná, drát **0.016" (0.4 mm)**, vnější průměr **0.2" (5.10 mm)**, délka **0.39" (~10 mm)** - běžný rozměr z krabičky s asortimentem pružinek. **Přestřihnout zhruba v půlce**, celá je moc dlouhá; instalovaná je pak asi 5 mm.

## 5. Displej

7. Natavit **displej na přední kryt**.

> Na předním krytu tak sedí **displej i tlačítko**, a prochází jím i vypínač (krok 8). Displej je kabelem svázaný s deskou, která je vzadu v krabičce - přední díl proto po sestavení **nejde volně odložit**, visí na kabelech. Při každém rozebírání s tím počítej a netahej za ně.

## 6. Vypínač

8. Natavit **hlavní vypínač na baterku, vlevo dole** - tedy na stack, ne do krabičky. Pozice musí sedět na **díru v předním krytu**, kterou vypínač prochází ven.

## 7. Stack do krabičky

9. Vzít celý **stack (ESP32 + baterka + TP4056 + vypínač)** a nalepit ho **dozadu do krabičky**. **USB-C musí trefit díru vzadu.**

Tohle je jediné místo, kde se pozice po zaschnutí neopraví, a musí vyjít **dvě věci naráz** - USB-C vzadu a vypínač do díry v předním krytu. Stojí za to složit to nejdřív nasucho a přiložit přední kryt, jestli obojí sedí.

## 8. Anténa

10. Nalepit **anténu nahoru na krabičku**, ideálně **co nejvíc dopředu**.

Anténa je externí flat/nálepková WiFi anténa na u.FL kabelu, ne vestavěná PCB anténa na desce. Ve v1 ležela dole **pod** baterkou a TP4056 modulem, takže signál procházel skrz celou sestavu; nová pozice nahoře a vepředu tenhle problém obchází.

I tak se vyplatí to před nalepením natrvalo zkontrolovat - anténa je na kabelu, takže jde posunout bez rozebírání zbytku:

- Poskládat zařízení volně (bez lepení) a podívat se do logu na `[wifi:xxxx] Signal strength: -XX dB`.
- Orientačně: -50 až -60 dB je dobré, -60 až -70 dB v pořádku pro běžný provoz, -70 až -80 dB slabé, ale funkční, pod -80 dB už hrozí časté výpadky.

## 9. Hotovo

Nasadit přední kryt. Tím je sestavení kompletní.

### Riziko: prasknutí při secvaknutí

Pořád platí z v1 - při secvakávání předního krytu **hrozí prasknutí**. Díly musí jít spojit lehce, bez síly. Když to nejde, něco uvnitř překáží; rozebrat a zkontrolovat, ne to domáčknout. PETG je proti PLA houževnatější a spíš se ohne, než praskne, ale spoléhat se na to nedá.

---

## Poznámky k tisku

Detaily jsou v [`enclosure/README.md`](enclosure/README.md). Ve zkratce: tištěno na **Bambu Lab X1C s AMS** (stejná tiskárna jako v1), materiál **Aurapol PETG**, celý model na **0.2mm** vrstvě, podpory jen u tlačítka a u předního krytu.

**Bez AMS to jde taky.** Jediný díl, kde se barvy míchají, je **přední tlačítko** se symbolem napájení - kdo nemá AMS, vytiskne ho jednobarevně. Ikonka je pak reliéf místo barevného kontrastu, funkčně se nemění nic.

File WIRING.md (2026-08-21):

# Zapojení

## GPIO pinout (Seeed XIAO ESP32-C3)

| Pin | Funkce | Poznámka |
|---|---|---|
| GPIO6 | I2C SDA | Sdílená sběrnice: SCD41, BMP180, SSD1306 |
| GPIO7 | I2C SCL | Sdílená sběrnice: SCD41, BMP180, SSD1306 |
| GPIO4 | Snímání napětí baterky | Odbočka na děliči 220kΩ/100kΩ |
| GPIO3 | Vstup tlačítka OLED | Interní pull-up zapnutý, invertovaná logika |

## v2: hlavní vypínač baterie

Ve v2 přibyl **mechanický vypínač mezi baterií a TP4056 modulem** (v sérii na kladné větvi, mezi B+ baterky a B+ vstupem TP4056). Je to čistě hardwarová záležitost - úplně odpojí napájení celého zařízení (stejný efekt jako vytažení baterky), firmware o něm nijak neví a nepotřebuje s ním nic dělat. Slouží k tomu, aby zařízení mohlo ležet delší dobu úplně bez odběru (žádný "vampire drain" ani při zapnutém hlubokém spánku), např. při skladování.

I2C sběrnice běží na 100kHz. Interní pull-upy ESP jsou vypnuté (`sda_pullup_enabled: false`, `scl_pullup_enabled: false`), takže sběrnice běží čistě na externích 4.7kΩ pull-up rezistorech na SDA i SCL.

## Dělič napětí baterky

```
B+ (baterka, přímo) ──[220kΩ]──┬──[100kΩ]── BAT- (XIAO) / GND
                                │
                              GPIO4
```

**v2 změna:** horní noha děliče (220kΩ) je teď zapojená **přímo na kladnou svorku baterky (B+)**, ne na BAT+ pin XIAO desky/OUT+ TP4056 jako v v1 - obchází tak jakýkoli (byť malý) úbytek na trase přes modul a jeho konektory. Dolní noha (100kΩ) a referenční GND pro GPIO4 zůstávají beze změny na **XIAO GND** (= OUT- TP4056), takže záporná reference děliče je pořád za ochranným obvodem TP4056 (DW01A + FS8205A), stejně jako v v1.

Za normálního provozu (ochranný FET sepnutý) je XIAO GND prakticky totožný s B- (rozdíl jen jednotky mV), takže tahle změna nemění běžné měření ani detekci nabíjení - jen dělá horní nohu o chlup přesnější (méně sériové impedance mezi děličem a skutečnou svorkou článku).

**Co se NEmění:** při zásahu ochrany (hluboké vybití, FET rozpojí OUT-/B-) ztrácí celé XIAO napájení úplně (jde přes stejnou OUT+/OUT- cestu jako napájení ESP32) a zařízení spadne - to platilo v v1 a platí i teď, protože GND noha děliče pořád sedí za ochranným obvodem. Firmware v tu chvíli prostě neběží a nic neměří, žádná "plovoucí" chybná hodnota se do HA nedostane.

**Skok napětí při zapojení nabíječky** (viz [README Known Issues](README.md#known-issues)) se po tomhle přepojení v praxi výrazně zmenšil/zmizel. To ukazuje, že v1 zapojení (dělič na BAT+ pinu XIAO, tedy až za trasou/kontakty TP4056 modulu) neslo víc sériového odporu, než jen ten vnitřní odpor samotného článku - stačilo pár desítek/stovek mΩ navíc z konektorů/drážky modulu při průchodu nabíjecího proudu, aby se to na skoku znatelně projevilo. Přímé zapojení na svorku článku tuhle přidanou impedanci obchází.

- Poměr děliče: (220k + 100k) / 100k = 3.2
- Firmware udělá 30 rychlých čtení `analogReadMilliVolts()` na GPIO4, zprůměruje je a pak vynásobí 3.2, aby dopočítal napětí baterky
- Aktuální přesnost kalibrace viz [README.md, Known Issues](README.md#known-issues)

## Kompletní schéma zapojení

Každý jednotlivý vodič, vedený přes sdílené bus/rail uzly, aby se čáry nezamotávaly:

```mermaid
graph LR
  subgraph XIAO["Seeed XIAO ESP32-C3"]
    P3V3["3V3"]
    PGND["GND"]
    G3["GPIO3"]
    G4["GPIO4"]
    G6["GPIO6 (SDA)"]
    G7["GPIO7 (SCL)"]
    BATP["BAT+"]
    BATN["BAT-"]
  end

  G6 --> SDA_BUS(("SDA sběrnice"))
  G7 --> SCL_BUS(("SCL sběrnice"))
  P3V3 --> RAIL_3V3(("3V3 rozvod"))
  PGND --> RAIL_GND(("GND rozvod"))

  RAIL_3V3 --> RSDA["4.7kΩ"] --> SDA_BUS
  RAIL_3V3 --> RSCL["4.7kΩ"] --> SCL_BUS

  subgraph SCD41["SCD41 (adresa 0x62)"]
    S_SDA["SDA"]
    S_SCL["SCL"]
    S_VCC["VCC"]
    S_GND["GND"]
  end
  SDA_BUS --> S_SDA
  SCL_BUS --> S_SCL
  RAIL_3V3 --> S_VCC
  RAIL_GND --> S_GND

  subgraph BMP180["BMP180 (adresa 0x77)"]
    B_SDA["SDA"]
    B_SCL["SCL"]
    B_VCC["VCC"]
    B_GND["GND"]
  end
  SDA_BUS --> B_SDA
  SCL_BUS --> B_SCL
  RAIL_3V3 --> B_VCC
  RAIL_GND --> B_GND

  subgraph OLED["SSD1306 OLED (adresa 0x3C)"]
    O_SDA["SDA"]
    O_SCL["SCL"]
    O_VCC["VCC"]
    O_GND["GND"]
  end
  SDA_BUS --> O_SDA
  SCL_BUS --> O_SCL
  RAIL_3V3 --> O_VCC
  RAIL_GND --> O_GND

  subgraph BTN["Tlačítko"]
    BTN1["Vývod 1"]
    BTN2["Vývod 2"]
  end
  G3 --> BTN1
  BTN2 --> RAIL_GND

  subgraph DIVIDER["Dělič napětí baterky"]
    R1["220kΩ"]
    TAP(("Odbočka"))
    R2["100kΩ"]
  end
  R1 --> TAP --> R2
  TAP --> G4

  subgraph TP4056["TP4056 nabíjecí/ochranný modul"]
    T_OUTP["OUT+"]
    T_OUTN["OUT-"]
    T_BP["B+"]
    T_BN["B-"]
  end
  BATP --> T_OUTP
  BATN --> T_OUTN

  subgraph BATTERY["LiPo baterie ~500mAh"]
    BP["+"]
    BN["-"]
  end
  subgraph PWRSW["Hlavní vypínač (v2)"]
    SW1["Vývod 1"]
    SW2["Vývod 2"]
  end
  BP --> SW1
  SW2 --> T_BP
  T_BN --> BN
  BP --> R1
  BATN --> R2
  BATN --> RAIL_GND

  classDef bus fill:#2b2b2b,stroke:#888,color:#fff;
  class SDA_BUS,SCL_BUS,RAIL_3V3,RAIL_GND,TAP bus;
```

Poznámky ke schématu:
- `SDA sběrnice`, `SCL sběrnice`, `3V3 rozvod` a `GND rozvod` nejsou fyzické součástky, reprezentují sdílené vodiče, aby schéma nemuselo mít samostatnou křížící se čáru z XIAO ke každýmu jednotlivýmu pinu zařízení.
- SDA a SCL vedou z XIAO každá jedním vodičem, který se rozvětví ke všem třem I2C zařízením, plus pull-up rezistor na 3V3 na každé lince. Je tam jeden 4.7kΩ na SDA a jeden na SCL celkem, ne jeden na senzor.
- Všechny tři I2C zařízení sdílí stejný 3V3 a GND rozvod z XIAO.
- Tlačítko má jeden vývod na GPIO3 a druhý na GND. Interní pull-up na GPIO3 je zapnutý ve firmware a signál je invertovaný, takže pin čte vysokou hodnotu v klidu a nízkou při zmáčknutí.
- Kladný pól baterky jde přes hlavní vypínač (v2) do B+ TP4056 modulu, záporný pól jde do B- přímo. TP4056 OUT+/OUT- jde na BAT+/BAT- na XIAO, takže nabíjení řeší TP4056 modul, ne přímo XIAO deska.
- **Dělič napětí (220kΩ/100kΩ): horní konec (220kΩ) je od v2 zapojený přímo na B+ baterky**, ne na BAT+ pin XIAO desky jako v v1. Spodní konec (100kΩ) zůstává na BAT- (stejný uzel jako GND rozvod celého XIAO) - viz vysvětlení a důsledky výš v sekci "Dělič napětí baterky".
- Odbočka děliče mezi rezistory 220kΩ a 100kΩ je jediné místo připojené na GPIO4.

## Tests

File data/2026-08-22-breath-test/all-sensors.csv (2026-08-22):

entity_id | state | last_changed
sensor.air_quality_monitor_co2 | unknown | 2026-08-22T21:20:00.000Z
sensor.air_quality_monitor_co2 | 1195.0 | 2026-08-22T21:20:00.891Z
sensor.air_quality_monitor_co2 | 1200.0 | 2026-08-22T21:20:05.892Z
sensor.air_quality_monitor_co2 | 1195.0 | 2026-08-22T21:20:10.897Z
sensor.air_quality_monitor_co2 | 1190.0 | 2026-08-22T21:20:15.897Z
sensor.air_quality_monitor_co2 | 1199.0 | 2026-08-22T21:20:20.896Z
sensor.air_quality_monitor_co2 | 1203.0 | 2026-08-22T21:20:25.897Z
sensor.air_quality_monitor_co2 | 1201.0 | 2026-08-22T21:20:30.897Z
sensor.air_quality_monitor_co2 | 1200.0 | 2026-08-22T21:20:35.902Z
sensor.air_quality_monitor_co2 | 1201.0 | 2026-08-22T21:20:45.901Z
sensor.air_quality_monitor_co2 | 1202.0 | 2026-08-22T21:20:50.909Z
sensor.air_quality_monitor_co2 | 1203.0 | 2026-08-22T21:20:55.908Z
sensor.air_quality_monitor_co2 | 1202.0 | 2026-08-22T21:21:00.902Z
sensor.air_quality_monitor_co2 | 1201.0 | 2026-08-22T21:21:05.915Z
sensor.air_quality_monitor_co2 | 1202.0 | 2026-08-22T21:21:15.909Z
sensor.air_quality_monitor_co2 | 1203.0 | 2026-08-22T21:21:35.924Z
sensor.air_quality_monitor_co2 | 1202.0 | 2026-08-22T21:21:40.930Z
sensor.air_quality_monitor_co2 | 1201.0 | 2026-08-22T21:22:00.924Z
sensor.air_quality_monitor_co2 | 1202.0 | 2026-08-22T21:22:25.938Z
sensor.air_quality_monitor_co2 | 1203.0 | 2026-08-22T21:22:55.947Z
sensor.air_quality_monitor_co2 | 1204.0 | 2026-08-22T21:23:00.942Z
sensor.air_quality_monitor_co2 | 1205.0 | 2026-08-22T21:23:05.939Z
sensor.air_quality_monitor_co2 | 1204.0 | 2026-08-22T21:23:10.945Z
sensor.air_quality_monitor_co2 | 1205.0 | 2026-08-22T21:23:25.952Z
sensor.air_quality_monitor_co2 | 1206.0 | 2026-08-22T21:23:30.954Z
sensor.air_quality_monitor_co2 | 1207.0 | 2026-08-22T21:23:45.958Z
sensor.air_quality_monitor_co2 | 1206.0 | 2026-08-22T21:24:05.980Z
sensor.air_quality_monitor_co2 | 1207.0 | 2026-08-22T21:24:10.987Z
sensor.air_quality_monitor_co2 | 1208.0 | 2026-08-22T21:24:25.981Z
sensor.air_quality_monitor_co2 | 1210.0 | 2026-08-22T21:24:30.983Z
sensor.air_quality_monitor_co2 | 1211.0 | 2026-08-22T21:24:35.985Z
sensor.air_quality_monitor_co2 | 1212.0 | 2026-08-22T21:24:45.994Z
sensor.air_quality_monitor_co2 | 1213.0 | 2026-08-22T21:25:01.113Z
sensor.air_quality_monitor_co2 | 1212.0 | 2026-08-22T21:25:06.015Z
sensor.air_quality_monitor_co2 | 1213.0 | 2026-08-22T21:25:11.017Z
sensor.air_quality_monitor_co2 | 1214.0 | 2026-08-22T21:25:36.052Z
sensor.air_quality_monitor_co2 | 1215.0 | 2026-08-22T21:25:41.061Z
sensor.air_quality_monitor_co2 | 1214.0 | 2026-08-22T21:26:06.080Z
sensor.air_quality_monitor_co2 | 1215.0 | 2026-08-22T21:26:16.092Z
sensor.air_quality_monitor_co2 | 1216.0 | 2026-08-22T21:26:41.090Z
sensor.air_quality_monitor_co2 | 1217.0 | 2026-08-22T21:26:51.105Z
sensor.air_quality_monitor_co2 | 1218.0 | 2026-08-22T21:26:56.109Z
sensor.air_quality_monitor_co2 | 1217.0 | 2026-08-22T21:27:06.104Z
sensor.air_quality_monitor_co2 | 1218.0 | 2026-08-22T21:27:16.120Z
sensor.air_quality_monitor_co2 | 1219.0 | 2026-08-22T21:27:31.127Z
sensor.air_quality_monitor_co2 | 1220.0 | 2026-08-22T21:27:41.128Z
sensor.air_quality_monitor_co2 | 1219.0 | 2026-08-22T21:27:46.129Z
sensor.air_quality_monitor_co2 | 1220.0 | 2026-08-22T21:27:51.132Z
sensor.air_quality_monitor_co2 | 1221.0 | 2026-08-22T21:28:06.141Z
sensor.air_quality_monitor_co2 | 1222.0 | 2026-08-22T21:28:11.144Z
sensor.air_quality_monitor_co2 | 1223.0 | 2026-08-22T21:28:16.144Z
sensor.air_quality_monitor_co2 | 1224.0 | 2026-08-22T21:28:26.156Z
sensor.air_quality_monitor_co2 | 1223.0 | 2026-08-22T21:28:31.162Z
sensor.air_quality_monitor_co2 | 1225.0 | 2026-08-22T21:28:36.172Z
sensor.air_quality_monitor_co2 | 1227.0 | 2026-08-22T21:28:41.173Z
sensor.air_quality_monitor_co2 | 1229.0 | 2026-08-22T21:28:46.179Z
sensor.air_quality_monitor_co2 | 1228.0 | 2026-08-22T21:28:56.184Z
sensor.air_quality_monitor_co2 | 1227.0 | 2026-08-22T21:29:06.186Z
sensor.air_quality_monitor_co2 | 1226.0 | 2026-08-22T21:29:16.202Z
sensor.air_quality_monitor_co2 | 1227.0 | 2026-08-22T21:29:21.203Z
sensor.air_quality_monitor_co2 | 1226.0 | 2026-08-22T21:29:31.220Z
sensor.air_quality_monitor_co2 | 1227.0 | 2026-08-22T21:29:41.223Z
sensor.air_quality_monitor_co2 | 1226.0 | 2026-08-22T21:29:46.222Z
sensor.air_quality_monitor_co2 | 1227.0 | 2026-08-22T21:29:56.225Z
sensor.air_quality_monitor_co2 | 1228.0 | 2026-08-22T21:30:06.236Z
sensor.air_quality_monitor_co2 | 1229.0 | 2026-08-22T21:30:31.246Z
sensor.air_quality_monitor_co2 | 1230.0 | 2026-08-22T21:30:36.248Z
sensor.air_quality_monitor_co2 | 1231.0 | 2026-08-22T21:31:01.271Z
sensor.air_quality_monitor_co2 | 1230.0 | 2026-08-22T21:31:11.274Z
sensor.air_quality_monitor_co2 | 1231.0 | 2026-08-22T21:31:41.297Z
sensor.air_quality_monitor_co2 | 1232.0 | 2026-08-22T21:31:56.295Z
sensor.air_quality_monitor_co2 | 1233.0 | 2026-08-22T21:32:01.301Z
sensor.air_quality_monitor_co2 | 1234.0 | 2026-08-22T21:32:16.309Z
sensor.air_quality_monitor_co2 | 1235.0 | 2026-08-22T21:32:46.316Z
sensor.air_quality_monitor_co2 | 1236.0 | 2026-08-22T21:33:01.321Z
sensor.air_quality_monitor_co2 | 1235.0 | 2026-08-22T21:33:06.326Z
sensor.air_quality_monitor_co2 | 1236.0 | 2026-08-22T21:33:11.326Z
sensor.air_quality_monitor_co2 | 1235.0 | 2026-08-22T21:33:21.328Z
sensor.air_quality_monitor_co2 | 1236.0 | 2026-08-22T21:33:31.340Z
sensor.air_quality_monitor_co2 | 1235.0 | 2026-08-22T21:33:51.339Z
sensor.air_quality_monitor_co2 | 1236.0 | 2026-08-22T21:33:56.342Z
sensor.air_quality_monitor_co2 | 1237.0 | 2026-08-22T21:34:16.357Z
sensor.air_quality_monitor_co2 | 1238.0 | 2026-08-22T21:34:26.368Z
sensor.air_quality_monitor_co2 | 1239.0 | 2026-08-22T21:34:31.370Z
sensor.air_quality_monitor_co2 | 1240.0 | 2026-08-22T21:34:41.374Z
sensor.air_quality_monitor_co2 | 1241.0 | 2026-08-22T21:34:46.375Z
sensor.air_quality_monitor_co2 | 1240.0 | 2026-08-22T21:34:56.381Z
sensor.air_quality_monitor_co2 | 1239.0 | 2026-08-22T21:35:01.536Z
sensor.air_quality_monitor_co2 | 1240.0 | 2026-08-22T21:35:06.401Z
sensor.air_quality_monitor_co2 | 1239.0 | 2026-08-22T21:35:16.402Z
sensor.air_quality_monitor_co2 | 1241.0 | 2026-08-22T21:35:21.407Z
sensor.air_quality_monitor_co2 | 1242.0 | 2026-08-22T21:35:31.408Z
sensor.air_quality_monitor_co2 | 1243.0 | 2026-08-22T21:35:41.416Z
sensor.air_quality_monitor_co2 | 1244.0 | 2026-08-22T21:36:06.435Z
sensor.air_quality_monitor_co2 | 1247.0 | 2026-08-22T21:36:31.454Z
sensor.air_quality_monitor_co2 | 1248.0 | 2026-08-22T21:36:36.454Z
sensor.air_quality_monitor_co2 | 1247.0 | 2026-08-22T21:36:41.454Z
sensor.air_quality_monitor_co2 | 1248.0 | 2026-08-22T21:37:01.463Z
sensor.air_quality_monitor_co2 | 1249.0 | 2026-08-22T21:37:06.464Z
sensor.air_quality_monitor_co2 | 1251.0 | 2026-08-22T21:37:16.471Z
sensor.air_quality_monitor_co2 | 1252.0 | 2026-08-22T21:37:36.475Z
sensor.air_quality_monitor_co2 | 1254.0 | 2026-08-22T21:37:51.493Z
sensor.air_quality_monitor_co2 | 1253.0 | 2026-08-22T21:37:56.492Z
sensor.air_quality_monitor_co2 | 1252.0 | 2026-08-22T21:38:11.502Z
sensor.air_quality_monitor_co2 | 1253.0 | 2026-08-22T21:38:16.503Z
sensor.air_quality_monitor_co2 | 1252.0 | 2026-08-22T21:38:31.511Z
sensor.air_quality_monitor_co2 | 1253.0 | 2026-08-22T21:38:36.516Z
sensor.air_quality_monitor_co2 | 1254.0 | 2026-08-22T21:38:41.526Z
sensor.air_quality_monitor_co2 | 1256.0 | 2026-08-22T21:38:46.526Z
sensor.air_quality_monitor_co2 | 1257.0 | 2026-08-22T21:39:01.534Z
sensor.air_quality_monitor_co2 | 1256.0 | 2026-08-22T21:39:06.535Z
sensor.air_quality_monitor_co2 | 1255.0 | 2026-08-22T21:39:21.537Z
sensor.air_quality_monitor_co2 | 1254.0 | 2026-08-22T21:39:31.552Z
sensor.air_quality_monitor_co2 | 1351.0 | 2026-08-22T21:39:36.555Z
sensor.air_quality_monitor_co2 | 1517.0 | 2026-08-22T21:39:41.556Z
sensor.air_quality_monitor_co2 | 1725.0 | 2026-08-22T21:39:46.559Z
sensor.air_quality_monitor_co2 | 2445.0 | 2026-08-22T21:39:51.559Z
sensor.air_quality_monitor_co2 | 2874.0 | 2026-08-22T21:39:56.557Z
sensor.air_quality_monitor_co2 | 3263.0 | 2026-08-22T21:40:01.564Z
sensor.air_quality_monitor_co2 | 3556.0 | 2026-08-22T21:40:06.565Z
sensor.air_quality_monitor_co2 | 3855.0 | 2026-08-22T21:40:11.569Z
sensor.air_quality_monitor_co2 | 4182.0 | 2026-08-22T21:40:16.572Z
sensor.air_quality_monitor_co2 | 4464.0 | 2026-08-22T21:40:21.571Z
sensor.air_quality_monitor_co2 | 4717.0 | 2026-08-22T21:40:26.576Z
sensor.air_quality_monitor_co2 | 4870.0 | 2026-08-22T21:40:31.577Z
sensor.air_quality_monitor_co2 | 4946.0 | 2026-08-22T21:40:36.577Z
sensor.air_quality_monitor_co2 | 4981.0 | 2026-08-22T21:40:41.580Z
sensor.air_quality_monitor_co2 | 5023.0 | 2026-08-22T21:40:46.584Z
sensor.air_quality_monitor_co2 | 5032.0 | 2026-08-22T21:40:51.584Z
sensor.air_quality_monitor_co2 | 5038.0 | 2026-08-22T21:40:56.581Z
sensor.air_quality_monitor_co2 | 5037.0 | 2026-08-22T21:41:01.591Z
sensor.air_quality_monitor_co2 | 5033.0 | 2026-08-22T21:41:06.595Z
sensor.air_quality_monitor_co2 | 5025.0 | 2026-08-22T21:41:11.594Z
sensor.air_quality_monitor_co2 | 4997.0 | 2026-08-22T21:41:16.595Z
sensor.air_quality_monitor_co2 | 4974.0 | 2026-08-22T21:41:21.595Z
sensor.air_quality_monitor_co2 | 4933.0 | 2026-08-22T21:41:26.596Z
sensor.air_quality_monitor_co2 | 4886.0 | 2026-08-22T21:41:31.596Z
sensor.air_quality_monitor_co2 | 4857.0 | 2026-08-22T21:41:36.599Z
sensor.air_quality_monitor_co2 | 4820.0 | 2026-08-22T21:41:41.601Z
sensor.air_quality_monitor_co2 | 4780.0 | 2026-08-22T21:41:46.602Z
sensor.air_quality_monitor_co2 | 4731.0 | 2026-08-22T21:41:51.602Z
sensor.air_quality_monitor_co2 | 4698.0 | 2026-08-22T21:41:56.598Z
sensor.air_quality_monitor_co2 | 4646.0 | 2026-08-22T21:42:01.607Z
sensor.air_quality_monitor_co2 | 4576.0 | 2026-08-22T21:42:06.607Z
sensor.air_quality_monitor_co2 | 4537.0 | 2026-08-22T21:42:11.607Z
sensor.air_quality_monitor_co2 | 4514.0 | 2026-08-22T21:42:16.612Z
sensor.air_quality_monitor_co2 | 4494.0 | 2026-08-22T21:42:21.614Z
sensor.air_quality_monitor_co2 | 4439.0 | 2026-08-22T21:42:26.618Z
sensor.air_quality_monitor_co2 | 4410.0 | 2026-08-22T21:42:31.622Z
sensor.air_quality_monitor_co2 | 4376.0 | 2026-08-22T21:42:36.623Z
sensor.air_quality_monitor_co2 | 4336.0 | 2026-08-22T21:42:41.628Z
sensor.air_quality_monitor_co2 | 4299.0 | 2026-08-22T21:42:46.635Z
sensor.air_quality_monitor_co2 | 4267.0 | 2026-08-22T21:42:51.638Z
sensor.air_quality_monitor_co2 | 4230.0 | 2026-08-22T21:42:56.625Z
sensor.air_quality_monitor_co2 | 4195.0 | 2026-08-22T21:43:01.640Z
sensor.air_quality_monitor_co2 | 4153.0 | 2026-08-22T21:43:06.639Z
sensor.air_quality_monitor_co2 | 4128.0 | 2026-08-22T21:43:11.642Z
sensor.air_quality_monitor_co2 | 4080.0 | 2026-08-22T21:43:16.642Z
sensor.air_quality_monitor_co2 | 4049.0 | 2026-08-22T21:43:21.647Z
sensor.air_quality_monitor_co2 | 4016.0 | 2026-08-22T21:43:26.653Z
sensor.air_quality_monitor_co2 | 3979.0 | 2026-08-22T21:43:31.656Z
sensor.air_quality_monitor_co2 | 3947.0 | 2026-08-22T21:43:36.662Z
sensor.air_quality_monitor_co2 | 3920.0 | 2026-08-22T21:43:41.675Z
sensor.air_quality_monitor_co2 | 3887.0 | 2026-08-22T21:43:46.678Z
sensor.air_quality_monitor_co2 | 3862.0 | 2026-08-22T21:43:51.684Z
sensor.air_quality_monitor_co2 | 3833.0 | 2026-08-22T21:43:56.681Z
sensor.air_quality_monitor_co2 | 3814.0 | 2026-08-22T21:44:01.686Z
sensor.air_quality_monitor_co2 | 3763.0 | 2026-08-22T21:44:06.687Z
sensor.air_quality_monitor_co2 | 3745.0 | 2026-08-22T21:44:11.694Z
sensor.air_quality_monitor_co2 | 3705.0 | 2026-08-22T21:44:16.704Z
sensor.air_quality_monitor_co2 | 3649.0 | 2026-08-22T21:44:21.706Z
sensor.air_quality_monitor_co2 | 3629.0 | 2026-08-22T21:44:26.707Z
sensor.air_quality_monitor_co2 | 3605.0 | 2026-08-22T21:44:31.710Z
sensor.air_quality_monitor_co2 | 3598.0 | 2026-08-22T21:44:36.712Z
sensor.air_quality_monitor_co2 | 3565.0 | 2026-08-22T21:44:41.722Z
sensor.air_quality_monitor_co2 | 3540.0 | 2026-08-22T21:44:46.730Z
sensor.air_quality_monitor_co2 | 3511.0 | 2026-08-22T21:44:51.728Z
sensor.air_quality_monitor_co2 | 3488.0 | 2026-08-22T21:44:56.720Z
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

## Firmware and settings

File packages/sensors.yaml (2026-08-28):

# ---------------------------------------------------------------------------
# Sensors: SCD41 (CO2/temp/humidity), BMP180 (temp/pressure), battery
# voltage/level, charging detection + diagnostics.
#
# BMP180/battery stay at 60s (no reason to poll faster). SCD41 polls much
# faster - see the update_interval comment right below for why.
# ---------------------------------------------------------------------------
# scd41_stop_before_sleep
#
# Both paths into deep sleep (packages/menu.yaml: the display_auto_off
# script and the manual single-click handler) send this sensor
# stop_periodic_measurement (0x3F86) on the way out. Without it deep sleep
# barely saves anything, because the SCD41 is not on the ESP32's power
# domain - the 3V3 rail stays up through sleep and the sensor just carries
# on measuring every 5s with nobody listening.
#
# The cost of that is not small. The datasheet puts one measurement at
# 243mJ, so at the 5s periodic rate that is 243mJ / 5s / 3.3V = ~14.7mA
# drawn continuously, against 0.15mA typical in idle - roughly a hundred
# times more, and more than the sleeping ESP32 by orders of magnitude.
#
# It shows up in the real captures: with a 5min sleep interval and 30s
# awake - a tenth of the time powered up - the measured discharge was only
# ~15% slower than never sleeping at all (-0.070 V/h against -0.082 to
# -0.089 V/h). Working back from the always-on figure gives ~34mA total,
# which is about the ESP with WiFi plus exactly this sensor.
#
# There is independent evidence the sensor really does keep running: the
# temperature transient measured at every wake is ~5.5C, far bigger than
# the ~2C seen from a cold start, and that only makes sense if the chip
# stayed self-heated through the sleep - which it can only do by measuring.
# See data/2026-08-22-cesta-wake-cycles/.
#
# Safe to send even though ESPHome's own setup() sends stop again on the
# next boot, i.e. to an already-idle sensor: that is exactly what happens
# on every cold start (the SCD4x powers up idle), and cold starts work -
# see data/2026-08-22-cold-start/.
sensor:
  - platform: scd4x
    id: scd41_hub
    address: 0x62
    # Fast on purpose - NOT just "fresher data". The old 60s interval left
    # a CESTA wake cycle (deep sleep, display auto-off/sleep at 30s -
    # packages/menu.yaml) going back to sleep before a single real CO2
    # reading arrived. Bad for the alarm below, and HA never saw a fresh
    # reading in CESTA either - every published value stayed the boot-time
    # cached one.
    #
    # Why that happened is worth stating correctly, because an earlier
    # version of this comment got it wrong: it is NOT that the first
    # update() waits a full interval. ESPHome's scheduler starts an
    # interval at now + a random offset in [0, min(interval/2, 5000ms))
    # (Scheduler::calculate_interval_offset_), so the first poll lands
    # within 5s of setup either way. The real problem is that this early
    # poll arrives before the SCD41 flags data-ready - the driver spends
    # ~1.5s on its own stop/configure/start sequence and the sensor needs
    # another ~5s after that - so it publishes nothing, and the NEXT poll
    # is a full interval later. At 60s that lands well after the device
    # already went to sleep.
    #
    # Confirmed against a real capture (data/2026-08-22-power-on-warmup/):
    # BMP180 at its 60s interval published ~3s after boot, while the SCD41
    # at 10s only managed its first value at 11s - exactly the skipped
    # first poll.
    #
    # 5s == the SCD41's own internal sampling rate in periodic measurement
    # mode, so this is as fast as the sensor has anything new to say and
    # costs no extra sensor power - we just stop throwing readings away.
    # It puts ~5 readings in the 30s CESTA window (first at ~11s, then
    # every 5s), which is what the alarm's arming rule below needs to judge
    # whether the readings have settled and still leave room to fire.
    update_interval: 5s
    # Compiled default - stays ON unless overridden. Actually toggling ASC
    # at runtime (menu ASC KALIBRACE item) needs raw I2C, since ESPHome's
    # scd4x component only exposes this as a compile-time key - see the
    # on_boot step in air-quality-monitor.yaml and its comment for why.
    automatic_self_calibration: true
    altitude_compensation: 435m
    # Static rest-offset (self-heating with the device idle, not charging).
    # Measured against a reference thermometer, not carried over any more:
    # data/2026-08-22-rest-offset/, on battery with the charger unplugged,
    # 49min to settle, three readings five minutes apart. The old v1 value
    # of 5.6 left the reading +1.07C high, so it goes to 6.7.
    #
    # Both sanity checks on that measurement passed - the two sensors were
    # 0.35C apart (expected 0.3-0.5 at rest) and the BMP180 moved only
    # 0.09C across the three readings, so the room was not drifting under
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

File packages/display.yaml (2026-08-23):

font:
  - file: "gfonts://Roboto"
    id: font_big
    size: 16
    # "~" is the warm-up marker on the temperature pages. It has to be in
    # this glyph list or it simply won't render - a glyph-restricted font
    # silently drops anything not listed.
    glyphs: "0123456789.-%~"
  - file: "gfonts://Roboto"
    id: font_label
    size: 10
  # Settings-menu state value (ZAPNUTO/VYPNUTO/DOMA/CESTA/CUSTOM/"10 MIN") -
  # bigger than font_label for legibility, full charset (not glyph-limited
  # like font_big) since these are words, not just numbers.
  - file: "gfonts://Roboto"
    id: font_menu_value
    size: 14

# ---------------------------------------------------------------------------
# Display, tuned for 128x32 (no clipping). Render order: settings menu, then
# the CO2 alarm screen (if active), then the normal 5-page sensor rotation.
#
# Sensor pages always prefer a sensor's live state and fall back to the
# last-known-good cached value (packages/globals.yaml, restore_value: true)
# until the first fresh reading of this boot lands - so the display shows
# correct-looking values immediately after power-on/wake instead of "--" or
# a loading bar. Cached values persist across deep sleep AND a full power
# cycle via the battery switch, since they're flash-backed.
# ---------------------------------------------------------------------------
display:
  - platform: ssd1306_i2c
    id: oled_display
    address: 0x3C
    model: "SSD1306 128x32"
    update_interval: 1s
    lambda: |-
      if (!id(display_on)) return;

      // --- Settings menu (hold button 5s+ to enter) ---
      //
      // Layout mirrors the normal sensor pages below (label top-left,
      // big value centered, position dots bottom) instead of stacking
      // name/state/hint as three separate text lines - that older layout
      // let a long hint string ("5s: dalsi hodnota") run underneath and
      // collide with the position dots, and lowercase descenders in the
      // hint ("vypnout"/"zapnout"/"prepnout") got clipped by the display's
      // bottom edge. Dropping the per-item hint (the 5s-hold convention is
      // the same for every item - see README "Menu a presety") removes
      // both problems instead of just repositioning them.
      if (id(in_settings_menu)) {
        const char *item_name;
        char state_buf[16];
        switch (id(settings_menu_index)) {
          case 0: {  // REZIM - must mirror the match logic in
                     // packages/menu.yaml's 5s-hold handler exactly.
            item_name = "REZIM";
            bool is_doma = id(ha_connection_enabled)
                && !id(deep_sleep_mode_enabled)
                && !id(co2_alarm_enabled)
                && id(asc_enabled);
            bool is_cesta = !id(ha_connection_enabled)
                && id(deep_sleep_mode_enabled)
                && id(sleep_interval_minutes) == 10
                && id(co2_alarm_enabled)
                && !id(asc_enabled);
            if (is_doma)       snprintf(state_buf, sizeof(state_buf), "DOMA");
            else if (is_cesta) snprintf(state_buf, sizeof(state_buf), "CESTA");
            else               snprintf(state_buf, sizeof(state_buf), "CUSTOM");
            break;
          }
          case 1:  // HA připojení (WiFi)
            item_name = "HA PRIPOJENI";
            snprintf(state_buf, sizeof(state_buf), id(ha_connection_enabled) ? "ZAPNUTO" : "VYPNUTO");
            break;
          case 2:  // Interval hlubokého spánku
            item_name = "INTERVAL SPANKU";
            snprintf(state_buf, sizeof(state_buf), "%d MIN", id(sleep_interval_minutes));
            break;
          case 3:  // Automatický hluboký spánek
            item_name = "DEEP SLEEP";
            snprintf(state_buf, sizeof(state_buf), id(deep_sleep_mode_enabled) ? "ZAPNUTO" : "VYPNUTO");
            break;
          case 4:  // Lokální CO2 alarm
            item_name = "CO2 ALARM";
            snprintf(state_buf, sizeof(state_buf), id(co2_alarm_enabled) ? "ZAPNUTO" : "VYPNUTO");
            break;
          case 5:  // SCD41 automatic self-calibration
            item_name = "ASC KALIBRACE";
            snprintf(state_buf, sizeof(state_buf), id(asc_enabled) ? "ZAPNUTO" : "VYPNUTO");
            break;
          default:
            item_name = "?";
            snprintf(state_buf, sizeof(state_buf), "-");
            break;
        }

        // Top: item name (left) + position "i/N" (right) - same top-row
        // slot the sensor pages use for their countdown/[STAY] indicator.
        it.print(2, 0, id(font_label), item_name);
        char pos_buf[6];
        snprintf(pos_buf, sizeof(pos_buf), "%d/%d", id(settings_menu_index) + 1, id(settings_item_count));
        it.print(126, 0, id(font_label), TextAlign::TOP_RIGHT, pos_buf);

        // Thin separator so the name row reads as a header, not just text
        // floating above the value.
        it.horizontal_line(0, 11, 128);
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

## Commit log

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2026-08-21 Redesign firmware for v2: packages, presets, CO2 alarm, flat charging offset
    Splits the single air-quality-monitor.yaml into packages/ (globals,
    sensors, display, menu) for readability, and reworks the parts that were
    broken or unreliable on v1:
    - Settings menu gets a DOMA/CESTA preset system (REZIM item) plus
    individual overrides, with CUSTOM shown when settings no longer match
    either preset.
    - New CO2 ALARM toggle: when the device has no HA connection (CESTA/away
    from home), a dangerous CO2 reading forces the OLED on with a blinking
    warning instead of relying on HA, which won't be reachable.
    - Last-known-good sensor/battery readings are now cached to flash
    (restore_value globals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
    [display.yaml, sensors.yaml]
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2026-08-21 Redesign settings menu layout; fix battery voltage noise spikes
    Menu (packages/display.yaml): the old 3-line layout (name/state/hint) let
    a long hint string run under the position dots and collide with them, and
    lowercase descenders in the hint text ("vypnout"/"zapnout"/"prepnout")
    got clipped by the display's bottom edge - both reported against the
    real hardware. Reworked to mirror the sensor pages' own layout instead:
    name + "i/N" position on top, a bigger centered value in the middle
    (new font_menu_value, 14pt, full charset), dots on the bottom with
    nothing else drawn on that row anymore. Dropped the per-item hint text
    entirely rather than just repositioning it - the 5s-hold convention is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
    [display.yaml, sensors.yaml]
2026-08-21 docs: v2 rewire - voltage divider top leg now taps battery B+ directly
    Hardware change (user rewired, not a firmware change): the 220k leg of
    the battery voltage divider now connects straight to the cell's B+
    terminal instead of the XIAO BAT+ pin/TP4056 OUT+. The 100k/GND leg is
    unchanged (still XIAO GND = TP4056 OUT-).
    Corrects something I got wrong two commits ago: I'd predicted the
    charger-connect voltage jump was purely the cell's own internal
    resistance and wouldn't be affected by tap point. Real-world test after
    the rewire shows the jump shrank/mostly disappeared - so the v1 tap
    point was carrying real extra series resistance (module traces/contacts)
    on top of the cell's own IR drop,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
    [sensors.yaml]
2026-08-21 Add SCD41 ASC on/off menu toggle via raw I2C
    New menu item 6 (ASC KALIBRACE) for the CESTA/no-HA use case: sleeping in
    a car overnight without seeing fresh air risks the SCD41's automatic
    self-calibration drifting its baseline over a long enough stretch. ESPHome's
    scd4x component only exposes automatic_self_calibration as a compile-time
    key - no runtime action exists - so this required raw I2C:
    - packages/sensors.yaml: scd4x block gets `id: scd41_hub` so its
    write_command() (inherited from sensirion_common::SensirionI2CDevice,
    handles the CRC8 itself) is reachable from a lambda.
    - air-quality-monitor.yaml: new on_boot step (priority -150) sends the
    SCD4x stop/set-ASC/restart command s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
    [display.yaml, sensors.yaml]
2026-08-21 Fix charging never being detected - noise rejection didn't reach the detector
    Real bug, confirmed against user's real hardware: Charging stayed OFF for
    an entire real charge session even though the published Battery Voltage
    rose cleanly the whole time. Root cause: the median-of-3 outlier filter
    added earlier only smoothed the PUBLISHED entity value (an ESPHome
    `filters: median` step runs after the lambda returns) - the is_charging
    trend/confirm-count state machine inside the lambda still read the raw,
    un-smoothed reading directly. A single-sample noise dip (confirmed
    present in data/votaz1.csv, ~0.13V) could reset charge_confirm_count
    right as it was building toward the required 3-in-a-row,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
    [sensors.yaml]
2026-08-21 CO2 alarm: skip unsettled first reading, fix a hidden pre-existing wake-timing bug
    User's ask: don't let the CO2 alarm trip on the "wild" readings right
    after power-on. Added a settle-gate (new co2_reading_settled global,
    resets every boot) that skips alarm evaluation on the very first CO2
    reading of each boot, arming from the second reading onward.
    While designing the timing for that, found a real pre-existing bug this
    touches on directly: ESPHome's PollingComponent only fires its FIRST
    update() after one full update_interval has elapsed since boot (verified
    against ESPHome's own scheduler source, not assumed). With scd4x's old
    `update_interval: 60s`, a CESTA wake cycle - deep sleep, displ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
    [sensors.yaml]
2026-08-22 Verify firmware against real DOMA data; fix BMP180 glitch, gate CO2 alarm on stability
    Hodinový HA export z běžícího v2 firmwaru (data/doma rezim/, lokální)
    prošel rozborem. Co potvrdil:
    - Teplotní offsety z v1 na novém krytu platí - SCD41 25.09-25.27 C celou
    hodinu bez náběhu, BMP180 v rozdílu 0.44 C. TODO komentáře zmírněné.
    - Detekce nabíjení nedělá false-positive: simulace nad reálnou vybíjecí
    řadou dala max trend -0.0003 V proti prahu +0.015 V.
    - Median-of-3 na napětí funguje (22 z 64 čtení bit-identických s
    předchozím = podpis mediánu). Zbytkový šum ~0.018 V.
    A jeden reálný bug: BMP180 pustil v 01:56:54Z jedno úplně vedlejší čtení -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
    [display.yaml, sensors.yaml]
2026-08-22 Add measurement data to the repo, renamed into dated capture folders
    Data byla doteď v .gitignore. Ale skoro každé číslo v README a většina
    konstant ve firmwaru z těch záznamů přímo vychází, takže mít je jinde než
    u kódu nedává smysl - bez nich se nedá ověřit, odkud se ta čísla vzala.
    Přejmenováno z ad-hoc názvů (votaz1.csv, "doma rezim/temp scd.csv") do
    struktury RRRR-MM-DD-co-se-měřilo/veličina.csv:
    2026-08-21-v1-charger-connect/ (bylo votaz1.csv)
    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
    [battery-voltage.csv, charging.csv, co2.csv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]
2026-08-22 Measure the warm-up curve from real data; correct a false claim about ESPHome's scheduler
    Rozbor záznamu po zapnutí (data/2026-08-22-power-on-warmup/, 26 min).
    Křivka má dvě fáze, které spolu nesouvisí:
    0-1.5 min SCD41 hlásí +2.5 C nad plató, vlhkost -14 %, CO2 +56 ppm
    1.5-3 min projde správnou hodnotou a podstřelí o 0.5 C
    3-15 min teprve tady se zahřívá krabička, tau 3.1 / 5.9 min
    Ustálení: SCD41 do +-0.1 C od 12.0 min, BMP180 od 9.0 min, vlhkost do
    +-0.5 % od 10.9 min.
    WARMUP_MS 30 -> 20 min. Není to odečet z grafu: ten záznam nebyl studený
    start (BMP180 vyrostl o 0.37 C, ale jeho klidový offset je 1.74 C, takže
    vychladlý box by musel vyrůst zhruba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
    [battery-voltage.csv, co2.csv, humidity.csv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]
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2026-08-22 Zahodit start-up transient SCD41; WARMUP_MS 20 -> 45 min podle studeného startu
    Studený start (data/2026-08-22-cold-start/, vypnuté ~1h předtím, pak 6.5h
    záznam až do vybití baterky) odpověděl na tři věci najednou.
    1) Zahřívání trvá ~45 min, ne 20. BMP180 se ustálí kolem 24.15 C, zbývající
    chyba je -1.11 C v 10. minutě, -0.58 ve 20., -0.34 ve 30., -0.18 ve 40. a
    -0.06 v 50. Časová konstanta 13-15 min, ustálení ~3 tau.
    Předchozích 20 min bylo moje chyba: vzniklo extrapolací ze záznamu, který
    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
    [battery-voltage.csv, co2.csv, humidity.csv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]
2026-08-22 Teplo z nabíjení změřeno na +3.7 C: neopravovat konstantou, jen označit
    Nabíjení z úplně vybité baterky se zapojeným referenčním teploměrem
    (data/2026-08-22-charging-from-empty/, 4 h). Poprvé je k dispozici nezávislá
    reference, takže se dá říct nejen "o kolik se to změnilo", ale i "kde to je".
    Teplo z nabíjení nad ustáleným stavem: +3.4 C ve 30. minutě, +3.7 ve 40.
    (vrchol), +3.6 v 60., +1.7 ve 100., +0.3 ve 150., nula v 170. Referenční
    teploměr se přitom držel na 23.8-24.2 C. Stejný tvar na BMP180 (+3.8), takže
    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
    [all-sensors.csv]
2026-08-22 Displej nechat zhasnutý při probuzení časovačem; potvrzeno, že SCD41 skok se opakuje každé probuzení
    Test devíti cyklů probuzení (data/2026-08-22-cesta-wake-cycles/) odpověděl
    na otázku, která byla od studeného startu otevřená: ano, startovní skok
    SCD41 se opakuje při KAŽDÉM probuzení z deep sleepu, a je větší než při
    studeném startu.
    Pokaždé stejně: SCD41 startuje ~5.5 C nad BMP180 a za 10 s spadne o
    0.72-0.76. Rozptyl prvního rozdílu přes všech devět probuzení je 5.36 až
    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
    [all-sensors.csv]
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2026-08-22 Kalibrace teploty uzavřena: offsety změřeny proti referenčnímu teploměru
    Konečně měřeno za správných podmínek - nabíječka i USB odpojené, DOMA,
    displej zhasnutý, 49 min na ustálení, tři odečty po pěti minutách, všechny
    shodně 23.9 C. Odpojení USB bylo to podstatné: během flashování jde XIAO
    z 5 V, na baterce z ~4.1 V, a ten rozdíl se pálí v LDO jako teplo. Tohle
    zkreslilo předchozí pokus, kde byla nabíječka zapojená.
    SCD41 četl +1.07 C -> temperature_offset 5.6 -> 6.7
    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
    [all-sensors.csv]
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2026-08-22 HANDOFF.md do repa; záznam dýchacího testu potvrzuje nové offsety
    HANDOFF.md byl doteď v .gitignore na dřívější pokyn, uživatel to změnil.
    Odstraněn z .gitignore, opraveny jeho vlastní zmínky o tom, že do repa
    nepatří, a CLAUDE.md přepsán ze "nikdy nepatří do gitu" na "udržuj ho
    aktuální".
    data/2026-08-22-breath-test/ je první záznam na novém firmwaru a rovnou
    potvrzuje kalibraci: před dýcháním je rozdíl SCD41 - BMP180 jen -0.06 až
    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
    [all-sensors.csv]
2026-08-22 Druhé nabíjení shodilo detekci konce - přeladit přes oba záznamy
    Nový záznam (nabíjení ze 64 % s už ustálenou krabičkou) odhalil, že
    pravidlo "vysoko a bez pohybu" bylo naladěné jen na jeden dřívější
    záznam. Tam napětí po dobití skončilo na 4.120 V, tady na 4.083 -
    tedy pod prahem FULL_V 4.10, takže pravidlo nesepnulo ani jednou a
    Charging viselo zapnuté celou hodinu.
    Absolutní hladina napětí tedy negeneralizuje (37 mV rozdíl na stejném
    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
    [all-sensors.csv]
2026-08-23 ASSEMBLY.md přepsáno na kryt v2
    Starý postup platil pro v1 a měl na to nahoře varování. Nový je podle
    skutečné v2: PETG (Aurapol) místo PLA, větší a tvrdší kryt, oba teplotní
    senzory ve vlastním spodním kompartmentu, který se zatavuje záklopkou -
    tedy oddělené přepážkou od baterky, TP4056 i ESP32.
    Další změny proti v1: tlačítko se symbolem napájení se natavuje přímo na
    přední kryt (dřív na stranu s baterií), volitelně s pružinkou; TP4056 jde
    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
    [case v2.3mf]
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2026-08-23 Noční záznam v CESTA: výdrž sedí s rezervou, teplota je o 3.55 °C vedle
    12.4 h v uspávaném režimu (interval 10 min, HA připojení nechané zapnuté,
    jinak by se nic nezaznamenalo), krabička na začátku nahřátá, baterka plná.
    72 probuzení, perioda 625.5 s, ~5 čtení CO2 v každém okně. Na konci ruční
    odečet referenčního teploměru: 22.5 °C.
    Zavřené otázky:
    - Výdrž -0.0076 V/h (fit od +2 h, rezidua 6.8 mV). Cíl byl -0.02, takže
    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
    [all-sensors.csv]
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2026-08-23 Detekce nabíjení dostane ve spánku vlastní, jednodušší větev
    EWMA pravidlo potřebuje řadu vzorků; ve spánku dorazí za probuzení jeden
    a pak se zařízení rebootuje, takže baseline nikdy nenaběhne a Charging
    nemohlo sepnout vůbec. Ve spánku proto místo něj krok proti minulému
    probuzení: nabíjení přidá ~+40 mV za deset minut, vybíjení ubere
    ~1.3 mV, a medián drží šum na 2.16 mV.
    Odpadá tím i dead zone EWMA (konstantní napětí -> trend 0, tedy mezi
    prahy), kvůli které vznikla heuristika FULL_V/plochost a dvě kola
    ladění. Krok dead zone nemá: konstantní napětí dá krok 0, což je pod
    uvolňovacím prahem.
    Prahy nejsou od oka. data/threshold-sweep.p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
    [sensors.yaml]
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2026-08-23 Ověřovací záznam po opravách uspávaného režimu - 4 ze 6 testů prošlo
    2.8 h v uspávaném režimu s firmwarem z téhle větve, 16 probuzení,
    referenční teploměr vedle. Protějšek nočního záznamu cesta-baseline:
    stejná krabička, stejný interval, jen opravený firmware.
    Co se ověřilo:
    - Offset. Skok +2.676 °C při prvním probuzení ze spánku proti
    konstantě 2.46 - zbytek je skutečný drift raw za těch 10 min. Skok
    je vidět přímo v datech, protože flash boot je sám cold_boot a
    odečítá. Proti referenci -0.90 °C (sd 0.18) tam, kde ta samá data
    bez opravy dávají -3.36. Spec předpovídal -1.09.
    - Procenta baterky. 0 unknown za 16 probuzení proti 2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
    [all-sensors.csv]
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2026-08-28 Pokus o CO2 alarm ve spánku: nesepnul, chybělo 695 ppm
    Dvě obavy před testem byly obě mimo. Krabička drží vydýchaný vzduch
    s časovou konstantou ~8.9 min, ne minutu dvě - dýchnutí dvě minuty před
    probuzením senzor pořád viděl skoro celé (2305 ppm, špička zpětně ~2580).
    A armovací pravidlo se ve 30s okně stihne: pět čtení mělo rozptyl 9 ppm
    proti prahu stability 150, takže se alarm ozbrojil na třetím čtení a měl
    dvě na sepnutí.
    Nesepnul jediný důvod: jedno dýchnutí zvedne hladinu asi o 1400 ppm nad
    základ, potřeba je 1850. Příště víc dýchnutí, ideálně těsně před
    probuzením.
    [co2.csv]
